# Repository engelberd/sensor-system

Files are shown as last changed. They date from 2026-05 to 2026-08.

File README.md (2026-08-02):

# sensor-system

This repository contains the full Sensor System project:

- `hardware/` for KiCad PCB projects, parts, footprints, and hardware notes
- `node/` for the Pico firmware and bootloader artifacts
- `host/` for recorder, configurator, supervisor, dashboards, and deployment files

Current product version: **0.4.1**.

For day-to-day use, see the Polish
[operator guide](docs/INSTRUKCJA-OPERATORA.md). For a new host computer, run:

```bash
./host/tools/setup_host.sh rpi-sanok
```

For a macOS KiCad, firmware and host-development workstation, follow
[the macOS setup guide](docs/SETUP-MACOS.md), install declared tools with
`brew bundle --file Brewfile`, and run `./tools/check_macos.sh`.

The generated, ignored `host/system_config.json` extends a tracked profile from
`host/configs/systems/`. Product-wide defaults live in
`host/configs/common.json`; stable channel and sensor facts live in the system
profile; device paths, storage overrides and temporary disabled channels remain
in the local overlay. See [the repository structure](docs/REPOSITORY-STRUCTURE.md)
and validate an installation with:

```bash
./hostctl doctor --config host/system_config.json
```

Release validation and publication are described in
[RELEASING.md](RELEASING.md), and notable changes are listed in
[CHANGELOG.md](CHANGELOG.md).

Local runtime output has one predictable layout:

- `var/recordings/` for new measurements
- `var/archive/` for compacted archives
- `var/log/` for host logs and events
- `var/tmp/` for temporary artifacts
- `/run/sensor-system/` for locks, commands and live status

These directories are not versioned. Use `./hostctl paths` to display the
effective paths for the active host configuration.

Every installed node has an immutable hardware revision. Revision `2` is the
currently installed wiring (SCK 14, MOSI 15, DRDY 11, INT1 10, no DE GPIO),
while revision `1` uses SCK 10, MOSI 11, DRDY 14, INT1 15 and DE on GPIO2.
Node IDs and sensor settings remain runtime configuration independent of that
revision.

## Repository Notes

In this Codex workspace the top-level `.git/` path is reserved by the
environment, so repository metadata lives in `.git-main/` and the local wrapper
`./sgit` should be used instead of plain `git`.

Suggested day-to-day workflow in this workspace:

1. Make changes locally in this repository.
2. Use `./sgit ...` for repository commands in this environment.
3. Commit before flashing or deploying to another device.
4. Push to your remote.
5. On the Raspberry Pi host, run `git pull`, build from `node/`, and flash the selected artifact.

## Local Bring-Up On A New Computer

If you are building and flashing from a local Linux or macOS machine instead of
the Raspberry Pi host:

1. Clone the repository and enter it.
2. Install the Pico SDK and toolchain.
3. Build `node/`.
4. Flash `node/build/sensor-system-node-factory.uf2` onto a brand-new Pico 2.
5. Create `host/.venv` and install host requirements.
6. Use `./hostctl config` to commission the node over RS485.

Example setup for a clean local checkout:

```bash
git clone git@github.com:engelberd/sensor-system.git
cd sensor-system
git clone https://github.com/raspberrypi/pico-sdk.git
export PICO_SDK_PATH=$PWD/pico-sdk
python3 -m venv host/.venv
host/.venv/bin/python -m pip install -r host/requirements-recorder.txt
```

The local `pico-sdk/` checkout is intentionally ignored and is not a submodule.
Each build host may keep the SDK elsewhere and point `PICO_SDK_PATH` to it.

On macOS with Homebrew, the typical firmware toolchain is:

```bash
brew install cmake picotool arm-none-eabi-gcc
```

Build the node firmware with explicit compiler paths when needed:

```bash
cmake -S node --preset board-v2 \
  -DCMAKE_C_COMPILER=/opt/homebrew/bin/arm-none-eabi-gcc \
  -DCMAKE_CXX_COMPILER=/opt/homebrew/bin/arm-none-eabi-g++ \
  -DCMAKE_ASM_COMPILER=/opt/homebrew/bin/arm-none-eabi-gcc
cmake --build node/build
```

For a V1 board use `cmake -S node --preset board-v1` followed by
`cmake --build node/build.v1`. Never reuse one build directory for both board
revisions.

The most important output files are:

- `node/build/sensor-system-node-factory.uf2` for first-time USB/BOOTSEL flashing
- `node/build/sensor-system-node.uf2` as the general full-image UF2
- `node/build/sensor-system-node-update-package.json` for later RS485 updates

Further details live in:

- [hardware/README.md](hardware/README.md)
- [node/README-bootloader.md](node/README-bootloader.md)
- [host/README-product.md](host/README-product.md)
- [host/README-deploy.md](host/README-deploy.md)

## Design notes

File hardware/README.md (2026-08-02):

# Hardware

Hardware design files for the Sensor System project.

Current KiCad project:

- `KiCad - node V2/RP2350.kicad_pro`

The directory name is historical. This is an unreleased custom-board design,
not the definition of the V2 boards installed in Sanok. Installed V2 wiring is
defined by `node/config/board_profile.h`: SCK 14, MOSI 15, MISO 12, CS 13,
DRDY 11, INT1 10 and no firmware-controlled DE pin. Do not change the firmware
revision map from the in-progress KiCad project without a physical bring-up and
an explicit new board revision.

## Repository layout

This project should stay as one GitHub repository for now:

- `hardware/` - KiCad projects, PCB notes, parts, footprints, manufacturing files
- `node/` - RP2350/Pico firmware
- `host/` - host tools, recorder, dashboards, deployment files

This is a monorepo layout. It is simpler than a nested Git repository and makes
hardware/software changes easy to review together. A separate hardware repository
or Git submodule only starts to pay off if the PCB must be shared with a different
team, licensed differently, or released on a different schedule.

## What is tracked

Track these files:

- `*.kicad_pro`
- `*.kicad_sch`
- `*.kicad_pcb`
- project-local `*.kicad_sym` files
- project-local `*.pretty/*.kicad_mod` footprint libraries
- selected 3D models used by footprints
- documentation in this directory
- released fabrication outputs in a named release folder, if needed

Do not track these files:

- `*.kicad_prl`
- `*-backups/`
- `fp-info-cache`
- local lock/temp files
- `.DS_Store`

## Collaboration rules

- Commit before making large schematic rewires or PCB placement changes.
- Pull before opening KiCad if someone else may have pushed hardware changes.
- Avoid editing the same schematic sheet or PCB placement in parallel.
- For footprint changes, edit project-local libraries first, then update the
  board from the library and commit both the library change and board change.
- Put part decisions in `parts.md` before layout, especially when package,
  stock, or footprint choice matters.
- Put JLCPCB/LCSC assembly candidates and stock checks in `jlcpcb-parts.md`.
- Put layout/manufacturing decisions in `design-notes.md`.
- Track current work, assumptions, tasks, and completed items in `progress.md`.

## Opening the project

Open this file in KiCad:

```text
hardware/KiCad - node V2/RP2350.kicad_pro
```

If a footprint is missing, first check the project-local library:

```text
hardware/KiCad - node V2/my_footprints.pretty
```

Vendor downloads and raw imported libraries can stay locally in
`footprints.extra/`, which is ignored by Git. After checking a vendor footprint,
copy the cleaned version into `my_footprints.pretty` so everyone gets the same
reviewed footprint.

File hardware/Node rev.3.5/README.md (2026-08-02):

# RP2350 ADXL355 node hardware notes

Working notes for the first custom RP2350A board with ADXL355, USB-C
development power/data, 12 V field input, RS485, and a power architecture
biased toward a clean accelerometer supply.

## Design goals

- Keep firmware changes small by staying close to Raspberry Pi Pico 2/RP2350A.
- Give ADXL355 the quietest practical supply and layout environment.
- Allow development from USB-C without a 12 V supply.
- Allow normal field operation from 12 V.
- Prevent backfeeding between USB VBUS and the 12 V/buck input.
- Keep the schematic easy to manufacture externally, even if components are small.

## Proposed power tree

```text
12V_IN
  -> input fuse/PTC
  -> TVS to GND
  -> reverse polarity protection
  -> TPS62175 buck, 12 V to 5V_BUCK

USB-C VBUS
  -> optional fuse/filter
  -> TPS2121 IN2

5V_BUCK
  -> TPS2121 IN1

TPS2121 OUT = 5V_SYS
  -> TLV75733 -> 3V3_DIG
  -> low-noise LDO -> 3V3_ADXL_PRE
      -> ferrite / 0R option -> 3V3_ADXL
```

Recommended source priority:

- `IN1`: `5V_BUCK` from 12 V, main/field source.
- `IN2`: `USB_5V`, fallback/development source.
- `OUT`: `5V_SYS`.

This means that when both 12 V and USB-C are connected, the board should run
from 12 V while USB is used for data/debug. Exact TPS2121 priority and threshold
resistors must be set from the datasheet during schematic entry.

## Candidate BOM and KiCad mapping

| Block | Candidate part | KiCad symbol | KiCad footprint |
|---|---|---|---|
| MCU | RP2350A | `MCU_RaspberryPi:RP2350A` | `Package_DFN_QFN:QFN-60-1EP_7x7mm_P0.4mm_EP3.4x3.4mm_ThermalVias` |
| QSPI flash | W25Q128JVS, 16 MiB, SOIC-8 | `Memory_Flash:W25Q128JVS` if available, otherwise import/vendor symbol | `Package_SO:SOIC-8_3.9x4.9mm_P1.27mm` |
| Accelerometer | ADXL355BEZ-RL7, LCSC C515892 | local `ADXL355BEZ` | local `E-14-1_ADI` |
| Input PTC | PTS181212V150 | `Device:Fuse` / `Device:Polyfuse` | likely `Fuse:Fuse_1812_4532Metric` or vendor footprint |
| Input TVS | SM6T12A | `Diode:TVS` | usually SMB/SMA package; verify exact package before layout |
| Reverse protection | SS14-E3/61T, LCSC C47460 | `Diode:Schottky` | usually `Diode_SMD:D_SMA` / verify exact package |
| Buck 12 V to 5 V | TPS62175DQCR, LCSC C32097 | `Regulator_Switching:TPS62175DQC` | use TI DQC/VSON-10 footprint; verify against datasheet |
| Power mux | TPS2121RUXR, LCSC C485916 | local `TPS2121RUXR` | local `RUX0012A` |
| 3V3_DIG LDO | TLV75733 | `Regulator_Linear:TLV75733PDBV` or package-specific variant | `Package_TO_SOT_SMD:SOT-23-5` for DBV variant |
| 3V3_DIG alternative | AP2112K-3.3 | `Regulator_Linear:AP2112K-3.3` | `Package_TO_SOT_SMD:SOT-23-5` |
| 3V3_ADXL LDO | TPS7A2033 or ADP150-3.3 | `Regulator_Linear:TPS7A20xxxDBV` or imported ADP150 | `Package_TO_SOT_SMD:SOT-23-5` or exact vendor package |
| ADXL supply filter | MPZ2012S601AT000, 600R @ 100 MHz, 0805 | `Device:Ferrite_Bead` | `Inductor_SMD:L_0805_2012Metric` |
| RS485 TVS | CDSOT23-SM712 | `Diode:SM712_SOT23` | `Package_TO_SOT_SMD:SOT-23` |
| RS485 transceiver | THVD1450DR | `Interface_UART:THVD1450DR` | `Package_SO:SOIC-8_3.9x4.9mm_P1.27mm` |
| USB ESD | USBLC6-2SC6 or TPD2EUSB30 | `Power_Protection:USBLC6-2SC6` / `Power_Protection:TPD2EUSB30` | package-specific SOT-23-6 / X2SON, verify selected part |
| USB-C connector | select exact vertical USB-C part | `Connector:USB_C_Receptacle_USB2.0_16P` | select exact manufacturer footprint |

Local downloaded libraries already found:

```text
ADXL355 symbol:
/Users/anone/Downloads/ul_ADXL355BEZ/KiCADv6/2026-05-26_12-26-55.kicad_sym

ADXL355 footprints:
/Users/anone/Downloads/ul_ADXL355BEZ/KiCADv6/footprints.pretty/E-14-1_ADI.kicad_mod
/Users/anone/Downloads/ul_ADXL355BEZ/KiCADv6/footprints.pretty/E-14-1_ADI-L.kicad_mod
/Users/anone/Downloads/ul_ADXL355BEZ/KiCADv6/footprints.pretty/E-14-1_ADI-M.kicad_mod

TPS2121 symbol:
/Users/anone/Downloads/ul_TPS2121RUXR/KiCADv6/2026-05-26_13-55-57.kicad_sym

TPS2121 footprint:
/Users/anone/Downloads/ul_TPS2121RUXR/KiCADv6/footprints.pretty/RUX0012A.kicad_mod
```

## Input power schematic notes

Initial 12 V input chain:

```text
J_PWR.1 = +12V_IN_RAW
J_PWR.2 = GND

+12V_IN_RAW -> F1 PTC -> +12V_PROT
+12V_PROT -> D_TVS -> GND
+12V_PROT -> D_REV Schottky series -> +12V_SAFE
+12V_SAFE -> TPS62175 VIN
```

Notes:

- `PTS181212V150` is acceptable for a controlled 12 V lab input, but consider a
  higher voltage-rated fuse/PTC for field or industrial-style inputs.
- `SM6T12A` is aggressive for nominal 12 V. It is fine for a well-controlled
  12 V adapter, but for systems that can sit above 12 V, consider a 15 V or
  18 V working-voltage TVS while keeping the TPS62175 28 V input limit safe.
- `SS14` as a series reverse-protection diode is simple and acceptable for V1.
  A P-MOS/ideal-diode style reverse protector would reduce voltage drop and heat.

## Buck notes: TPS62175DQCR

Target output: `5V_BUCK`.

Required schematic items:

- VIN input ceramic capacitor close to VIN/GND.
- Additional optional bulk capacitor footprint near the protected 12 V input.
- Inductor from SW to `5V_BUCK`, selected from TPS62175 datasheet guidance.
- Output capacitor close to inductor/output return.
- Feedback divider for 5 V output.
- EN tied to `+12V_SAFE` or configured with UVLO if desired.
- PG routed to a testpoint or left according to datasheet recommendation.
- Testpoint on `5V_BUCK`.

Layout priority:

- Keep the buck hot loop tiny.
- Keep SW copper small and away from ADXL355.
- Place buck, inductor, and high-current input/output caps away from the
  accelerometer side of the board.

## USB-C and power mux notes

USB-C development connector:

```text
VBUS -> USB_5V
GND  -> GND
CC1  -> 5.1k -> GND
CC2  -> 5.1k -> GND
D+   -> USB ESD -> RP2350 USB_DP
D-   -> USB ESD -> RP2350 USB_DM
```

Power mux:

```text
TPS2121 IN1 <- 5V_BUCK
TPS2121 IN2 <- USB_5V
TPS2121 OUT -> 5V_SYS
TPS2121 GND -> GND
```

Do not leave TPS2121 control pins floating. Configure:

- priority / mode selection,
- input overvoltage thresholds,
- current limit,
- status output if useful.

Exact resistor values should be calculated directly from the TPS2121 datasheet.

## 3.3 V rails

Digital rail:

```text
5V_SYS -> TLV75733 -> 3V3_DIG
```

`3V3_DIG` powers:

- RP2350A I/O and support circuitry,
- W25Q128JVS flash,
- RS485 transceiver logic supply,
- status LED,
- digital pull-ups and test circuitry.

Analog/accelerometer rail:

```text
5V_SYS -> low-noise LDO -> 3V3_ADXL_PRE
3V3_ADXL_PRE -> MPZ2012S601AT000 / 0R option -> 3V3_ADXL
3V3_ADXL -> ADXL355 VDD and VDDIO
```

Recommendation:

- Use TLV75733 for `3V3_DIG`.
- Use a low-noise LDO such as TPS7A2033 or ADP150-3.3 for `3V3_ADXL`.
- Keep the ferrite footprint, but make it replaceable by 0R in case the filter
  resonates with ceramic capacitors or is unnecessary.

## Unreleased custom-board pin plan

Despite the historical directory name, this in-progress schematic is not the
source of truth for the V2 boards installed in Sanok. The installed V2 pin map
is maintained in `node/config/board_profile.h`.

Keep the first custom board close to the current firmware pinout.

ADXL355 SPI:

```text
SCK  -> GPIO10
MOSI -> GPIO11
MISO -> GPIO12
CS   -> GPIO13
DRDY -> GPIO14
INT1 -> GPIO15
```

RS485:

```text
UART TX -> GPIO0
UART RX -> GPIO1
DE      -> GPIO2
```

This minimizes firmware changes during bring-up.

## ADXL355 layout notes

- Place ADXL355 away from the buck inductor, SW node, USB connector, and RS485
  cable connector.
- Do not route fast digital traces under the sensor.
- Keep SPI traces short and calm; avoid unnecessarily high drive strength.
- Put local decoupling very close to ADXL355 supply pins.
- Keep a continuous ground plane under and around the sensor area.
- Consider mechanical placement early: the accelerometer measures the board and
  mounting structure, not just the electrical design.

## RS485 notes

Basic RS485 block:

```text
3V3_DIG -> THVD1450DR VCC
RP2350 UART_TX -> D
RP2350 UART_RX <- R
RP2350 GPIO_DE -> DE and /RE control as desired
A/B -> connector
A/B -> CDSOT23-SM712 -> GND
Optional 120R termination across A/B via jumper or DNP resistor
Optional failsafe bias resistor footprints if needed
```

Use `3V3_DIG`, not `3V3_ADXL`, for RS485.

## Items to verify before PCB release

- RP2350A footprint and exposed pad dimensions against the current Raspberry Pi
  hardware design files.
- ADXL355 land pattern against Analog Devices package drawing.
- Exact USB-C vertical connector part and matching footprint.
- TPS62175 DQC footprint and feedback/inductor/capacitor values.
- TPS2121 resistor configuration for priority, input thresholds, and current limit.
- Flash footprint/package for the selected W25Q128JVS ordering suffix.
- TVS working voltage against real 12 V input tolerance.
- Whether the field input should tolerate 24 V mistakes or only regulated 12 V.

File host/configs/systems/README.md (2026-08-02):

# Shared system profiles

Each tracked file in this directory describes one physical installation and
extends `../common.json`. Keep stable, non-secret facts here: channel names,
sensor settings, board revisions and expected baud rates.

A profile may have a companion Markdown file for installation-specific context
such as required external drivers, converter hardware and maintenance notes.

Do not put device paths, usernames, absolute storage paths, credentials or
temporary enable/disable decisions here. Those belong in the ignored
`host/system_config.json` on each host.

When adding a system, copy `system.example.json`, choose a stable lowercase
name, and commit the new profile so all hosts and Codex sessions share the same
source of truth.

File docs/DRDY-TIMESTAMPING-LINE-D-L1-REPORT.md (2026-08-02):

# Raport L1 timestampingu — linia D, node 1

Data: 2026-07-27
System: testowy
Zakres: jeden ADXL355, `/dev/ttyCH9344USB3`, node `1`

## Konfiguracja i obraz

- profil sprzętowy: historycznie `legacy_eval`, obecnie `board_v2`;
- piny: DRDY GPIO11, INT1 GPIO10, SPI1 GPIO12–15;
- sensor ODR: 250 Hz;
- output ODR po FIR x2: 125 Hz;
- firmware przed testem: v0.3.9;
- firmware po teście: v0.3.10, timestamping v2 ON;
- capabilities: wersja 1, Burst max 2, flags `0x0F`, 32 próbki/pakiet;
- aktywny obraz końcowy: slot B.

SHA-256 końcowych artefaktów:

- slot A:
  `cd9e885325f10a1e88e76d6d93b79bb34e77ccb56b05869423ac9ca63a240b6d`;
- slot B:
  `cced6a11a145f7f4153a01b25d4e4a3917f2015f9a1f9cdafe6f37af1ccf5c43`;
- manifest:
  `cee951c47236d5f4a4565ff5ed7bc94ceb70f3fa900116d8d0dc7497aa8b6212`.

## TimeSync

Model uzyskał `LOCKED` po pięciu obserwacjach. W krótkiej próbie:

- slope device→host: 999,988 ns/µs;
- różnica względem ideału: około −12 ppm;
- RTT pojedynczego odpytywania: około 30–50 ms;
- maksymalna niepewność zapisana w kotwicach: 15,8 ms;
- jedna stabilna `boot_epoch` w każdym przebiegu.

## Test observe — 120 s

Artefakt:
`runs/manual-tests/line-d-timing-observe/2026-07-27/`

- 14 976 próbek;
- 468 kotwic;
- 8 obserwacji synchronizacji;
- sequence bez przerw;
- zero gapów, nowych strat, overflow ringa i recovery podczas sesji;
- jedna epoka i jeden stabilny segment (`3`);
- okres próbki: min 8000,065 µs, średnio 8000,581 µs,
  max 8001,097 µs;
- HDF5 schema 5, `complete=true`.

## Test required — 90 s

Artefakty:
`runs/manual-tests/line-d-timing-required/`

- 11 264 próbki łącznie, sequence bez przerw;
- 2 560 początkowych próbek bez locka w trwałej kwarantannie `unsynced`;
- 8 704 zsynchronizowane próbki w zwykłym oknie 22:50–23:00;
- 272/272 kotwice zwykłego okna mają UTC akwizycji;
- oba HDF5 mają schema 5 i `complete=true`;
- zero gapów i nowych strat podczas sesji.

Tryb `required` został rozszerzony o osobne pliki kwarantanny dla:

- `unsynced` — brak pewnego mapowania UTC;
- `ambiguous` — przedział niepewności przecina granicę okna;
- `late` — okno zostało już sfinalizowane.

Próbki z tych kategorii nie trafiają arbitralnie do zwykłych okien, ale po
trwałym zapisie mogą zostać bezpiecznie commitowane do noda.

## Obserwacja wymagająca dalszego testu

Po każdym restarcie noda bariera fail-closed odrzucała 10–15 próbek i
wykonywała 1–2 recovery, po czym utrzymywała stabilny segment bez dalszego
wzrostu liczników. Próba zmiany kolejności uzbrajania IRQ i jawnego czyszczenia
FIFO nie poprawiła wyniku, dlatego została cofnięta.

Nie znaleziono utraty danych po wejściu w stabilny segment, ale przed rolloutem
na kolejne nody należy zarejestrować DRDY, INT1 i transakcje FIFO analizatorem
logicznym podczas pierwszych sekund startu. Do tego czasu startowy warm-up jest
jawnie kwarantannowany przez firmware i host.

## Wynik

L1 dla pojedynczego noda: warunkowo pozytywny.

- Burst v2, TimeSync, modele zegara, `observe`, `required`, HDF5 v5,
  deduplikacja i kwarantanna działają na rzeczywistym czujniku.
- Nie rozszerzać rollout’u na kolejne nody przed analizą startowego recovery.

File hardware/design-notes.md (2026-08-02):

# Hardware design notes

## Current direction

Custom RP2350A node with:

- ADXL355 accelerometer over SPI
- RS485 field bus
- USB-C development power/data
- 12 V field input
- 12 V to 5 V buck, followed by 5 V source muxing and 3.3 V rails

## Power tree

```text
12V_IN
  -> fuse/PTC
  -> TVS
  -> reverse protection
  -> TPS62175 buck -> 5V_BUCK

USB_C_VBUS -> USB_5V

5V_BUCK -> TPS2121 IN1
USB_5V  -> TPS2121 IN2
TPS2121 OUT -> 5V_SYS

5V_SYS -> TLV75733 -> 3V3_DIG
5V_SYS -> low-noise LDO -> 3V3_ADXL_PRE -> ferrite/0R -> 3V3_ADXL
```

Preferred TPS2121 behavior: 12 V/buck source has priority when both field power
and USB are connected. USB remains useful for data/debug.

## Unreleased custom-board pin plan

This plan belongs to the in-progress custom KiCad design. It is not the pin map
of the installed V2 boards; see `node/config/board_profile.h` for released
firmware profiles.

ADXL355 SPI:

```text
SCK  -> GPIO10
MOSI -> GPIO11
MISO -> GPIO12
CS   -> GPIO13
DRDY -> GPIO14
INT1 -> GPIO15
```

RS485:

```text
UART TX -> GPIO0
UART RX -> GPIO1
DE      -> GPIO2
```

## Layout priorities

- Put ADXL355 away from the buck inductor, SW node, USB connector, and RS485
  connector.
- Do not route fast digital traces under the accelerometer.
- Keep a continuous ground plane around the sensor area.
- Keep buck hot loops very small.
- Keep SW copper small and away from the analog/sensor side.
- Put local decoupling close to every power pin, especially ADXL355 and RP2350.
- Put RS485 TVS near the cable connector.

## Release checks

- RP2350A footprint verified against current Raspberry Pi hardware files.
- ADXL355 footprint verified against Analog Devices package drawing.
- USB-C connector footprint verified against manufacturer drawing.
- TPS62175 feedback, inductor, input/output caps calculated from datasheet.
- TPS2121 priority, threshold, and current-limit resistors calculated.
- Flash ordering suffix, symbol, and footprint match.
- 12 V TVS working voltage matches real supply tolerance.
- PCB manufacturer stackup and minimum rules entered into KiCad.

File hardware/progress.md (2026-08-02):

# Hardware progress

This is the shared status page for the KiCad hardware work. Keep it short and
update it in the same commit as the schematic/layout change.

## Current goal

Bring up the first RP2350A + ADXL355 node PCB with USB-C development access,
12 V field power, RS485, and clean accelerometer supply.

## Board status

Status: `schematic/layout in progress`

The historical `KiCad - node V2` directory is an unreleased custom design and
must not be confused with the installed V2 board revision used by firmware.

| Area | Status | Notes |
|---|---:|---|
| Architecture | in progress | Power tree, sensor, RS485, USB-C direction documented. |
| Part selection | in progress | Main candidates listed in `parts.md`; several footprints still need verification. |
| Schematic | in progress | KiCad project exists in `KiCad - node V2/`. |
| PCB layout | in progress | Board file exists; release checks still open. |
| ERC/DRC | todo | Run before every PCB release candidate. |
| Manufacturing export | todo | Create only after ERC/DRC and footprint checks pass. |
| Bring-up plan | todo | Add test points, power-up order, and first-flash procedure before ordering. |

## Assumptions

- Repository stays as one monorepo with `hardware/`, `node/`, and `host/`.
- Project-local footprints in `my_footprints.pretty/` are the shared source for
  non-standard footprints.
- Raw vendor downloads in `footprints.extra/` are local scratch material and are
  ignored by Git.
- First board revision prioritizes bring-up and debug access over minimum size.
- Firmware pinout should stay close to the existing node firmware where possible.

## Decisions

| Date | Decision | Reason |
|---|---|---|
| 2026-05-30 | Use monorepo layout instead of nested hardware Git repo. | Easier combined hardware/software review and fewer submodule problems. |
| 2026-05-30 | Track KiCad source files and cleaned project-local footprints. | Everyone opens the same project with the same footprint library. |
| 2026-05-30 | Ignore KiCad backups, local project state, and raw vendor imports. | Keeps commits reviewable and avoids machine-local noise. |
| 2026-05-30 | Track concrete JLCPCB/LCSC sourcing in `jlcpcb-parts.md`. | Keeps stock-sensitive decisions separate from general design notes. |

## To do

| Priority | Task | Owner | Notes |
|---:|---|---|---|
| P0 | Verify RP2350A QFN footprint against Raspberry Pi hardware files. | TBD | Required before PCB release. |
| P0 | Verify ADXL355 footprint/package choice. | TBD | Pick `E-14-1_ADI`, `E-14-1_ADI-M`, or another verified footprint. |
| P0 | Calculate TPS62175 feedback, inductor, and capacitor values. | TBD | Use datasheet values; document result in `parts.md` or schematic notes. |
| P0 | Calculate TPS2121 priority, threshold, and current-limit resistors. | TBD | Do not leave control pins floating. |
| P0 | Verify USB-C connector footprint and exact MPN. | TBD | Mechanical fit and stock matter. |
| P0 | Finalize JLCPCB/LCSC part numbers for every assembled BOM row. | TBD | Start from `jlcpcb-parts.md`; stock must be re-checked before order. |
| P1 | Add/verify test points for `12V_IN`, `5V_BUCK`, `5V_SYS`, `3V3_DIG`, `3V3_ADXL`, SWD, UART/RS485. | TBD | Helps bring-up a lot. |
| P1 | Run KiCad ERC and fix release-blocking errors. | TBD | Record result below. |
| P1 | Run KiCad DRC and fix release-blocking errors. | TBD | Record result below. |
| P1 | Add bring-up checklist. | TBD | Include first power-up current limit and rail checks. |
| P2 | Prepare release export folder naming convention. | TBD | See `kicad-git-workflow.md`. |

## Done

| Date | Item |
|---|---|
| 2026-05-30 | Added hardware documentation structure. |
| 2026-05-30 | Added KiCad Git ignore rules. |
| 2026-05-30 | Added shared parts/footprint table. |
| 2026-05-30 | Added KiCad collaboration workflow. |
| 2026-05-30 | Added first JLCPCB critical-parts shortlist. |

## Open risks

| Risk | Impact | Mitigation |
|---|---|---|
| Wrong footprint for RP2350A, ADXL355, TPS2121, USB-C, or buck regulator. | Board may be unbuildable. | Verify against datasheets before release. |
| 12 V input protection too aggressive or too weak. | Nuisance clamping or damaged input stage. | Decide real input tolerance and choose TVS accordingly. |
| Buck noise coupling into ADXL355. | Poor accelerometer measurements. | Keep buck away from sensor, route carefully, preserve analog rail filtering option. |
| KiCad parallel edits conflict. | Lost time resolving schematic/PCB changes. | Pull before editing and keep commits small. |

## Verification log

| Date | Check | Result | Notes |
|---|---|---|---|
| TBD | ERC | todo | |
| TBD | DRC | todo | |
| TBD | Footprint review | todo | |
| TBD | Manufacturing export review | todo | |

## Next step

Verify critical footprints and power component resistor/value calculations before
spending more time on final PCB routing.

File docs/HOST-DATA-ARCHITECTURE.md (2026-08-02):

# Host data architecture

## Purpose

The host has two deliberately different persistence products:

- **Capture** is the crash-safe, diagnostic recording retained for 30 days.
- **Archive** is the compact, validated measurement record retained long-term.

Derived products such as resampled or cross-sensor synchronized data are not
source records and can always be rebuilt from Archive data.

## Identity

Until permanent hardware identifiers are commissioned, transport channels are
numbered `1` through `8` and their attached sensors are labelled `A` through
`H`. A transport `node_address` is not a sensor identity. The data model keeps
`channel_id`, `sensor_label`, future `sensor_id`, and `node_address` separate.

## Dependency rule

The capture code is split into the following layers:

1. `host.recorder.model` defines records and runtime state. It does not know a
   file format or windowing policy.
2. `host.recorder.decoder` translates the wire representation into domain
   records. It does not write files.
3. `host.recorder.ports` defines the output contract consumed by the recorder.
4. `host.recorder.capture_v1` serializes the canonical Capture v1 journal.
   Legacy v5 serialization remains isolated in `capture_writers` during the
   staged rollout.
5. `host.recorder.capture_windowing` owns exact-once UTC-window routing and
   atomic publication for Capture v1. Legacy routing remains isolated in
   `windowing` during the staged rollout.
6. `host.recorder.capture_reader` validates and reads sealed Capture files.
7. `host.recorder.archive_v1` performs offline, deterministic compaction and
   `host.recorder.archive_reader` validates the published Archive product.
8. `host.host_recorder` is the application composition root and owns the
   protocol loop and operational lifecycle.

Dependencies point toward the model and ports. Infrastructure modules must not
import the recorder application entrypoint.

## Capture invariants

- Samples are identified by `(boot_epoch, sample_seq)`.
- A committed sample is not duplicated within one Capture file.
- An ingest batch is published only after its samples and timing anchors are
  flushed.
- Active output uses `.partial`; publication sets `complete=true`, flushes,
  closes, and atomically renames the file.
- Timing uncertainty is data, not a hard-coded system-wide constant.
- Physical sensor loss, logical sequence gaps, transport diagnostics, and time
  uncertainty are separate concepts.

## Archive boundary

Archive conversion operates only on sealed Capture files. It must be
idempotent, preserve measurement values exactly, account for every input sample
exactly once, record gaps and quality intervals, and publish a checksum-backed
manifest. Capture deletion is a separate retention decision and is never part
of conversion.

The first Archive implementation will be a single daily local process. Storage
backends and automatic deletion remain outside the conversion domain so a local
disk, mounted SSD, or remote storage can be selected later.

The offline command is:

```text
./hostctl archive --day YYYY-MM-DD --output DAY.archive.h5 CAPTURE...
```

It refuses incomplete, invalid, unresolved, wrong-day, mixed-sensor, and
duplicate sample inputs. Publication produces both an atomically renamed HDF5
file and a SHA-256 sidecar. It never deletes Capture inputs.

## Rollout gate

`storage.capture_schema` remains explicitly set to `5` in the live system
configuration until firmware v0.4 reports the complete configuration contract
and a real Capture v1 trial passes. Switching it to `1` is a deliberate rollout
operation, not an automatic side effect of installing host code. A Capture v1
worker refuses firmware that reports an unknown filter profile or configuration
revision, so partial upgrades fail closed.

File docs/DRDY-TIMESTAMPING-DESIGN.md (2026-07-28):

# Projekt deterministycznego czasu próbek DRDY

Status: zaimplementowany i zweryfikowany offline; rollout sprzętowy oczekuje
Zakres: firmware noda, protokół RS485 i recorder HDF5
Poza zakresem: programowanie urządzenia, operacje na portach i usługach produkcyjnych

## 1. Decyzje i założenia

1. Źródłem czasu próbki surowej jest zbocze `DRDY` zarejestrowane przez
   `time_us_64()` na RP2350.
2. Czas próbki po symetrycznym filtrze FIR x2 jest czasem wejścia leżącego pod
   środkowym współczynnikiem filtra. Nie jest to czas odczytu FIFO ani czas
   ostatniego wejścia filtra.
3. Każdy zakolejkowany pakiet przechowuje niezmienny blok czasu. Retransmisja
   wysyła te same bajty, łącznie z identyfikatorem epoki i czasami.
4. Nie zakładamy, że nominalny ODR jest idealny. Z kolejnych par
   `(sample_seq, device_time_us)` estymujemy rzeczywisty okres próbkowania oraz
   jego dryft. Pakiet nie zawiera timestampu ani delty dla każdej próbki.
5. Host mapuje czas monotoniczny noda na UTC osobnym protokołem synchronizacji.
   `GetStats` pozostaje wyłącznie diagnostyką.
6. Okna HDF5 są półotwarte `[start, end)`, aktywne pliki mają rozszerzenie
   `.partial`, a kompletne pliki są publikowane atomowym `rename`.
7. Format czasowy jest nową, jawną wersją protokołu. Host produkcyjny nie może
   cicho zaakceptować pakietu bez czasu.

## 2. Weryfikacja sprzętu

Repozytorium zawiera spójne wskazanie dla projektowanej płytki custom V2:

- `hardware/design-notes.md`: `DRDY -> GPIO14`, `INT1 -> GPIO15`;
- `hardware/KiCad - node V2/README.md`: ta sama mapa;
- schemat i PCB zawierają sieci `ADXL_DRDY` oraz `ADXL_INT1`;
- `node/main.cpp` po commicie `686d770` używa `GPIO14` i `GPIO15`.

Nie jest to jednak dowód konfiguracji każdego istniejącego noda. Dokumentacja
starszej wiązki ewaluacyjnej (`node/README-bootloader.md` i generator pakietu
release) nadal podaje `DRDY -> GPIO11`, `INT1 -> GPIO10`. Implementacja musi
wydzielić mapę płytki do jawnego profilu build/config i nie może zostać
uruchomiona na urządzeniu przed potwierdzeniem wariantu sprzętowego operatora.

## 3. Przepływ czasu

```text
ADXL355 DRDY
  -> ISR GPIO: {event_seq, device_time_us}
  -> ograniczony SPSC ring timestampów
  -> binder FIFO: surowa próbka <-> kolejne zdarzenie DRDY
  -> FIR x2: wynik + czas środkowego wejścia filtra
  -> model sample clock: device_time_us = a * sample_seq + b
  -> staging DataPlane (32 próbki)
  -> wersjonowany pakiet: XYZ + epoka + dwie kotwice + jakość modelu
  -> kolejka pakietów (niezmienne bajty)
  -> RS485 grant/burst/retransmisja
  -> parser hosta
  -> model device monotonic -> host monotonic -> UTC
  -> podział pakietu po UTC na okna [start, end)
  -> /nodes/<id>/{samples,time_anchors,clock_sync,gaps}
  -> flush, finalizacja metadanych, rename .partial -> .h5
```

Transport ma własne czasy `t1..t4`, ale nie modyfikuje czasu próbki.

## 4. Przechwytywanie DRDY i wiązanie z FIFO

### 4.1 Ring timestampów

ISR wykonuje tylko:

1. `time_us_64()`;
2. inkrementację `event_seq`;
3. zapis `{event_seq, device_time_us}` do SPSC ringa;
4. ustawienie zatrzaskowej flagi overflow, jeżeli ring jest pełny.

ISR nie wykonuje SPI, alokacji, formatowania tekstu ani logowania. Producentem
ringa jest IRQ na core 0, konsumentem `AcquisitionEngine` na tym samym rdzeniu.
Indeksy są atomowe lub chronione minimalną sekcją IRQ; nie używamy blokującego
mutexa w ISR.

Zaimplementowana pojemność to 512 wpisów. Ring ma compile-time limit i testy
overflow/wrap; rzeczywisty margines czasowy zależy od ODR i pozostaje bramką
testu laboratoryjnego przed włączeniem funkcji na urządzeniu.

### 4.2 Stan bindera

Binder ma stany:

- `UNSYNCED` — brak bezpiecznego powiązania;
- `LOCKED` — liczba i kolejność zdarzeń odpowiadają odczytom FIFO;
- `DEGRADED` — czasy istnieją, ale wykryto zdarzenie obniżające jakość;
- `INVALID` — utracono jednoznaczność segmentu.

Przy wejściu w measurement mode ring jest zerowany, zwiększany jest
`timing_segment_id`, a binder czeka na pierwsze zweryfikowane zdarzenia.
Odczyt N kompletnych próbek XYZ z FIFO konsumuje N najstarszych oczekujących
zdarzeń DRDY. Kilka odczytów po jednym IRQ działa identycznie: INT1 tylko
uruchamia obsługę FIFO, a DRDY numeruje faktyczne próbki.

Warunki jakości:

| Zdarzenie | Zachowanie |
|---|---|
| Pełna partia, N zdarzeń dostępnych | przypisanie 1:1, `LOCKED` |
| Polling fallback, zdarzenia kompletne | przypisanie 1:1, `LOCKED` |
| Za mało zdarzeń DRDY | segment `INVALID`, brak ekstrapolacji |
| Nadmiar zdarzeń względem stanu FIFO | segment `INVALID`, reset bindera |
| Ring overflow | segment `INVALID`, licznik i gap jakości |
| FIFO overrun lub niepewna strata | segment `INVALID`, nowe wiązanie |
| Niepełne/odrzucone XYZ | odpowiadający czas jest odrzucany; segment kończy się |
| Soft recovery/reinit/zmiana ODR | nowy `timing_segment_id`, warm-up od zera |
| Reset noda | nowa `boot_epoch`; stary model hosta jest niedozwolony |

Po `INVALID` dane mogą być transportowane wyłącznie z jawną jakością
`INVALID`; domyślny recorder zapisuje je do `gaps`/kwarantanny, a nie do
kompletnego okna pomiarowego. Nowy segment nie musi przenosić każdego zdarzenia
DRDY dalej: zachowuje okresowe punkty kotwiczące potrzebne do dopasowania
lokalnego zegara próbek.

### 4.3 Włączenie DRDY

Obecne `configure_fifo()` jawnie wywołuje `set_drdy_enabled_internal(false)` i
uruchamia tylko IRQ INT1. Implementacja zmieni to dla profilu sprzętowego z
potwierdzonym DRDY:

- DRDY włączone w `POWER_CTL`;
- IRQ DRDY na właściwym GPIO;
- INT1 nadal sygnalizuje watermark/overrun i uruchamia odczyt FIFO;
- oba źródła mają oddzielne liczniki i semantykę.

## 5. Semantyka czasu po filtrze

Wszystkie trzy profile używają symetrycznych filtrów FIR o nieparzystej liczbie
tapów. Reprezentatywny czas wyjścia jest czasem wejścia:

```text
center = (tap_count - 1) / 2
output_time = timestamp wejścia pod współczynnikiem coefficients[center]
```

Opóźnienie względem najnowszego wejścia użytego do wyniku:

| Profil | Tapy | Opóźnienie grupowe w surowych próbkach | Przy 250 Hz |
|---|---:|---:|---:|
| Light | 15 | 7 | 28 ms |
| Balanced | 31 | 15 | 60 ms |
| Aggressive | 63 | 31 | 124 ms |

Faza decymatora pozostaje deterministyczna po `reset()`. Dla obecnej
implementacji pierwszy wynik powstaje po odpowiednio 16, 32 i 64 wejściach,
ale jego czas pochodzi ze środkowego wejścia aktywnego okna FIR, a nie z chwili
wywołania `process()`.

Filtr dostanie równoległy ring znaczników czasu albo generyczny rekord
`{AccelSample, SampleTimeTag}`. Testy obejmą impuls w każdym profilu, znane
nieregularne timestampy, reset oraz zgodność fazy x2.

Identyfikator metadanych: `fir_x2_symmetric_v1`; osobno zapisujemy profil,
liczbę tapów, decymację i opóźnienie grupowe.

## 6. Reprezentacja w pamięci noda

Nie rozszerzamy 8192-elementowego `AcquisitionBuffer<StoredSample>` o pełny
timestamp: dodałoby to co najmniej 64 KiB RAM i bufor ten nie jest źródłem
pakietów retransmisyjnych.

Zamiast tego:

- `StoredSample` pozostaje rekordem XYZ/sequence dla historycznego bufora;
- filtr zwraca czas reprezentatywnego wejścia razem z wynikiem;
- lekki model sample clock konsumuje pary `(sample_seq, device_time_us)`;
- DataPlane dołącza do pakietu endpointy i snapshot jakości bieżącego segmentu;
- po utworzeniu pakietu niezmienny blok czasu znajduje się w payloadzie kolejki
  i jest zachowany przy retransmisji.

Kotwica nie musi istnieć w każdej przechowywanej próbce. DataPlane otrzymuje ją
razem z batchami wyjściowymi albo przez oddzielny, wersjonowany snapshot modelu.
Unikamy w ten sposób dublowania pełnych timestampów w dużym buforze akwizycji.

## 7. Format pakietu danych v2

Wszystkie pola wielobajtowe są little-endian. Struktura jest pakowana i ma
`static_assert(sizeof(...))`.

```text
BurstDataPayloadPrefix:
  u8  command
  u8  status
  u32 packet_seq
  u64 first_sample_seq
  u16 sample_count
  u8  sample_encoding = RAW_XYZ24_TIME_V2

BurstTimingExtensionV2:
  u8  timing_format_version = 2
  u8  timestamp_source = DRDY_TIME_US_64
  u16 timestamp_quality
  u64 boot_epoch
  u32 timing_segment_id
  u64 first_device_time_us
  u64 last_device_time_us
  u32 sample_period_q16_us
  u32 max_fit_residual_us

payload:
  XYZ24[sample_count]
```

Pierwsza kotwica wskazuje `first_sample_seq`, druga
`first_sample_seq + sample_count - 1`. DataPlane wylicza także maksymalną resztę
czasów próbek pośrednich względem prostej endpointów. `sample_period_q16_us`
jest estymowany z DRDY, a nie kopiowany bezwarunkowo z nominalnego ODR; obsługuje
pakiet jednoelementowy i kontrolę spójności. Parser odrzuca zerowy okres,
niepasującą epokę, cofnięcie czasu oraz model o jakości `INVALID`.

Stary 17-bajtowy prefiks pozostaje bez zmian. Stary host rozpoznaje nieznane
`sample_encoding` i odrzuca v2 zamiast przesunąć offset XYZ. Rozszerzenie nie
ma narzutu zależnego od liczby próbek i pozostaje wyraźnie mniejsze od pełnego
timestampu przy każdym XYZ. Dokładny
wpływ na przepustowość RS485 należy zmierzyć w teście symulowanym i
laboratoryjnym przed wdrożeniem.

Stary host odrzuca nowe `sample_encoding`; nowy host:

- w trybie produkcyjnym wymaga v2;
- może przyjąć v1 wyłącznie z jawną opcją migracyjną i oznacza czas
  `UNSYNCED`, bez publikowania kompletnego pliku czasowego.

## 8. Epoka noda

`boot_epoch` jest 64-bitowym nonce generowanym raz przy starcie z generatora
sprzętowego RP2350/Pico SDK. Generator jest wstrzykiwalny w testach. Wartość
zero jest niedozwolona.

Host kluczuje wszystkie modele i deduplikację przez `(node_id, boot_epoch)`.
Zmiana epoki natychmiast:

- zamyka poprzedni model bez interpolacji;
- zeruje kandydatów synchronizacji;
- ustawia stan `UNSYNCED`;
- tworzy zdarzenie restartu/gap.

Rollback `device_time_us` w tej samej epoce jest błędem `INVALID`, nie wrapem.

## 9. Synchronizacja noda z hostem

Dodajemy osobną komendę `TimeSyncV1`.

```text
request:
  u8  command
  u8  version = 1
  u32 sync_id
  u64 t1_host_monotonic_ns

response:
  u8  command
  u8  status
  u8  version = 1
  u32 sync_id
  u64 boot_epoch
  u64 echoed_t1_host_monotonic_ns
  u64 t2_node_rx_us
  u64 t3_node_tx_us
```

`t2` jest chwytane przy odebraniu i zweryfikowaniu ramki, przed kolejką komend.
`t3` jest chwytane bezpośrednio przed przekazaniem odpowiedzi do UART. Host
chwyta `t4_host_monotonic_ns` natychmiast po odebraniu kompletnej poprawnej
ramki. Razem z `t1` zapisuje też parę korelacyjną
`(host_monotonic_ns, host_utc_ns)` pobraną możliwie blisko wysłania.

Dla obserwacji:

```text
node_mid_us = (t2 + t3) / 2
host_mid_ns = (t1 + t4) / 2
rtt_ns = (t4 - t1) - (t3 - t2) * 1000
```

Model ma postać:

```text
host_monotonic_ns = slope_ns_per_us * device_time_us + intercept_ns
utc_ns = host_monotonic_ns + wallclock_correlation_offset_ns
```

Host zachowuje surowe obserwacje. Z ruchomego zbioru wybiera dolny kwantyl RTT,
a następnie stosuje ważoną regresję liniową dla offsetu i dryftu. Odrzuca
ujemny RTT, cofnięcie zegara, zmianę epoki i obserwacje odstające. Niepewność
obejmuje co najmniej połowę RTT, resztę regresji, wiek modelu i niepewność
korelacji monotonic/UTC.

Stany:

- `UNSYNCED`: brak wystarczających obserwacji;
- `LOCKED`: co najmniej 5 dobrych obserwacji, ograniczony residual i wiek;
- `HOLDOVER`: brak świeżej obserwacji, ale model nie przekroczył limitu wieku;
- `INVALID`: reset, niespójność lub przekroczona niepewność.

Początkowo synchronizacja co 5 s do uzyskania `LOCKED`, następnie co 30 s.
`GetStats` domyślnie co 30–60 s i dodatkowo po anomalii.

## 10. Podział na okna

Parser odtwarza `device_time_us` każdej próbki z endpointów pakietu. Dla
`sample_count >= 2`:

```text
device_time_us =
    first_device_time_us
    + (sample_seq - first_sample_seq)
      * (last_device_time_us - first_device_time_us)
      / (sample_count - 1)
```

Niepewność rośnie z odległością od kotwicy i uwzględnia reszty dopasowania
DRDY. Pole `sample_period_q16_us` obsługuje pakiet jednoelementowy i waliduje
endpointy. Model zegara wylicza UTC i przed zapisem przypisuje:

```text
window_index = floor(utc_ns / window_ns)
window_start = window_index * window_ns
window_start <= utc_ns < window_start + window_ns
```

Jeden burst może więc zostać rozdzielony na kilka list, a każda próbka trafia
dokładnie do jednej listy. Lokalna strefa czasu wpływa tylko na etykietę ścieżki,
nie na arytmetykę przynależności.

Recorder utrzymuje ograniczony słownik otwartych okien (domyślnie bieżące plus
dwa poprzednie). Finalizacja następuje dopiero, gdy watermark czasu akwizycji
przekroczył koniec okna o skonfigurowany margines i wszystkie wcześniejsze
commity zostały potwierdzone. Dane starsze niż otwarty horyzont trafiają do
jawnej kwarantanny `late`, generują alarm i nie zmieniają ukończonego pliku.

Deduplikacja używa klucza `(node_id, boot_epoch, sample_seq)`. Aktywny `.partial`
jest wznawiany po restarcie hosta i jego high-water marks są odczytywane przed
dalszym zapisem. Commit do noda następuje dopiero po zapisie i `flush`; ponowny
pakiet po utraconej odpowiedzi commit nie dopisuje duplikatów.

## 11. Schemat HDF5 v5

Plik:

```text
attrs:
  schema_version = 5
  nominal_window_start_utc_ns
  nominal_window_end_utc_ns
  complete
  finalized_utc_ns

/nodes/<id>/samples
/nodes/<id>/time_anchors
/nodes/<id>/clock_sync
/nodes/<id>/gaps
/nodes/<id>/temperature
```

`samples` zachowuje `sample_seq`, XYZ i `packet_seq`. Nie materializujemy UTC
przy każdym XYZ.

`time_anchors` zawiera co najmniej:

```text
boot_epoch, timing_segment_id, packet_seq,
first_sample_seq, sample_count,
first_device_time_us, last_device_time_us,
sample_period_q16_us, sample_clock_residual_us,
timestamp_source, timestamp_quality,
model_id, max_uncertainty_ns
```

Jeżeli pakiet przecina granicę, każdy plik dostaje fragment kotwicy obejmujący
tylko zapisany zakres sequence i wystarczający do samodzielnego odtworzenia
czasów tego fragmentu.

`clock_sync` przechowuje surowe `t1..t4`, korelację UTC, RTT, decyzję
accept/reject oraz parametry wersjonowanego modelu. `gaps` rozszerzamy o
`boot_epoch`, zakres sequence/device time, powód i jakość.

Atrybuty noda zawierają pierwszy/ostatni sequence i czas faktyczny, liczbę
próbek, epokę/epoki, ODR, `fir_x2_symmetric_v1`, profil/tapy/opóźnienie,
najgorszą niepewność i stan synchronizacji. Przy finalizacji wartości są
przeliczane z datasetów, `complete=true`, plik jest flushowany/zamykany i
atomowo zmieniany z `.partial` na `.h5`.

## 12. Błędy i polityka zapisu

- `LOCKED`: normalny zapis do okna.
- `HOLDOVER`: zapis do okna, jeżeli niepewność nie przecina granicy; inaczej
  plik pozostaje otwarty lub rekord trafia do kwarantanny.
- `UNSYNCED`: buforowanie ograniczone; po przekroczeniu limitu jawna
  kwarantanna, bez zgadywania UTC.
- `INVALID`: brak publikacji jako kompletne dane czasowe.
- przedział niepewności obejmujący dwie granice: próbka nie jest arbitralnie
  przypisywana; czeka na lepszy model albo jest oznaczana jako boundary
  ambiguous.

## 13. Wpływ zasobów

Szacunek przed pomiarem:

- RAM: ring DRDY około 4 KiB; małe okno regresji i snapshot modelu poniżej
  1 KiB; kolejka pakietów około 5 KiB więcej przy 128 pakietach; brak +64 KiB
  w AcquisitionBuffer;
- flash: kod bindera, synchronizacji i parsera — oczekiwane kilkanaście KiB;
- RS485: +40 B na pakiet 32 próbek, do potwierdzenia testem przepustowości;
- CPU noda: jedno `time_us_64()` i zapis ringa na DRDY oraz proste deltowanie;
- CPU hosta/HDF5: regresja na małym oknie obserwacji i grupowanie maksymalnie
  kilkudziesięciu próbek na pakiet.

Build firmware musi raportować zużycie RAM/flash przed i po zmianie. Test
przepustowości obejmie 1–4 nody, 115200 baud, jitter komend diagnostycznych oraz
4 pakiety na grant.

## 14. Migracja i kolejność implementacji

1. Testy i typy czasu: ring DRDY, binder, semantyka filtra i sample clock.
2. Snapshot sample clock i pakiet v2 z testami bajtów, rozmiaru i retransmisji.
3. `TimeSyncV1`, epoka boota i testy `t1..t4`.
4. Host: parser v2, model zegara i testy jitter/dryft/reset.
5. HDF5 v5: wielooknowy writer, deduplikacja, `.partial`, atomowa finalizacja.
6. Test integracyjny: granica 600 s, opóźnienie, retransmisja, luka, reset.
7. Pełne testy host-side, firmware host tests i build bez flashowania.
8. Osobny, zatwierdzony plan testu laboratoryjnego.

Każdy etap ma być osobnym małym commitem. Do czasu potwierdzenia wariantu
sprzętowego wszystkie testy korzystają ze stubów/symulacji; nie wykonujemy
operacji na żywym sensorze.

## 15. Otwarte ryzyka

1. Trzeba potwierdzić, czy docelowy egzemplarz to custom V2 (`GPIO14/15`) czy
   starsza wiązka eval (`GPIO11/10`).
2. Należy potwierdzić dostępność i API sprzętowego generatora losowego w użytej
   wersji Pico SDK albo wybrać trwały licznik epoki.
3. Model afiniczny wygładza krótkookresowy jitter DRDY; niepewność musi być
   na tyle konserwatywna, by nie przypisać arbitralnie próbki przy granicy.
4. Wzrost payloadu może ograniczyć liczbę nodów przy 115200 baud.
5. Dokładność `t2/t3` zależy od miejsca ich przechwycenia w obecnym stosie
   transportowym; test musi zmierzyć asymetrię RX/TX.
6. Dokumentacja release starszej płytki jest obecnie niespójna z `main.cpp` i
   powinna zostać rozdzielona na profile przed jakimkolwiek wydaniem firmware.

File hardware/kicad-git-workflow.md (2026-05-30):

# KiCad Git workflow

## Recommended workflow

1. Pull the latest repository state.
2. Open `hardware/KiCad - node V2/RP2350.kicad_pro`.
3. Make one logical change at a time.
4. Save schematic and PCB.
5. Review `git diff` before committing.
6. Commit KiCad source files together with any footprint/library changes.

## Good commits

Good hardware commits are small enough to review:

- `hardware: add TPS2121 power mux`
- `hardware: route ADXL355 SPI`
- `hardware: update USB-C footprint`
- `hardware: document power input parts`

Avoid one giant commit that changes schematic, board placement, all footprints,
and unrelated notes at once.

## Files to expect in diffs

Schematic changes usually touch:

```text
*.kicad_sch
*.kicad_pro
```

PCB/layout changes usually touch:

```text
*.kicad_pcb
```

Footprint changes usually touch:

```text
*.pretty/*.kicad_mod
```

Local settings and backups are ignored by `.gitignore`.

## Conflict handling

KiCad files are text files, but schematic and PCB conflicts can still be painful.
When a conflict happens:

1. Save a copy of both branches if the change is important.
2. Resolve text conflicts carefully.
3. Open the project in KiCad.
4. Run Electrical Rules Check and Design Rules Check.
5. Save again and commit the resolved project.

## Release folders

When sending a board to manufacture, create a dated release folder only for the
exact exported files that were sent:

```text
hardware/releases/2026-05-30-node-v2/
```

Suggested contents:

- gerbers
- drill files
- BOM export
- position/CPL export
- PDF schematic
- short release note with Git commit hash

Keep ordinary KiCad automatic backups out of Git.

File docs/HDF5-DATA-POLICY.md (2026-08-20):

# HDF5 sample, file, validation and archive policy

## Product boundaries

The system uses three different products. They must not be silently converted
into one another:

1. **Capture HDF5 v1** is the live, crash-recoverable evidence journal.
2. **Archive HDF5 v1** is the immutable, validated long-term source record.
3. **Derived HDF5** is an analysis product. A uniform/resampled time grid belongs
   here and never replaces Capture or Archive samples.

Every Capture and Archive file contains exactly one physical sensor. Sample
identity is `(boot_epoch, sample_seq)`. A retransmission of that identity is not
a new sample.

## Sample policy

- Store every accepted firmware output sample once, losslessly, as signed 24-bit
  sensor values in an `int32` container. The current firmware output is already
  filtered and decimated; its nominal output ODR is sensor ODR divided by the
  recorded decimation factor.
- Never invent samples across sequence gaps, sensor loss, reboot, invalid timing,
  or an unresolved UTC assignment.
- Preserve raw values as the source of truth. Convert to `m/s^2` in readers using
  the configuration interval that covers each stream segment.
- Record configuration changes, gaps, timing uncertainty, and quality separately
  from sample values.
- Use measured timing to estimate effective ODR. Do not derive time from packet
  receive timestamps or from the filename.

## Capture file split and publication

- Default window: **600 seconds**, aligned to half-open UTC intervals
  `[start, end)`. This is the production default in `host/configs/common.json`.
- Route by acquisition UTC, not host receive time. A sample whose timing interval
  overlaps a boundary receives `BOUNDARY_UNCERTAIN` but is stored only once.
- Samples without a defensible UTC assignment go to `unresolved/`; they are not
  eligible for automatic daily archiving.
- Write only to `*.capture.h5.partial`. A completed window is flushed, fsynced,
  marked `complete=true`, closed, and atomically renamed to `*.capture.h5`.
- A graceful stop leaves the current UTC window partial so the next recorder can
  resume it. Startup truncates only an uncommitted raw tail and publishes stale,
  already-ended windows.

The 10-minute split limits the corruption/recovery blast radius and keeps
verification bounded without making daily archives depend on hundreds of tiny
files. Change it only as a product-wide setting after testing restart recovery,
dashboard discovery, and archive compaction.

## Locking and active-file rules

- Exactly one recorder may own a channel runtime namespace. The recorder holds
  `<runtime>/<channel>.recorder.lock` for its full lifetime and writes PID,
  channel, serial port, and destination into the lock file.
- An HDF5 library lock is not the ownership protocol. Disabling HDF5 locking does
  not make two writers safe.
- Normal readers, SFTP exports, validators, and the archive compactor consume only
  atomically published `*.capture.h5` or `*.archive.h5` files.
- Inspect a `.partial` file only after its recorder is stopped and only with the
  explicit `--allow-partial` verifier option.
- After a crash, do not delete a lock file to recover. Kernel advisory locks are
  released with the process; a retained text file is useful owner history.

At startup every partial is recovered independently:

- a valid incomplete file is resumed;
- a valid file already marked complete is atomically published;
- an unreadable, truncated, invalid, conflicting, or duplicate partial is moved
  to `quarantine/partial-recovery/YYYY-MM-DD/` with a `.recovery.json` sidecar;
- `partial_window_unrecoverable` is written to both runtime and durable channel
  diagnostics, and acquisition continues with a new window.

`unresolved/` is reserved for structurally valid samples without defensible UTC.
It is not a corruption quarantine.

The recorder checks free space before opening the serial port and every 30
seconds while running. The production reserve is 1 GiB (`min_free_bytes`). A
breach or HDF5/filesystem write failure stops the recorder with exit code 3. The
supervisor reports `failed-storage` and does not restart-loop; after repairing
storage, an operator explicitly starts or restarts the channel.

## Full-file validation gate

Run:

```bash
./hostctl verify --json path/to/file.capture.h5
./hostctl verify --json path/to/file.archive.h5
```

Validation reads every measurement chunk, which also exercises HDF5 Fletcher32
checksums, then verifies structural coverage, sample identity ordering, signed-24
range, configuration coverage, timing order, gaps, quality coverage, completion,
and (for Archive) the external SHA-256 manifest. The diagnostic report includes:

- sample, block/segment, gap, quality, and source counts;
- fraction with usable time or degraded quality;
- nominal output ODR, robust observed ODR, min/max interval ODR, and shift in ppm;
- whether a derived resampling layer is recommended.

An archive may be published only when all source Captures and the completed
Archive pass this gate. A warning about unavailable ODR is not permission to
resample; it means timing evidence is insufficient.

## Effective ODR and resampling

Estimate effective ODR only inside a continuous `(boot_epoch,
timing_segment_id, sample_seq)` run. Capture uses device-time block endpoints;
Archive uses its simplified UTC control points. Never fit across a gap or reboot.

For spectral analysis or cross-sensor alignment, create a separate Derived file:

1. reconstruct piecewise-affine sample time from Archive control points;
2. select an explicit target ODR (normally the recorded nominal output ODR);
3. apply an anti-alias filter when reducing rate;
4. resample each continuous, valid-quality run independently;
5. keep gaps as gaps and emit a validity/quality mask;
6. record source Archive `file_id`, SHA-256, algorithm/version, target ODR,
   filter, and parameters.

The verifier recommends this derived step when the absolute measured shift is
above 50 ppm. This threshold is an analysis default, not an acquisition alarm;
the default warning threshold is 1000 ppm and can be overridden at the CLI.

## Archive schedule and retention

- Build one Archive file per sensor and UTC day, no earlier than **00:40 UTC** on
  the following day. This leaves more than three 10-minute windows for late
  routing and finalization.
- Archive name: `sensor-<label>_YYYY-MM-DD.archive.h5`.
- Compact only complete UTC-assigned Capture files whose window starts on the
  requested UTC day. Reject duplicates and identity/configuration conflicts.
- Publish the HDF5 atomically, then publish `<file>.sha256` atomically.
- Keep Capture for at least 30 days. Deletion is a separate idempotent operation
  allowed only after Archive validation and confirmed replication. The current
  software intentionally performs no automatic measurement deletion.

## Archive HDF5 v1 contract

Root attributes identify schema, sensor, UTC day, completeness, compactor, and
summary counts. The datasets are:

| Path | Purpose |
| --- | --- |
| `/measurement/raw_xyz` | Bit-exact `(N,3)` signed raw samples |
| `/stream/segments` | Sample identity, timing run, and configuration coverage |
| `/stream/gaps` | Known/unknown loss boundaries without synthetic samples |
| `/timing/control_points` | Sparse device/UTC mapping and uncertainty |
| `/quality/intervals` | Run-length encoded per-sample quality flags |
| `/configuration/intervals` | ODR, range, offsets, decimation, and filter metadata |
| `/environment/temperature` | Sparse temperature observations with sample anchors |
| `/provenance/sources` | Capture file IDs, names, hashes, and contributed counts |

Archive v1 is source data, not a regular-grid matrix. Incompatible semantic or
layout changes require Archive schema v2.

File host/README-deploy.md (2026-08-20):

# Sensor System Deployment Checklist (Host + Node)

This is a practical pre-flight list for deploying a node where you will **not**
have physical USB access after installation (e.g. the node is mounted high up).

It assumes initial provisioning was already done locally with
`node/build/sensor-system-node-factory.uf2`, and that the deployed host machine
will own RS485 communication plus future remote updates.

## 1) Node (firmware) must-haves

- **Remote update over RS485 works end-to-end**:
  - Run `./hostctl update --port ... --node <id>` twice to prove A/B alternation.
  - Simulate an interrupted update (power loss mid-upload), then confirm the
    bootloader recovery window allows completing the update and otherwise rolls
    back to the last confirmed slot.
- **Watchdog enabled**: the application enables a 3 s watchdog and feeds it in
  the core0 acquisition loop (`node/main.cpp`).
- **Boot success confirmation**: the app calls `boot::app_confirm_boot_success()`
  after startup so the bootloader can mark the slot as confirmed (`node/main.cpp`).
- **Persistent config is correct**: verify `node_id`, ODR, range, watermark, and
  offsets via `./hostctl config ... get-config` and save what you need before
  installation.
- **Board identity is correct**: set `board_revision` in the host inventory and
  verify that `get-config` reports the same value. Updates reject V1/V2
  mismatches unless an operator explicitly forces the check after physically
  identifying the board.
- **Fresh nodes are commissioned before install**: factory images now start as
  unassigned (`node_id=0`). Use `./hostctl config --port ... commission-scan`
  and `commission-assign` to give each new node a unique runtime address.

## 2) Host (computer) must-haves

- **Layered configuration**: keep product defaults in tracked
  `host/configs/common.json`, installation facts in
  `host/configs/systems/<system>.json`, then run
  `./host/tools/setup_host.sh <system>`. It creates the ignored
  `host/system_config.json`; this local file should contain only host-specific
  ports, paths and enable/disable overrides. Run `./hostctl doctor` after every
  configuration or deployment change.
- **Stable serial device path**: install a udev rule so the RS485 adapter appears
  as a stable symlink (example in `host/udev/99-sensor-system-rs485.rules.example`).
- **Auto-start on boot**: run either the single-channel recorder or the
  multi-channel supervisor under `systemd` with restart-on-failure. The repo
  includes product-named example units:
  `host/systemd/sensor-system-recorder.service.example`,
  `host/systemd/sensor-system-supervisor.service.example`, and
  `host/systemd/sensor-system-dashboard.service.example`.
- **Operator page always available**: for supervisor-based deployments, also run
  `host/systemd/sensor-system-operator-panel.service.example` under `systemd`. The panel
  is safe to keep online continuously because it only reads runtime files until an
  operator explicitly opens device config, and those config actions are blocked
  while a channel is recording.
- **Disk/mount ready**:
  - Ensure the target directory exists and is writable (e.g. `/data/sensor-system`).
  - Ensure there is enough free space for continuous capture.
  - Keep runtime status under `/run/sensor-system` and bounded logs outside tmpfs.
  - Define a measurement-data retention/archive policy; the host warns below 15%
    free space, and the recorder stops safely below the configured 1 GiB reserve,
    but never deletes HDF5 measurements automatically.
- **Time sync**: enable NTP/chrony/systemd-timesyncd; host timestamps are written
  into the output files.

For a development laptop or bench machine that is temporarily acting as the
host, the minimum local setup is:

- `python3 -m venv host/.venv`
- `host/.venv/bin/python -m pip install -r host/requirements-recorder.txt`
- use `./hostctl ping`, `./hostctl config`, and `./hostctl update` from the repo root

## 3) One-time setup steps (typical Linux host)

1. Create Python venv and install dependencies:
   - `python3 -m venv host/.venv`
   - `host/.venv/bin/python -m pip install -r host/requirements-recorder.txt`
   - run `./hostctl paths --init` and verify the displayed recording location
2. Install udev rule (edit VID/PID/serial first on the target host):
   - copy `host/udev/99-sensor-system-rs485.rules.example` to `/etc/udev/rules.d/99-sensor-system-rs485.rules`
   - reload rules and replug the adapter (or `udevadm trigger`)
3. Create the canonical local directories:
   - run `./hostctl paths --init`
   - verify recordings under `var/recordings`, archives under `var/archive`,
     and logs under `var/log`
4. Install the recording service:
   - copy `host/systemd/sensor-system-recorder.service.example` to `/etc/systemd/system/sensor-system-recorder.service`
   - edit paths/args
   - `sudo systemctl daemon-reload`
   - `sudo systemctl enable --now sensor-system-recorder.service`
   - for multi-channel deployments, install both
     `host/systemd/sensor-system-supervisor.service.example` and
     `host/systemd/sensor-system-dashboard.service.example`
5. For multi-channel deployments, install the always-on operator panel too:
   - copy `host/systemd/sensor-system-operator-panel.service.example` to `/etc/systemd/system/sensor-system-operator-panel.service`
   - edit paths/args if needed
   - `sudo systemctl daemon-reload`
   - `sudo systemctl enable --now sensor-system-supervisor.service sensor-system-dashboard.service`
6. If read-only data export over SFTP is required, follow
   `host/ssh/README.md`; bind the complete product `var/` directory into the
   root-owned chroot and keep credentials outside Git.

## 4) Suggested pre-flight tests before final install

- 24–72 hour soak run on the same host hardware:
  - verify window rotation (`600` seconds by default, `86400` for daily if configured)
  - verify file boundaries match the configured local timezone if you pass `--window-timezone`
  - verify `host_console.py` stays responsive (status + events update)
- Reboot host during recording and confirm it restarts and continues with
  `--start-from newest`.
- Hard-cut host power during an active Capture window. After boot, confirm the
  channel resumes automatically, or that the unreadable partial appears under
  `quarantine/partial-recovery/` with a JSON sidecar while a new window records.
- Simulate the storage reserve threshold and confirm the supervisor exposes
  `failed-storage` without a restart loop. Repair storage, then explicitly start
  or restart the channel.
- Power-cycle the node and confirm it comes back and answers `./hostctl ping`.
- Confirm `./hostctl update --port ... --node ...` still works from the final host.

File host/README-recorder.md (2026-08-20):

# Sensor System RS485 Recorder

The production Capture/Archive lifecycle, locking rules, full-file validation,
effective-ODR diagnostics, and derived resampling policy are defined in
[`docs/HDF5-DATA-POLICY.md`](../docs/HDF5-DATA-POLICY.md).

`host_recorder.py` is the single-channel production-oriented host receiver. It
talks to nodes over one RS485 channel, drains burst packets, commits received
sample ranges, and writes decoded XYZ samples to disk.

For multi-channel deployments use `host_supervisor.py`, which runs one recorder
worker per RS485 channel from `host/system_config.json`.

Each channel can select its timestamp routing policy independently:

```json
{
  "name": "line-d",
  "port": "/dev/sensor-system-rs485-d",
  "timing_mode": "required",
  "nodes": [{"id": 1}]
}
```

Supported values are:

- `legacy`: route samples by host receive time;
- `observe`: compute acquisition time but retain receive-time routing;
- `required`: route HDF5 samples by acquisition time and quarantine samples
  whose time is unsynchronized or overlaps a window boundary.

The supervisor always passes the configured mode explicitly to the recorder.
The default remains `legacy` for channels that have not completed the
timestamping rollout. `required` is rejected at configuration load time unless
the storage format is HDF5.

## Install HDF5 Dependencies

```bash
python3 -m venv host/.venv
host/.venv/bin/python -m pip install -r host/requirements-recorder.txt
```

If you are using a fresh local machine, create the virtual environment first and
then use the `./hostctl` launcher from the repository root for day-to-day work.

## Record To HDF5

```bash
host/.venv/bin/python host/host_recorder.py \
  --port /dev/sensor-system-rs485 \
  --nodes 1 \
  --output runs/run_001.h5 \
  --format hdf5
```

Use `--duration 60` for a fixed-length one-minute capture. Without `--duration`,
recording runs until `Ctrl+C`.

## Record To Rotating HDF5 Files

```bash
host/.venv/bin/python host/host_recorder.py \
  --port /dev/sensor-system-rs485 \
  --nodes 1,2 \
  --output-dir runs/sensor-system \
  --format hdf5 \
  --window-seconds 600 \
  --window-timezone Europe/Warsaw
```

This creates one file per 10-minute local-time window. For example:

- `runs/sensor-system/2026-04-24/2026-04-24_14-20.h5`
- `runs/sensor-system/2026-04-24/2026-04-24_14-30.h5`

If the recorder is restarted inside the same window, it appends to the existing
file for that window.

Each new rotated file starts with one temperature sample per node. That sample
is anchored to the first expected `sample_seq` in the new window, which makes
later joins and summaries simpler.

`--temperature-interval 0` now disables only the extra periodic reads. The
window-start temperature sample is still kept for each rotated file.

`--output-dir` now defaults to `--window-seconds 600` even without an explicit
flag. Pass `--window-timezone` to align file boundaries to a named local zone.

## Record To Daily HDF5 Files

```bash
host/.venv/bin/python host/host_recorder.py \
  --port /dev/sensor-system-rs485 \
  --nodes 1,2 \
  --output-dir runs/archive \
  --format hdf5 \
  --window-seconds 86400 \
  --window-timezone Europe/Warsaw
```

This creates one file per local day, for example `2026-04-24.h5`.

## Operator Runtime Files

The recorder also writes:

- a JSON runtime status snapshot, default `/tmp/sensor-system_recorder_status.json`
- a JSONL event log, default `/tmp/sensor-system_recorder_events.jsonl`

`recorder_stopped` now includes `stop_reason` and signal fields when shutdown was
triggered by `SIGINT` or `SIGTERM`.

Those files are intended for `host_console.py` and other local supervisory tools.

## Live Web UI

For test/bring-up you can enable a minimal live web UI (time plot + PSD/FFT) that
streams the same sample fields as HDF5 over HTTP/SSE:

```bash
./hostctl recorder --port /dev/sensor-system-rs485 --nodes 1 --output-dir runs/sensor-system --format hdf5 --window-seconds 600 --live --live-port 8000
```

Open `http://<host-ip>:8000/`.

## Gaps And Resets

`sample_seq` is a firmware-side sequence. It can contain gaps after events such
as node resets, host restarts, power loss, or when starting from `--start-from newest`.

For HDF5 output the recorder writes gap markers to `/nodes/<node_id>/gaps`.
For CSV output it writes `<output>.gaps.csv`.

## HDF5 Layout

- `/nodes/<node_id>/samples`: append-only compound dataset.
- `/nodes/<node_id>/temperature`: sparse host-side temperature reads.
- `/nodes/<node_id>/gaps`: records detected discontinuities in `sample_seq`.
- `sample_seq`: output sample sequence after firmware-side filtering and x2 decimation.
- `x`, `y`, `z`: acceleration samples stored in `m/s^2`.
- `packet_seq`: firmware packet sequence.
- `sample_seq_anchor` in `temperature`: host-side anchor for the reading.
  Periodic reads use the newest committed/written sample sequence, while the
  first temperature sample in a rotated file uses the first expected sequence
  for that file window.

Node metadata such as `sensor_odr_hz`, `output_odr_hz`, `range_g`, and
`fifo_watermark` is stored as attributes on `/nodes/<node_id>`.

## CSV Fallback

```bash
host/.venv/bin/python host/host_recorder.py \
  --port /dev/sensor-system-rs485 \
  --nodes 1 \
  --output runs/run_001.csv \
  --format csv
```

CSV metadata is written to a sidecar file named `run_001.csv.meta.json`.

For day-to-day use from the repository root, the shorter launcher form is:

```bash
./hostctl recorder --port /dev/sensor-system-rs485 --nodes 1,2 --output-dir runs/sensor-system --format hdf5 --window-seconds 600
./hostctl console
```

Use the RS485 adapter path that exists on the host. In production prefer a
stable udev alias such as `/dev/sensor-system-rs485`.

For first-time node provisioning and later firmware updates, see:

- [node/README-bootloader.md](/home/anone/pico-projects/node/README-bootloader.md:1)
- [host/README-product.md](/home/anone/pico-projects/host/README-product.md:1)

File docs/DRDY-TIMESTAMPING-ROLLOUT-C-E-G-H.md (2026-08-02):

# Rollout timestampingu — linie C, E, G i H

Data: 2026-07-27
System: testowy, rejestracja bez określonego czasu zakończenia

## Zakres

- A i B pozostawiono bez zmian jako kanały referencyjne w trybie `legacy`.
- D pozostaje kanałem L1 w trybie `required`.
- C, E, G i H zaktualizowano z v0.3.9 do v0.3.10 z timestampingiem v2.
- F jest fizycznie odłączona i została wyłączona w lokalnej konfiguracji hosta.

Wszystkie aktualizowane nody używały historycznej nazwy `legacy_eval`, która
od wersji 0.4.1 jest aliasem profilu `board_v2`:

- DRDY: GPIO11;
- INT1: GPIO10;
- SPI1: GPIO12–15.

## Obraz

Konfiguracja kompilacji:

```text
CMAKE_BUILD_TYPE=Release
SENSOR_SYSTEM_BOARD_PROFILE=board_v2
SENSOR_SYSTEM_ENABLE_TIMESTAMPING_V2=ON
```

SHA-256:

- slot A:
  `cd9e885325f10a1e88e76d6d93b79bb34e77ccb56b05869423ac9ca63a240b6d`;
- slot B:
  `cced6a11a145f7f4153a01b25d4e4a3917f2015f9a1f9cdafe6f37af1ccf5c43`;
- pakiet aktualizacji:
  `cee951c47236d5f4a4565ff5ed7bc94ceb70f3fa900116d8d0dc7497aa8b6212`.

Są to te same artefakty, które przeszły L1 na linii D.

## Konfiguracja po aktualizacji

| Linia | Firmware | Sensor ODR | Output ODR | Routing |
|---|---:|---:|---:|---|
| A | v0.3.0 | 250 Hz | 125 Hz | `legacy` |
| B | v0.3.0 | 250 Hz | 125 Hz | `legacy` |
| C | v0.3.10 | 500 Hz | 250 Hz | `required` |
| D | v0.3.10 | 250 Hz | 125 Hz | `required` |
| E | v0.3.10 | 250 Hz | 125 Hz | `required` |
| F | odłączona | — | — | wyłączona |
| G | v0.3.10 | 250 Hz | 125 Hz | `required` |
| H | v0.3.10 | 250 Hz | 125 Hz | `required` |

Po zmianie slotu jawnie odtworzono i zapisano konfigurację każdego
aktualizowanego noda. C zachowała 500 Hz; E, G i H zachowały 250 Hz.
Po czystym restarcie wszystkie cztery nody raportowały:

- `fifo_overruns=0`;
- `drdy_ring_ovf=0`;
- `timing_mismatch=0`;
- `timing_invalid=0`;
- stabilny segment czasu.

## Host

Supervisor uruchamia:

- A i B z `--timing-mode legacy`;
- C, D, E, G i H z `--timing-mode required`;
- bez workera dla F.

Po świeżym restarcie supervisora i dashboardu:

- 7/7 aktywnych nodów było online;
- 7/7 dostarczało próbki;
- `gaps_detected=0`;
- nowe straty, overflow i packet overwrite w sesji wynosiły zero;
- dashboard raportował `system_healthy=true` i `attention_count=0`.

Początkowe próbki przed lockiem TimeSync oraz próbki niejednoznaczne na
granicy okna są trwale kierowane do kwarantanny. Zwykłe HDF5 v5 są kierowane
według czasu akwizycji.

## Znane ograniczenie

Na wszystkich badanych nodach pozostaje obserwowany wzorzec nadmiarowych
zboczy INT1: około połowa zdarzeń występuje poniżej watermarku FIFO.
Nie powoduje to obecnie przepełnień ani utraty danych, ponieważ firmware
weryfikuje stan FIFO i ma fallback pollingowy. Test długotrwały ma pozostać
uruchomiony bez określonego czasu zakończenia.

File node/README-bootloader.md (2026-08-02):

# Sensor System Node Bootloader And Remote Update

This firmware now builds as a real A/B update system intended for RS485-only maintenance.

## Flash Layout

The Pico 2 flash is split into:

- `0x00000000 .. 0x0001ffff` bootloader (`128 kB`)
- `0x00020000 .. 0x0003ffff` metadata/config (`128 kB`)
- `0x00040000 .. 0x0021ffff` application slot A (`1.875 MB`)
- `0x00220000 .. 0x003fffff` application slot B (`1.875 MB`)

The authoritative constants are in [boot/boot_config.h](/home/anone/pico-projects/node/boot/boot_config.h:1).

## Build Outputs

After:

```bash
cmake -S node --preset board-v2
cmake --build node/build
cmake --build node/build --target sensor_system_node_release
```

Use preset `board-v1` for the legacy evaluation wiring. It builds separately
under `node/build.v1`, so configuring one board can no longer silently reuse
the other board's cached pins.

the important artifacts are:

- `node/build/sensor-system-node-factory.uf2`
  Full factory image for initial provisioning over USB/BOOTSEL.
- `node/build/sensor-system-node.uf2`
  General full-image UF2. For a brand-new node, prefer the factory image above.
- `node/build/sensor-system-node-factory.bin`
  Raw flash image containing bootloader, initial metadata, and slot A app.
- `node/build/sensor-system-node.bin`
  General full-image raw binary variant.
- `node/build/sensor-system-node-bootloader.uf2`
  Bootloader-only image for development.
- `node/build/sensor-system-node-slot-a.bin`
- `node/build/sensor-system-node-slot-b.bin`
- `node/build/sensor-system-node-update-package.json`
  Manifest used by the host update tool. It points at the correct slot-specific image and carries version/CRC metadata.
- `node/build/sensor-system-node-direct.uf2`
  Diagnostic standalone application image without the A/B bootloader. Use it only
  to isolate bootloader issues during bench work.

The node-only release package is generated under:

- `node/build/releases/sensor-system-node-vX.Y.Z/`

The `vX.Y.Z` value comes from `common/protocol_ids.h`, which is also what the
node reports at runtime and what the update manifest carries as the packed
firmware version. Host tools and host configuration are intentionally not
included in this package; publish them as a separate host release.

The node release package contains:

- `sensor-system-node-vX.Y.Z-factory.uf2`
- `sensor-system-node-vX.Y.Z-factory.bin`
- `sensor-system-node-vX.Y.Z-update-package.json`
- `sensor-system-node-vX.Y.Z-slot-a.bin`
- `sensor-system-node-vX.Y.Z-slot-b.bin`
- `sensor-system-node-vX.Y.Z-direct.uf2`
- `README.md`
- `SHA256SUMS.txt`
- `release-manifest.json`

## Local Build On A New Computer

For a fresh local machine where the node firmware will be built outside the
Raspberry Pi host:

```bash
git clone https://github.com/raspberrypi/pico-sdk.git
export PICO_SDK_PATH=$PWD/pico-sdk
cmake -S node --preset board-v2
cmake --build node/build
```

On macOS, if CMake does not auto-detect the ARM toolchain correctly, configure
with explicit compiler paths:

```bash
cmake -S node -B node/build \
  -DCMAKE_C_COMPILER=/opt/homebrew/bin/arm-none-eabi-gcc \
  -DCMAKE_CXX_COMPILER=/opt/homebrew/bin/arm-none-eabi-g++ \
  -DCMAKE_ASM_COMPILER=/opt/homebrew/bin/arm-none-eabi-gcc
cmake --build node/build
```

If you see a TinyUSB submodule warning during configuration, it is acceptable
for current RS485-only builds and does not block the firmware artifacts above.

## Recommended Provisioning

For a brand-new node or a board recovered locally:

1. Put the Pico 2 into BOOTSEL mode.
2. Flash `node/build/releases/sensor-system-node-vX.Y.Z/sensor-system-node-vX.Y.Z-factory.uf2`.
3. Reboot normally.
4. Commission a runtime `node_id` over RS485:

```bash
./hostctl config --port /dev/sensor-system-rs485 commission-scan
./hostctl config --port /dev/sensor-system-rs485 commission-assign --hardware-id 0123456789ABCDEF --node-id 1
./hostctl config --port /dev/sensor-system-rs485 --node 1 get-config
```

Fresh factory images now start as unassigned (`node_id=0`), so they will not
answer normal `ping` or update commands until commissioning assigns a real
runtime address.

Use the actual RS485 adapter path on the host. USB numbering can change after
reflashing or reconnecting adapters, so production hosts should prefer a stable
udev alias such as `/dev/sensor-system-rs485`.

The expected post-provisioning check is:

```bash
./hostctl ping --port /dev/sensor-system-rs485 --node 1
./hostctl boot --port /dev/sensor-system-rs485 --node 1 --enter none hello
```

`ping` should answer. `boot ... --enter none hello` should time out because the
node should be running the application, not sitting in bootloader update mode.

## Hardware Pinout

The firmware uses `spi1`, with pins selected by the immutable board revision.
Do not infer the wiring from a host name or node ID.

| Power / ADXL355 signal | ADXL355 pin | Pico 2 pin | Wire color |
| --- | ---: | --- | --- |
| Pico 5V | - | 5V / VBUS | Red |
| VDDIO / ADXL 3V3 | 1 | 3V3 | Orange |
| VDD / ADXL 3V3 | 3 | 3V3 | Orange |
| GND | 5 | GND | Black |
| SCLK/Vssio | 10 | V1: GPIO10, V2: GPIO14 | Yellow |
| MOSI/SDA | 12 | V1: GPIO11, V2: GPIO15 | Green  |
| MISO/SDA | 11 | GPIO12 / SPI1 RX  | Blue |
| CS/SCL | 8 | GPIO13 | White |
| DRDY | 6 | V1: GPIO14, V2: GPIO11 | Purple |
| INT1 | 2 | V1: GPIO15, V2: GPIO10 | Gray |
| INT2 | 4 | Not connected | - |

Do not drive the ADXL355 `V1P8ANA`, `V1P8DIG`, or `Vddio` output pins from the
Pico.

RS485 connects through the HAT, so no separate Pico GPIO jumper wiring is
needed in the release harness. Keep the Pico, ADXL355 board, and RS485 HAT
grounds common. Connect the RS485 A/B pair according to the HAT markings and
keep polarity consistent across the bus.

Both revisions use GPIO0/GPIO1 for RS485 TX/RX. V1 additionally uses GPIO2 for
driver enable; the installed V2 interface has no firmware-controlled DE pin.

## Remote Update Over RS485

For field updates, use the packaged manifest instead of a raw `.bin`:

```bash
./hostctl update --port /dev/sensor-system-rs485 --node 1 \
  --image node/build/releases/sensor-system-node-vX.Y.Z/sensor-system-node-vX.Y.Z-update-package.json
```

The host uses a longer timeout for update operations because the bootloader
erases the inactive slot before acknowledging `Begin`. For slow flash or noisy
links, override it explicitly:

```bash
SENSOR_SYSTEM_UPDATE_TIMEOUT=30 ./hostctl update --port /dev/sensor-system-rs485 --node 1
```

This does:

- asks the running app to reboot into bootloader
- probes bootloader `HELLO`
- learns which inactive slot should receive the update
- selects the matching image from `sensor-system-node-update-package.json`
- uploads the image
- leaves metadata armed for a trial boot into the new slot

You can also use the low-level maintenance tool directly:

```bash
./hostctl boot --port /dev/sensor-system-rs485 --node 1 --enter app hello
./hostctl boot --port /dev/sensor-system-rs485 --node 1 --enter app \
  --image node/build/sensor-system-node-update-package.json upload
```

## Reliability Model

The update flow is A/B with rollback-oriented metadata:

- the currently known-good image remains in `active_slot`
- the new image is written to the other slot
- boot metadata arms a trial boot into the new slot
- if the new image confirms itself, it becomes the new `active_slot`
- if it fails to come up cleanly, bootloader rolls back to the previously active slot

The decision logic lives in:

- [boot/boot_decision.cpp](/home/anone/pico-projects/node/boot/boot_decision.cpp:1)
- [boot/boot_update_engine.cpp](/home/anone/pico-projects/node/boot/boot_update_engine.cpp:1)
- [boot/boot_update_server.cpp](/home/anone/pico-projects/node/boot/boot_update_server.cpp:1)

## Boot Handoff

On RP2350 the slot application is linked at its slot address, for example
`0x10040000` for slot A. The bootloader validates the vector table and then uses
a controlled vector-table chainload:

- deinitializes `uart0`, which bootloader maintenance/update mode used
- stops SysTick
- disables and clears pending NVIC IRQs
- restores a plain privileged MSP context
- sets `VTOR` and `MSP`
- branches to the slot reset handler

This path is deliberately kept in firmware instead of using `rom_chain_image()`,
because the current slot images boot reliably through the vector path and are
managed by our own A/B metadata.

## LED Status

The Pico LED is an operational readiness indicator:

- five short blinks after reset: application startup began
- LED off: initialization is still in progress or failed
- LED on: application, RS485 transport, core1 loop, and ADXL355 driver init all completed

The LED on state is therefore the local "app ready with sensor accepted" signal.

## Hardware Acceptance

Minimum acceptance after changing bootloader or application startup:

1. Flash `sensor-system-node-factory.uf2` for a fresh board, or `sensor-system-node.uf2` for bench reflashing.
2. Confirm LED turns on after startup.
3. Confirm `./hostctl ping --port ...` succeeds.
4. Confirm `./hostctl boot --port ... --node ... --enter none hello` times out.
5. Run `./hostctl update --port ... --node ...`.
6. Confirm the node reboots back into the application and still answers `ping`.
7. Repeat once more to prove A/B alternation.

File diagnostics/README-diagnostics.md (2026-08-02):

# Sensor System Diagnostics

Raw diagnostic captures are operational data and are intentionally ignored by
Git. Store a temporary investigation under `var/diagnostics/<date>-<incident>/`
or another external data volume. When an incident is closed, keep only the
reusable conclusion or procedure in documentation and remove the raw logs.

This project uses a layered diagnostics model for Pico nodes on RS485:

- cheap counters for steady-state health
- a small on-device black-box event buffer
- a sticky incident snapshot for the first meaningful fault after boot or clear
- one persistent incident record in flash for post-restart access
- host-side JSONL/runtime status files for long retention and operator visibility

## Goals

- distinguish symptom from cause, especially for `NoData`
- preserve the first useful signal before later noise overwrites it
- keep firmware diagnostics cheap enough for real-time acquisition
- make host-side collection structured and easy to correlate

## What To Check And When

### Every acquisition loop

These checks must stay cheap and deterministic:

- interrupt seen for FIFO watermark path
- ADXL355 `STATUS` read result
- FIFO entry count
- FIFO read result
- sample decode validity
- sample sequence progress

What to record:

- counters always
- event only on first occurrence, severity change, recovery, or power-of-two streak

### At boot and init

Check:

- reset cause
- sensor init
- device identity (`DEVID_AD`, `DEVID_MST`, `PARTID`)
- applied ODR/range/high-pass/watermark
- controller init
- RS485 init
- transport init

What to record:

- `Boot`
- init failures as `Error`/`Critical`
- config/application milestones as `Info`

### On config change

Check immediately after apply:

- device accepted new config
- acquisition recovered
- expected output ODR matches host assumptions

What to record:

- `RuntimeConfigApplied`
- `RuntimeConfigApplyFailed`

### On first anomaly

The first anomaly is where root cause usually appears. Capture:

- sticky fault snapshot
- current counters
- last `STATUS` register
- last FIFO entry count
- last FIFO read result
- FIFO decode flags
- whether the loop was triggered by IRQ

### On repeated anomaly

Do not log every repeat. Use counters plus power-of-two escalation:

- 1, 2, 4, 8, 16, 32...

This keeps signal while preventing the ring buffer from being flooded.

### On recovery

Always record recovery after a streak of `NoData` or sensor errors:

- how long the problem lasted
- what streak counts were cleared

Recovery events are often as useful as failure events because they show the boundary of the bad window.

## What To Store On Pico

Do not store full text logs or every successful operation.

Store locally:

- counters
- recent warning/error events
- selected `Info` milestones: boot, config applied, recovery, diagnostics cleared
- one sticky incident snapshot
- one persistent flash record saved on the first significant incident per boot

Do not store locally:

- every normal sample
- every repeated identical warning
- large text messages

The persistent flash record is intended for the case where RS485 is lost and the node later reboots.
It should contain the last important pre-restart context, not a full event history.

## `NoData` Decision Tree

`NoData` is only a symptom. To debug it, check these fields together:

- IRQ seen?
- `STATUS` register value
- FIFO entries before read
- FIFO read result (`Ok`, `NoData`, `CommError`, `InvalidSample`, ...)
- FIFO decode flags:
  - empty entry seen
  - axis mismatch seen
- time since last good sample
- sensor error streak

Interpretation:

- IRQ missing: likely interrupt/wiring/config path
- IRQ seen + FIFO entries low: sensor not producing data or watermark not reached
- IRQ seen + FIFO entries present + `NoData`: FIFO payload/driver interpretation problem
- `CommError`: SPI path
- `InvalidSample`: framing/decode/order issue

## Event Argument Conventions

Diagnostic `arg0`/`arg1` are event-specific and should be decoded, not treated as generic numbers.

Current firmware packs driver context for acquisition faults as:

- `arg0` byte 0: last ADXL355 `STATUS`
- `arg0` byte 1: last FIFO entry count
- `arg0` byte 2: last FIFO read status (`SensorStatus`)
- `arg0` byte 3:
  - bit 7: IRQ seen
  - bit 0: empty FIFO entry observed
  - bit 1: axis mismatch observed

Examples:

- `FifoRepeatedNoData`: `arg1` = current no-data streak
- `FifoOverrun`: `arg1` = dropped-sample counter at the time of the event
- `FifoStatusReadError`, `SensorReadError`, `InvalidSample`:
  - `arg1` byte 0 = `SensorStatus`
  - `arg1` bytes 1..3 = error streak

## Host Responsibilities

The host should keep doing the heavy lifting:

- persist runtime status snapshots
- persist JSONL event streams
- fetch node diagnostics over RS485 when an anomaly appears
- correlate node diagnostics with recorder/supervisor warnings

Recommended polling cadence:

- status/runtime metrics: every 1s
- extended stats: every 5s
- diagnostic dump: on node init, on warning/error transition, on exit/restart, and after manual repro

## Exceptions And `catch`

For firmware on Pico:

- do not rely on broad `try/catch`
- use explicit return-code checks around SPI, sensor config, RS485, transport, and storage boundaries
- convert failures immediately into structured diagnostic events

For host Python:

- narrow `except` blocks are appropriate at I/O boundaries
- convert exceptions into structured JSONL events
- keep one broad top-level `except` only for process-level reporting and exit code control

## Practical Workflow

For a suspect node:

1. Reproduce the issue while the recorder or supervisor is running.
2. Read node status and diagnostic info.
3. Read the sticky fault snapshot.
4. Drain diagnostic events.
5. Correlate with host `events.jsonl`, `status.json`, and `process.log`.

Useful commands:

```bash
host/.venv/bin/python host/host_configurator.py --port /dev/ttyCH9344USB2 --baud 115200 --node 1 get-status
host/.venv/bin/python host/host_configurator.py --port /dev/ttyCH9344USB2 --baud 115200 --node 1 get-diagnostic-info
host/.venv/bin/python host/host_configurator.py --port /dev/ttyCH9344USB2 --baud 115200 --node 1 get-fault-snapshot
host/.venv/bin/python host/host_configurator.py --port /dev/ttyCH9344USB2 --baud 115200 --node 1 get-persistent-diagnostic-record
host/.venv/bin/python host/host_configurator.py --port /dev/ttyCH9344USB2 --baud 115200 --node 1 dump-diagnostics
host/.venv/bin/python host/host_configurator.py --port /dev/ttyCH9344USB2 --baud 115200 --node 1 clear-persistent-diagnostic-record
```

If the first question is "SPI, memory, or something else?", the best first discriminator is:

- `FifoStatusReadError` or `SensorReadError` => likely SPI/driver path
- `FifoRepeatedNoData` with IRQ seen and low FIFO entries => likely sensor/config/timing path
- `InvalidSample` => likely FIFO decode/order/pathology in sample handling
- host-only failures with healthy node diagnostics => transport or host path

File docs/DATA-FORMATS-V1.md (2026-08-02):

# Sensor System data formats v1

This document is the implementation contract for the first clean Capture and
Archive formats. Dataset names, types, units, sentinels, and invariants are
normative. Examples are descriptive.

## 1. Common rules

### 1.1 Identity

Every file describes exactly one physical sensor.

| Field | Type | Meaning |
|---|---|---|
| `channel_id` | `uint8` | Transport channel `1..8` |
| `sensor_label` | fixed ASCII | Temporary label `A..H` |
| `sensor_id` | fixed ASCII | Future permanent identifier; empty until assigned |
| `node_address` | `uint8` | Address used on the channel |
| `hardware_id` | fixed ASCII | MCU hardware identifier when available |

Initial mapping is `1→A`, `2→B`, ..., `8→H`. Channel, sensor, and node address
are separate concepts. A future sensor move creates a new assignment interval;
it does not rewrite old files.

### 1.2 Numeric conventions

- Integers are explicitly little-endian.
- UTC is signed Unix nanoseconds in `int64`.
- Device time is microseconds in `uint64`.
- `utc_ns = -1` means unavailable. Zero is not used as a missing UTC value.
- `device_time_us = 0` is unavailable only when the accompanying validity flag
  is not set.
- Ranges are half-open: `[start, start + count)`.
- Dataset units are recorded in a `unit` attribute.
- Enumerations are stored as integers and defined in this specification and in
  one shared Python module.

### 1.3 File attributes

Both products contain:

```text
format_name
schema_major
schema_minor
file_id
channel_id
sensor_label
sensor_id
node_address
hardware_id
firmware_version
created_utc_ns
finalized_utc_ns
complete
```

Fixed text widths are `S36` for UUID, `S8` for sensor label, `S64` for permanent
sensor ID, `S32` for hardware ID and firmware version, and `S32` for calibration
revision. `file_id` and session identifiers use canonical lowercase UUID text.
Files are readable only when `complete=true`. Writers publish through
`.partial`, flush all datasets, close the file, atomically rename it, and fsync
the directory.

### 1.4 Source sample representation

The firmware sends the filtered and x2-decimated acceleration as signed 24-bit
integers. HDF5 stores them in an `int32` container without further scaling:

```text
/measurement/raw_xyz  dtype=<i4, shape=(N, 3)
```

Axes are ordered `X,Y,Z`. Attributes include:

```text
encoding = "signed_integer"
valid_bits = 24
unit = "sensor_lsb"
processing_stage = "firmware_filtered_decimated"
```

Readers expose SI values without modifying the source array:

```text
acceleration_m_s2 = raw_xyz * scale_g_per_lsb * 9.80665
```

The selected ADXL355 range, firmware filter profile, decimation factor, offsets,
and calibration revision are recorded in configuration intervals. Host-side
floating-point values are never considered the canonical source.

### 1.5 Calibration model v1

Product calibration is performed by writing `offset_x`, `offset_y`, and
`offset_z` to the ADXL355 offset registers. Archive v1 records those exact
register values and the sample-sequence boundary from which they apply, using
`calibration_method = "sensor_offset_registers"`. No host-side bias vector or
cross-axis matrix is required by v1. A future calibration method may extend the
configuration contract under a new method identifier without changing stored
raw samples.

## 2. Capture HDF5 v1

### 2.1 Purpose and partitioning

Capture is a short-retention, crash-recoverable acquisition journal. Normal
operation uses 10-minute UTC files per sensor. Filename boundaries organize
storage but do not define signal continuity.

Recommended name:

```text
capture/ch-01/sensor-A/2026-08-02/
  sensor-A_20260802T124000Z.capture.h5
```

### 2.2 Measurement blocks

`/capture/blocks` is the commit journal for `/measurement/raw_xyz`. One row
describes a contiguous block derived from one transport packet or packet
fragment.

| Field | Type | Meaning |
|---|---|---|
| `sample_offset` | `<u8` | First row in `raw_xyz` |
| `sample_count` | `<u4` | Number of rows |
| `boot_epoch` | `<u8` | Firmware boot epoch |
| `first_sample_seq` | `<u8` | Sequence of first row |
| `timing_segment_id` | `<u4` | Firmware timing segment |
| `source_packet_seq` | `<u4` | Transport diagnostic identity |
| `timing_format_version` | `u1` | Firmware timing payload version |
| `timestamp_source` | `u1` | Firmware timestamp source |
| `first_device_time_us` | `<u8` | First sample device time |
| `last_device_time_us` | `<u8` | Last sample device time |
| `sample_period_q16_us` | `<u4` | Firmware period estimate |
| `max_fit_residual_us` | `<u4` | Firmware fit residual bound |
| `first_utc_ns` | `<i8` | Estimated acquisition UTC or `-1` |
| `last_utc_ns` | `<i8` | Estimated acquisition UTC or `-1` |
| `uncertainty_ns` | `<u8` | Maximum half-width for the block |
| `timing_flags` | `<u2` | Firmware timing flags |
| `routing_flags` | `<u2` | Host timing/routing flags |

The write transaction is:

1. append raw XYZ;
2. flush;
3. append the block row;
4. flush.

On recovery, XYZ is truncated to the largest committed
`sample_offset + sample_count`. A block may not overlap another block in the
same file.

### 2.3 Sparse datasets

```text
/environment/temperature
/configuration/intervals
/quality/events
/diagnostics/clock_sync
```

`temperature` fields:

```text
boot_epoch:u8, sample_seq_anchor:u8, raw:u2, celsius:f4,
observed_utc_ns:i8
```

`configuration/intervals` starts a new row whenever measurement-affecting
configuration changes. It includes at minimum:

```text
start_boot_epoch, start_sample_seq, sensor_odr_hz, output_odr_hz,
range_g, high_pass_corner, offset_x, offset_y, offset_z,
decimation_factor, filter_profile, calibration_revision
```

`quality/events` stores measurement-relevant events using:

```text
event_id:u8, boot_epoch:u8, sample_seq_anchor:u8, observed_utc_ns:i8,
event_code:u2, severity:u1, flags:u4, count:u8, value_a:i8, value_b:i8
```

The event-code registry defines the meaning of `count`, `value_a`, and
`value_b`. Initial codes cover physical FIFO loss, recovery, timing
invalidation, configuration and calibration changes, host restart, and known
logical gaps. Operational messages and UI logs do not belong here.

`clock_sync` retains request/response observations and their accepted state for
the 30-day diagnostic period.

### 2.4 Capture routing flags

```text
0x0001 UTC_VALID
0x0002 BOUNDARY_UNCERTAIN
0x0004 INITIALLY_UNSYNCED
0x0008 LATE_ARRIVAL
0x0010 RECOVERED_AFTER_RESTART
```

Samples are stored exactly once. There are no separate `ambiguous`, `late`, or
`unsynced` copies. When the best UTC estimate falls inside a window, that window
owns the sample and the uncertainty is preserved as a flag and numeric bound.

Data without any usable UTC estimate remains in a session-scoped Capture file
until offline reconstruction can assign it. It is never silently discarded.

## 3. Archive HDF5 v1

### 3.1 Purpose and partitioning

Archive is the validated, minimal, long-term source record. The normal partition
is one sensor and one UTC day:

```text
archive/sensor-A/2026/08/
  sensor-A_2026-08-02.archive.h5
```

An exceptional session archive is allowed for data that cannot be assigned to
a UTC day. Such a file is explicitly marked `time_assignment=unresolved`.

### 3.2 Datasets

```text
/measurement/raw_xyz
/stream/segments
/stream/gaps
/timing/control_points
/quality/intervals
/environment/temperature
/configuration/intervals
/provenance/sources
```

`stream/segments` reconstructs sequence identity without repeating it per
sample:

| Field | Type |
|---|---|
| `sample_offset` | `<u8` |
| `sample_count` | `<u8` |
| `boot_epoch` | `<u8` |
| `first_sample_seq` | `<u8` |
| `timing_segment_id` | `<u4` |
| `configuration_index` | `<u4` |

Within a segment, `sample_seq = first_sample_seq + local_index`.

`stream/gaps` represents both sequence-visible and physical sensor loss:

```text
after_sample_offset:u8
boot_epoch:u8
expected_sample_seq:u8
received_sample_seq:u8
missing_sample_count:u8
missing_count_known:u1
gap_kind:u2
estimated_duration_ns:u8
```

A physical FIFO loss is recorded even when firmware output `sample_seq` remains
continuous.

`timing/control_points` contains only the points required to reconstruct time
within a declared error bound:

```text
sample_offset:u8
device_time_us:u8
utc_ns:i8
uncertainty_ns:u8
method:u2
flags:u2
```

Control points are selected adaptively. A fixed decimation such as “one point
per minute” is forbidden unless validation proves the configured maximum
reconstruction error for every interval.

`quality/intervals` is run-length encoded:

```text
sample_offset:u8, sample_count:u8, quality_flags:u4
```

Required Archive quality flags:

```text
0x00000001 TIME_UNCERTAIN
0x00000002 TIME_UNSYNCED
0x00000004 BOUNDARY_UNCERTAIN
0x00000008 SENSOR_LOSS_ADJACENT
0x00000010 SENSOR_RECOVERY
0x00000020 CONFIG_CHANGED
0x00000040 CALIBRATION_UNKNOWN
0x00000080 MEASUREMENT_INVALID
```

### 3.3 Provenance

`/provenance/sources` records every sealed Capture input using:

```text
capture_file_id
relative_name
sha256
sample_count_read
```

The Archive file also records compactor version, validation profile, conversion
time, and an Archive content summary. Packet sequence and raw clock exchanges
are not retained after successful compaction.

## 4. Validation contract

Archive publication requires all of the following:

1. Every committed Capture sample is classified exactly once.
2. Archived `raw_xyz` values are bit-identical and in the same stream order.
3. Segment ranges are ordered, non-overlapping, and cover every archived row.
4. Every discontinuity is either a new segment or an explicit gap.
5. Physical loss events are retained even without a sequence gap.
6. Every sample has a quality classification, including an explicit good
   interval where applicable.
7. Reconstructed control-point time stays within the declared error bound of
   retained Capture timing evidence.
8. Configuration and calibration are defined for every measurement row.
9. The completed file reopens and all HDF5 dataset checks pass.
10. A SHA-256 manifest is written after final publication.

Failure produces a rejected catalog record and preserves Capture inputs. It
never produces a nominally valid partial Archive.

## 5. Compression and checksums

Portable defaults are:

```text
compression = gzip
compression_level = 4
shuffle = true
fletcher32 = true
```

Initial chunk sizes are implementation defaults, not format requirements. They
must be selected by a benchmark covering 125 Hz and 250 Hz sensors, ten-minute
preview reads, full-day sequential reads, conversion time, and final size.

The external manifest uses SHA-256. HDF5 checksums detect chunk corruption;
SHA-256 identifies and verifies the published file as a whole.

### 5.1 Initial layout benchmark

A prototype using recent completed Capture files produced these results before
adding sparse blocks and quality metadata:

| Sensor | Samples | Existing v5 | Raw `int32` XYZ | `float32 m/s²` XYZ | Raw/float |
|---|---:|---:|---:|---:|---:|
| C | 150,031 | 1,623,138 B | 531,329 B | 1,119,250 B | 47.5% |
| D | 75,003 | 846,033 B | 264,060 B | 536,673 B | 49.2% |

Both datasets used identical gzip level 4, shuffle, Fletcher32, and chunking.
All tested legacy `float32` XYZ values round-tripped to integer sensor LSB and
back bit-identically. This is evidence for migration testing, not permission to
use floating point as the new source representation. The complete Archive size
must be benchmarked again after segments, timing, quality, and provenance are
implemented; the table must not be treated as a final storage promise.

## 6. Lifecycle and retention

The catalog state machine is:

```text
DISCOVERED → SEALED → CONVERTING → VALIDATED → REPLICATED
                                           ↘ REJECTED
REPLICATED → RETENTION_ELIGIBLE → CAPTURE_DELETED
```

Conversion is idempotent. Capture retention is 30 days, but deletion remains
manual until a storage backend and verified replication policy are deployed.
The converter never deletes inputs. A separate retention command may delete
only catalog entries explicitly marked `RETENTION_ELIGIBLE`.

## 7. Current timing accuracy

Timing uncertainty is stored per block/control point and is never embedded as a
schema constant. The approximately one-day test observed single-sensor UTC
uncertainty medians around `32.4–32.7 ms`, p95 around `114–117 ms`, and maxima
around `345–414 ms`. Hardware improvements reduce recorded values without a
format change.

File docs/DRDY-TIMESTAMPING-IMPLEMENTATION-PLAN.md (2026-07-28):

# Plan wdrożenia timestampingu DRDY i rotacji HDF5 v5

Status: implementacja offline ukończona; rollout L1–L4 oczekuje
Zasada nadrzędna: żadnych operacji na produkcyjnym czujniku bez osobnej zgody
Strategia migracji: `legacy -> observe -> required`, host przed firmware

## 0. Stan implementacji

Ukończone:

- profile `custom_v2` i `legacy_eval` oraz domyślnie wyłączony feature gate;
- timestamp DRDY, ring SPSC, binder FIFO, recovery barrier i diagnostyka v8;
- propagacja czasu przez środek FIR i niezmienny Burst v2;
- `boot_epoch`, `GetCapabilities` i czterostemplowy `TimeSync`;
- parser v1/v2, modele affine sample/device/host/UTC i holdover;
- tryby hosta `legacy`, `observe`, `required`;
- routing wymagany według UTC akwizycji do półotwartych okien;
- HDF5 v5 z `.partial`, `complete`, kotwicami per pakiet/segment,
  surowymi obserwacjami synchronizacji, journalem ingest i recovery ogona;
- trwała kwarantanna HDF5 dla próbek `unsynced`, `ambiguous` i `late`, dzięki
  której tryb `required` nie przypisuje niepewnych próbek do zwykłego okna i
  nie blokuje commitów noda;
- trwały zapis przed `CommitReadUpTo`, deduplikacja retransmisji oraz atomowa
  publikacja pliku;
- test symulujący 50 ppm dryfu, jitter RTT, retransmisję i zmianę epoki.

Zweryfikowane offline:

- pełny zestaw testów Pythona;
- testy host-side C++;
- build OFF i ON dla slot A/B, direct i bootloader;
- build timestampingu ON dla profilu `legacy_eval`;
- brak flashowania, dostępu do portów i zmian usług systemowych.

Pozostałe bramki wymagają osobnej zgody i sprzętu: L1–L4, pomiar ISR/ringa przy
maksymalnym ODR, fault injection z realnym zanikiem zasilania oraz canary.

## 1. Cel upgrade'u

System ma:

- przypisywać próbki do plików 10-minutowych według czasu akwizycji;
- być odporny na jitter, opóźnienie i retransmisję RS485;
- estymować rzeczywisty okres próbkowania zamiast ufać idealnemu ODR;
- nie interpolować przez restart noda, zmianę konfiguracji ani utratę
  jednoznacznego powiązania DRDY/FIFO;
- umożliwiać czasowe wyrównanie danych z wielu nodów wraz z niepewnością;
- zachować możliwość bezpiecznego działania mieszanej floty starego i nowego
  firmware;
- zapewnić idempotentny zapis i odtwarzalność aktywnego HDF5 po awarii hosta;
- nigdy nie publikować niezweryfikowanego pliku jako kompletnego.

Nie próbujemy programowo zapewnić wspólnej fazy konwersji kilku ADXL355.
Timestamping pozwoli wyrównywać dane po fakcie. Prawdziwa synchronizacja fazowa
wymagałaby wspólnego sygnału synchronizacji/triggera i jest osobnym projektem.

## 2. Niezmienniki bezpieczeństwa

Każdy etap i test musi zachować następujące reguły:

1. Czas odbioru pakietu nigdy nie zastępuje czasu próbki.
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

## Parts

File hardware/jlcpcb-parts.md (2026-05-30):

# JLCPCB parts shortlist

Checked on 2026-05-30. JLCPCB/LCSC stock changes often, so re-check every row
right before ordering or uploading the BOM/CPL.

Goal: every assembled part should have a concrete JLCPCB/LCSC part number and a
matching KiCad footprint before PCB release.

## Critical ICs and special parts

| Block | Candidate part | JLCPCB/LCSC code | JLCPCB status seen | KiCad footprint | Decision |
|---|---|---:|---|---|---|
| MCU | Raspberry Pi `RP2350A` | `C42411118` | In stock | `Package_DFN_QFN:QFN-60-1EP_7x7mm_P0.4mm_EP3.4x3.4mm` | Use this JLCPCB/LCSC part, not the unavailable `C9900206085` assembly placeholder; verify footprint against Raspberry Pi package drawing. |
| Accelerometer | Analog Devices `ADXL355BEZ-RL7` | `C515892` | In stock | `my_footprints:E-14-1_ADI-M` currently placed | Use only after package/land-pattern review; high-cost part. |
| QSPI flash | Winbond `W25Q128JVSIM` | `C97521` | In stock | `Package_SO:SOIC-8_5.3x5.3mm_P1.27mm` | Good match for current schematic value `W25Q128JVS`. |
| Power mux | TI `TPS2121RUXR` | `C485916` | In stock | `my_footprints:RUX0012A` | Good candidate; calculate resistor configuration before release. |
| Buck regulator | TI `TPS62175DQCR` | `C32097` | In stock | `Package_SON:WSON-10-1EP_2x3mm_P0.5mm_EP0.84x2.4mm_ThermalVias` | Good candidate; verify DQC/WSON footprint and datasheet values. |
| Digital LDO | TI `TLV75733PDBVR` | `C485517` | In stock | `Package_TO_SOT_SMD:SOT-23-5` | Good 3V3 digital rail candidate. |
| Analog LDO | TI `TPS7A2033PDBVR` | `C2862740` | In stock | `Package_TO_SOT_SMD:SOT-23-5` | Good low-noise ADXL rail candidate; verify pinout with symbol. |
| RS485 transceiver | TI `THVD1450DR` | `C2671361` | In stock | `Package_SO:SOIC-8_3.9x4.9mm_P1.27mm` | Good match for current footprint. |
| USB ESD | ST `USBLC6-2SC6` | `C7519` | In stock | `Package_TO_SOT_SMD:SOT-23-6` | Good match for current schematic. |
| RS485 TVS | Bourns `CDSOT23-SM712` | `C404012` | In stock | `Package_TO_SOT_SMD:SOT-23` | Preferred known-brand part; cheaper GOODWORK `C21713983` also exists in stock. |
| 12 V TVS | `SMBJ14A` | `C353392` | In stock | `Diode_SMD:D_SMB` | Good candidate if 14 V working standoff fits real input tolerance. |
| Reverse input diode | MDD `SS14` | `C2480` | In stock, Basic | Current schematic uses `Diode_SMD:D_SMA` | Package is SMA/DO-214AC, matching the current footprint family. |
| Input polyfuse | Eaton `PTS181212V150` | `C3760264` | In stock, low stock seen | `Fuse:Fuse_1812_4532Metric` | Current candidate matches the 1812 footprint; verify 12 V/1.5 A is enough. |
| USB-C connector | G-Switch `GT-USB-7051A` | `C2843970` | In stock | `my_footprints:USB_C_Receptacle_G-Switch_GT-USB-7051x` | KiCad library footprint explicitly references this LCSC/JLC part; assembly difficulty is high. |
| RP2350 core inductor | Abracon `AOTA-B201610S3R3-101-T` or equivalent 3.3 uH | TBD | TBD | Current schematic `L2` has no footprint | Needed for RP2350 1V1 supply; choose part from Raspberry Pi guidance or JLC equivalent. |
| Buck inductor | 10 uH shielded power inductor | TBD | TBD | Current schematic `L1` has no footprint | Pick from TPS62175 datasheet/current/ripple requirements. |
| ADXL ferrite | 600R @ 100 MHz 0805 bead | TBD | TBD | `Inductor_SMD:L_0805_2012Metric` | Pick exact bead or use 0R option after review. |

## Passives

Passives should be chosen after the core topology is fixed. Prefer JLCPCB basic
parts where electrical requirements allow it.

| Group | Values in schematic | Footprints | Status |
|---|---|---|---|
| Decoupling caps | `100nF`, `1uF`, `2.2uF`, `4.7uF`, `10uF`, `22uF`, `10nF`, `1nF/2kV` | mostly `C_0603`, `C_0805`, one `C_1206` | Need exact voltage ratings and JLC codes. |
| Resistors | `0`, `27ohm`, `33ohm`, `120ohm`, `1k`, `2.2k`, `5.1k`, `10k`, `47k`, `80k`, `100k`, `523k`, `1M` | `R_0201`, `R_0402`, `R_0603`, `R_0805` | Prefer 0603 unless layout/USB demands smaller; assign JLC codes in BOM pass. |
| LED | status LED | `LED_0603_1608Metric` | Pick color/current and matching resistor. |
| Test points | multiple rails | mixed/no footprint | Need assembly/no-assembly decision; usually not JLC-assembled. |

## Footprint work to do in KiCad

- Assign footprints for schematic parts still missing footprints:
  `J3`, `R2`, `R3`, `R13`, `R14`, `R18`, `R19`, `L1`, `L2`, `JP1`, test points.
- Decide whether to keep all small passives as placed or standardize most
  resistors/caps to 0603 for easier assembly and rework.
- Verify `ADXL355BEZ-RL7` footprint choice: current board places
  `my_footprints:E-14-1_ADI-M`.
- Verify `RP2350A`, `TPS2121RUXR`, `TPS62175DQCR`, USB-C, and connector
  footprints from manufacturer drawings before release.

## Sources to re-check

- JLCPCB parts search: `https://jlcpcb.com/parts`
- LCSC product pages for the `C` codes above
- Raspberry Pi RP2350/RP2350A hardware design files and datasheet
- Analog Devices ADXL355 package drawing
- TI TPS62175, TPS2121, TLV75733, TPS7A20 datasheets

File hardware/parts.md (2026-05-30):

# Parts and footprint decisions

Working list for the RP2350 + ADXL355 node. Use this file as the shared source
of truth before ordering parts or releasing gerbers.

Status values:

- `proposed` - likely choice, still needs verification
- `selected` - approved for schematic/layout
- `verify` - do not release PCB until this row is checked
- `dnp` - footprint kept but normally not populated

| Block | Part | Status | KiCad symbol | Footprint | Notes / links |
|---|---|---:|---|---|---|
| MCU | RP2350A | verify | `MCU_RaspberryPi:RP2350A` | `QFN-60-1EP_7x7mm_P0.4mm_EP3.4x3.4mm` | Verify exposed pad and land pattern against Raspberry Pi hardware files. |
| Accelerometer | ADXL355BEZ-RL7 | selected | local/imported `ADXL355BEZ` | `E-14-1_ADI` | Main vibration sensor. Local footprints also include `E-14-1_ADI-L` and `E-14-1_ADI-M`; release choice must match ADI package drawing. |
| QSPI flash | W25Q128JVS or equivalent 16 MiB flash | proposed | `Memory_Flash:W25Q128JVS` or imported symbol | `SOIC-8_3.9x4.9mm_P1.27mm` | Confirm exact ordering suffix and voltage range. |
| 12 V input connector | 2-pin terminal / connector TBD | proposed | `Connector_Generic:Conn_01x02` | `TerminalBlock_RND_205-00278_1x04_P5.00mm_Vertical` or TBD | Footprint currently looks 4-pin; verify mechanical choice. |
| Input PTC | PTS181212V150 | proposed | `Device:Polyfuse` | `Fuse_1812_4532Metric` | Verify voltage/current rating for field use. |
| Input TVS | SM6T12A or higher working-voltage TVS | verify | `Diode:TVS` | `D_SMB` / `D_SMA` | Check real 12 V tolerance; consider 15 V or 18 V working voltage. |
| Reverse protection | SS14-E3/61T or equivalent | proposed | `Diode:Schottky` | `D_SMA` | Simple V1 approach; MOS/ideal diode can be considered later. |
| Buck regulator | TPS62175DQCR | proposed | `Regulator_Switching:TPS62175DQC` or imported | vendor DQC/VSON-10 footprint | Calculate feedback, inductor, caps from datasheet before layout release. |
| Power mux | TPS2121RUXR | selected | local/imported `TPS2121RUXR` | `RUX0012A` | Configure priority, thresholds, current limit; do not leave control pins floating. |
| Digital 3.3 V LDO | TLV75733 | proposed | `Regulator_Linear:TLV75733PDBV` | `SOT-23-5` | Powers MCU I/O, flash, RS485, LEDs. |
| Analog 3.3 V LDO | TPS7A2033 or ADP150-3.3 | proposed | package-specific symbol | `SOT-23-5` or exact vendor footprint | Low-noise rail for ADXL355. |
| ADXL supply filter | MPZ2012S601AT000 or 0R option | proposed | `Device:Ferrite_Bead` | `L_0805_2012Metric` | Keep replacement option in case ferrite/caps resonate. |
| RS485 transceiver | THVD1450DR | proposed | `Interface_UART:THVD1450DR` | `SOIC-8_3.9x4.9mm_P1.27mm` | 3.3 V logic rail. |
| RS485 TVS | CDSOT23-SM712 | proposed | `Diode:SM712_SOT23` | `SOT-23` | Protect A/B lines near connector. |
| USB ESD | USBLC6-2SC6 or TPD2EUSB30 | proposed | package-specific symbol | `SOT-23-6` / exact package | Match selected part and connector routing. |
| USB-C connector | G-Switch GT-USB-7051x or TBD | verify | `Connector:USB_C_Receptacle_USB2.0_16P` | `USB_C_Receptacle_G-Switch_GT-USB-7051x` | Verify mechanical fit and availability. |
| Programming/debug header | SWD header TBD | proposed | `Connector_Generic` | `PinHeader_1x02_P2.54mm_Vertical` or TBD | Pick final pin count and orientation. |

## Links to fill in

Add order links here once the exact MPN is chosen:

| Part | Supplier | Link | Notes |
|---|---|---|---|
| RP2350A | TBD | TBD | |
| ADXL355BEZ-RL7 | LCSC / distributor | TBD | LCSC reference noted earlier: C515892. |
| TPS2121RUXR | LCSC / distributor | TBD | LCSC reference noted earlier: C485916. |
| TPS62175DQCR | LCSC / distributor | TBD | LCSC reference noted earlier: C32097. |
| SS14-E3/61T | LCSC / distributor | TBD | LCSC reference noted earlier: C47460. |

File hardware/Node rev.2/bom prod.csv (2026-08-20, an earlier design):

Id | Designator | Footprint | Quantity | Designation | Supplier and ref
1 | C2 | CP_Radial_D8.0mm_P3.50mm | 1 | 220uF
2 | C3, C6 | C_Disc_D5.0mm_W2.5mm_P5.00mm | 2 | 100nF
3 | C4 | CP_Radial_D5.0mm_P2.00mm | 1 | 10uF
4 | C5 | CP_Radial_D8.0mm_P3.50mm | 1 | 470uF
5 | D1 | D_DO-15_P10.16mm_Horizontal | 1 | P6KE15A-DIO
6 | F1 | Fuse_BelFuse_0ZRE0016FF_L9.9mm_W3.8mm | 1 | MF-R050
7 | J1, J2 | TerminalBlock_4Ucon_1x02_P3.50mm_Horizontal | 2 | Screw_Terminal_01x02
8 | L1 | L_Axial_L5.3mm_D2.2mm_P7.62mm_Horizontal_Vishay_IM-1 | 1 | FRH035080-A
9 | MOD1 | EVAL-ADXL355Z | 1 | ~
10 | PICO1 | RaspberryPi_Pico_Common_Unspecified | 1 | RaspberryPi_Pico
11 | U1 | Converter_DCDC_Murata_OKI-78SR_Vertical | 1 | OKI-78SR-5_1_5-W36-C
12 | U2 | TO-92_Inline_Wide | 1 | LP2950CZ-3.3/NOPB

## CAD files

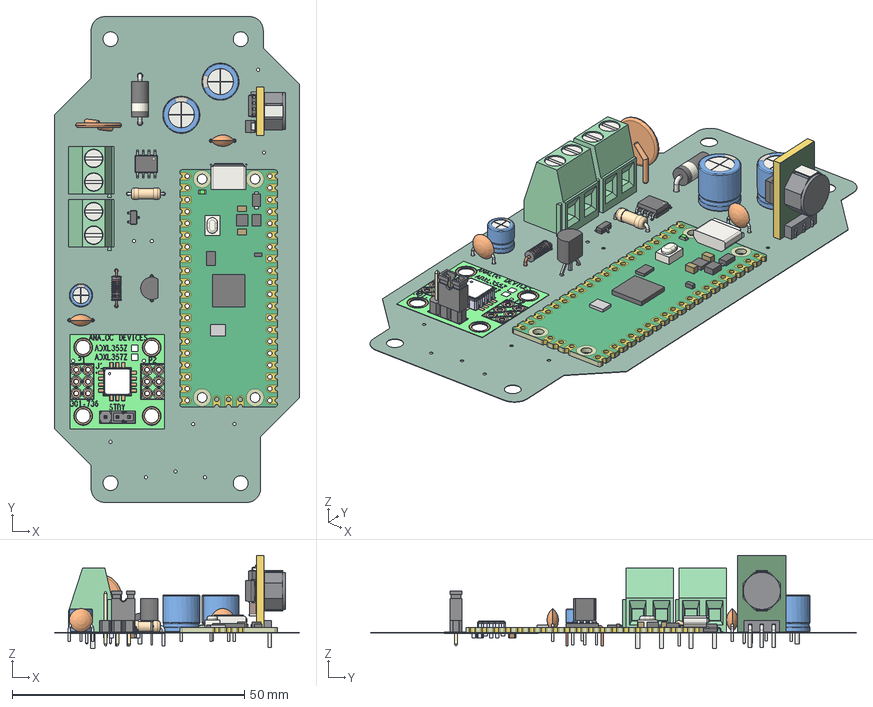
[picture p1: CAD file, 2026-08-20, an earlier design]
hardware/Node rev.2/3d_model.step
52.7 x 104.5 x 20.0 mm
TerminalBlock_Phoenix_MKDS-1,5-2-5.08_1x02_P5.08mm_Horizontal x 2
SOIC-8_3.9x4.9mm_P1.27mm
A_0ZRE0016FF
R_Axial_DIN0207_L63mm_D25mm_P762mm_Horizontal
D_DO-15_P10.16mm_Horizontal
CP_Radial_D80mm_P350mm x 2
C_Disc_D50mm_W25mm_P500mm x 2
C¯SCL
DRDY
INT1
INT2
MISO/ASEL
MOSI/SDA
RESERVED
SCLK/VSSIO
V1P8ANA
V1P8DIG
VDDIO
VSS
VSSIO
VSUPPLY
SILKSCREEN_TOP
PASTEMASK_TOP
SOLDERMASK_TOP
Dielectric
SOLDERMASK_BOTTOM
PASTEMASK_BOTTOM
SILKSCREEN_BOTTOM
2556P03UA00
CAPC1608X95 x 8
LCC127P600X600X240-14
RESC1608X50 x 2
L_Axial_L5.3mm_D2.2mm_P7.62mm_Horizontal_Vishay_IM-1
SOT-23-3
Converter_DCDC_muRata_OKI-78SR_vertical
CP_Radial_D50mm_P200mm
TO-92_Inline_Wide
RaspberryPi_Pico_Module_KiCad
Untitled_PCB

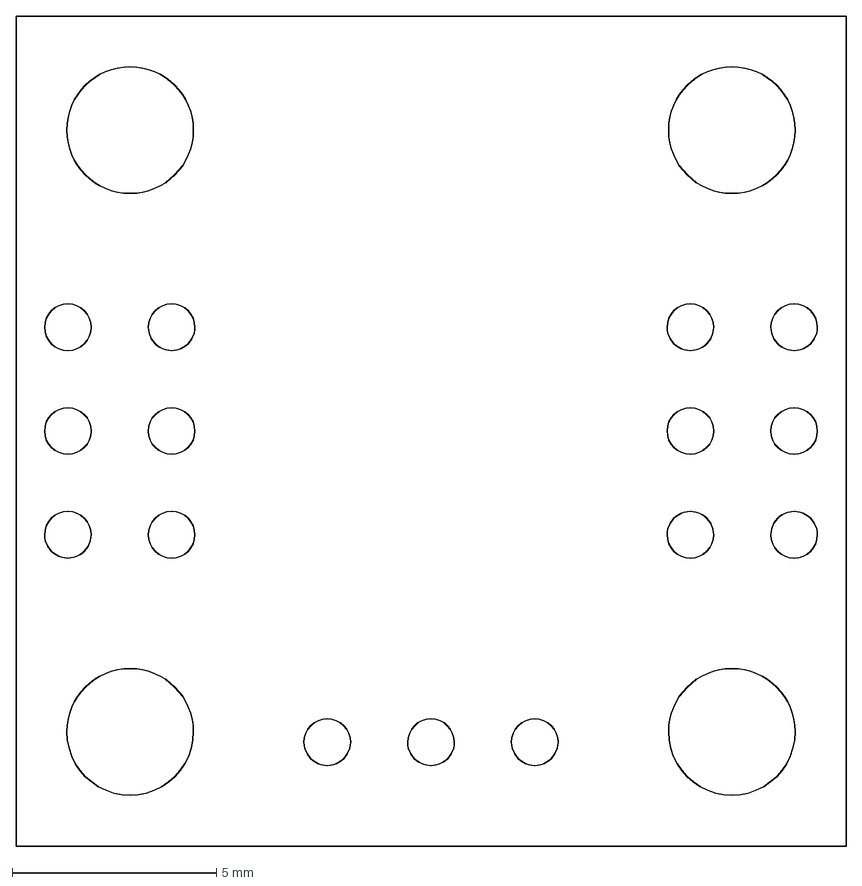
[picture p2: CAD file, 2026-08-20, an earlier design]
hardware/Node rev.2/Unnamed-EVAL-ADXL355Z.brdDielectric.dxf
20.3 x 20.3 mm

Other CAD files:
hardware/Node rev.2/EVAL-ADXL355Z.dxf
hardware/Node rev.2/.step

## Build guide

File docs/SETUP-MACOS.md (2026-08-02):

# Stanowisko macOS: KiCad, firmware i host

Mac może być pełnym stanowiskiem developerskim dla KiCad, firmware'u i
narzędzi hosta uruchamianych w terminalu. Produkcyjne usługi `systemd`, reguły
`udev` i sterowniki kernela Linux pozostają na komputerach Linux.

## 1. Zależności systemowe

Repo deklaruje narzędzia, ale ich nie vendoryzuje. Po zainstalowaniu Homebrew:

```bash
brew bundle --file Brewfile
```

Instalowane są KiCad, Git, CMake, Ninja, Python, `arm-none-eabi-gcc` i
`picotool`. KiCad jest oficjalnie dostępny dla macOS, a Homebrew dostarcza
gotowe pakiety narzędzi ARM i picotool:

- https://www.kicad.org/download/macos/
- https://formulae.brew.sh/cask/kicad
- https://formulae.brew.sh/formula/arm-none-eabi-gcc
- https://formulae.brew.sh/formula/picotool

Sprawdzenie stanowiska jest odczytowe:

```bash
./tools/check_macos.sh
```

Biblioteki hosta mają zgodne zakresy wersji w
`host/requirements-recorder.txt`; nie instalujemy ich globalnie, tylko w
ignorowanym `host/.venv`.

## 2. Pico SDK poza repozytorium

Projekt jest zweryfikowany z wersją zapisaną w `node/PICO_SDK_VERSION`. SDK
trzymamy poza repo, przykładowo:

```bash
mkdir -p "$HOME/Developer"
git clone --branch 2.2.0 --depth 1 \
  https://github.com/raspberrypi/pico-sdk.git \
  "$HOME/Developer/pico-sdk"
export PICO_SDK_PATH="$HOME/Developer/pico-sdk"
```

Eksport można dodać do `~/.zprofile`. Oficjalny Pico SDK obsługuje wskazanie
zewnętrznej lokalizacji przez `PICO_SDK_PATH`:
https://github.com/raspberrypi/pico-sdk

Budowanie pozostaje takie samo na Intel i Apple Silicon:

```bash
cmake -S node --preset board-v2
cmake --build --preset board-v2
```

Artefakty powstają w ignorowanym `node/build/`. Dla V1 używamy osobnego presetu
`board-v1` i katalogu `node/build.v1`.

## 3. Python i lokalna konfiguracja hosta

```bash
./host/tools/setup_host.sh rpi-sanok
cp host/configs/host_system.macos.example.json host/system_config.json
./hostctl paths --init
```

Przed uruchomieniem zmień `extends`, jeśli pracujesz z innym systemem, wpisz
rzeczywiste porty `/dev/cu.*` i włącz tylko fizycznie podłączone kanały.
Szablon używa `var/run` zamiast linuksowego `/run/sensor-system`.

Lista portów z identyfikatorami USB:

```bash
host/.venv/bin/python -m serial.tools.list_ports -v
```

Narzędzia `ping`, `config`, `recorder`, `supervisor`, `dashboard` i `operator`
mogą działać lokalnie. Supervisor i panele uruchamiamy na Macu w terminalu;
sterowanie usługami `systemd` jest funkcją produkcyjnego hosta Linux.

## 4. USB-RS485 i CH9344

Nazwa handlowa „USB-RS485” nie określa sterownika — decyduje chipset. Po
podłączeniu konwertera sprawdź:

```bash
system_profiler SPUSBDataType
host/.venv/bin/python -m serial.tools.list_ports -v
```

Obecny ośmiokanałowy konwerter Sanoka używa CH9344. Oficjalny katalog WCH nie
udostępnia sterownika macOS dla CH9344, a pakiet CH341SER_MAC nie wymienia tego
układu. Nie instalujemy przypadkowych, niepodpisanych sterowników z kopii w
Internecie:

- https://www.wch-ic.com/downloads/category/67.html
- https://www.wch-ic.com/downloads/CH341SER_MAC_ZIP.html

Mamy dwa obsługiwane warianty:

1. Do lokalnych testów użyć konwertera tworzącego port `/dev/cu.*` na macOS
   (najlepiej standard USB CDC albo chipset z oficjalnym sterownikiem dla
   używanej wersji macOS).
2. Zostawić CH9344 podłączony do Raspberry Pi/Linux i pracować z Maca przez Git,
   SSH oraz panel WWW hosta. To jest bezpieczniejszy wariant dla pełnych ośmiu
   kanałów.

Jeśli po podłączeniu CH9344 nie powstaną wszystkie porty `/dev/cu.*`, problemu
nie rozwiązuje zmiana konfiguracji repo — potrzebny jest kompatybilny sterownik
lub inny konwerter.

## 5. KiCad

Otwieraj projekt `hardware/KiCad - node V2/RP2350.kicad_pro`. Źródła projektu i
lokalne biblioteki są wersjonowane; cache, backupy i wygenerowane pliki
produkcyjne są ignorowane. Na macOS `kicad-cli` znajduje się wewnątrz pakietu
aplikacji pod `/Applications/KiCad/KiCad.app/Contents/MacOS/kicad-cli`.

Przed rozpoczęciem pracy wykonaj `git pull`, a przed commitem sprawdź, czy nie
dodajesz backupów, Gerberów ani lokalnych tabel bibliotek.

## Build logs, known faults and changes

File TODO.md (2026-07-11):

# TODO

Last updated: 2026-07-11

## Priority Now

- Investigate the electrical/SPI cause of the 21 confirmed lost samples on `line-g`.
- Add a multi-record flash diagnostic journal that survives power loss, has wear limits,
  and can be acknowledged record-by-record only after durable host archival.
- Surface durable diagnostic events and plain-language loss alarms in the dashboard.
- Investigate `INT1` behavior on `line-e`.
- Confirm whether `INT1` carries valid FIFO watermark interrupts or false edges.
- Validate firmware `0.3.8` rejection of false `INT1` edges on line E.
- Confirm that fallback counters increase without FIFO overrun when INT1 is disconnected.

## Sensor / Firmware

- Run a short dedicated `INT1` debug test without normal FIFO servicing.
- Verify if `INT1` still fires while:
  - `STATUS_FIFO_FULL=0`
  - `FIFO_ENTRIES=0`
- Compare `line-e` against a known-good line on the same firmware version.
- Re-check `INT_MAP`, `FIFO_SAMPLES`, `STATUS`, and `FIFO_ENTRIES` behavior after longer runtime.
- Decide whether `INT1` should remain production-critical after the protected fallback test.
- Review long-term counter design for 24/7 operation:
  - `uptime_ms` wraps after about 49.7 days
  - several diagnostic counters are still `uint32_t`
- Identify which counters should be upgraded to `uint64_t`.
- Consider adding explicit wrap-safe reporting for long-lived systems.
- Add a hardware-in-the-loop test for partial SPI transfer and FIFO axis mismatch.

## Hardware / Electrical

- Verify physical mapping again:
  - `INT1 -> GP10`
  - `DRDY -> GP11`
- Check if `INT1` line has ringing, floating behavior, or injected noise.
- Check whether the extra edge appears immediately after FIFO service and INT1 deassertion.
- Confirm resistor / pull configuration on the PCB and sensor side.
- Compare behavior on alternate lines/boards with the same firmware.
- If possible, inspect `INT1` waveform with external measurement equipment.

## Host / Diagnostics

- Keep `dump-diagnostics` and recorder logs aligned with newest firmware payloads.
- Preserve the recorder's durable `diagnostics/<channel>.events.jsonl` files during data retention and export.
- Add `boot_id` to diagnostic event identity so host restarts can deduplicate archived node events safely.
- Surface `spurious_int1`, `fifo_overruns`, `fifo_discarded`, and `fifo_loss_unknown` in the dashboard.
- Continue validating persistent diagnostic record parsing after format extensions.
- Decide whether some debug fields should be shown in dashboard / operator panel.
- Add a compact diagnostic summary command for quick field debugging.

## Reliability / Operations

- Define the final 24/7 recovery strategy:
  - when to soft-recover
  - when to restart node only
  - when to restart a whole acquisition pipeline
- Add policy for repeated `NoData` that preserves logs before recovery.
- Review safe update behavior while recorder/supervisor is active.
- Confirm the update guard covers all real production conflict cases.

## Documentation

- Write down the current interrupt model:
  - what uses `INT1`
  - what uses `DRDY`
  - when fallback is allowed
- Document sample sequence behavior and long-term limits.
- Document known limitations for long-running uptime and counters.
- Link detailed line-E investigation notes from project docs.

## Useful References

- Detailed line-E notes:
  - [diagnostics/2026-07-09_line-e_int1_fifo_debug.md](/home/anone/pico-projects/diagnostics/2026-07-09_line-e_int1_fifo_debug.md)

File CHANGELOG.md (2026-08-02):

# Changelog

## Unreleased

- Split host configuration into product-wide `common.json`, tracked physical
  system profiles and ignored per-host overlays.
- Added a versioned `var/` directory skeleton and documented the canonical
  monorepo layout for consistent clones and Codex sessions.
- Removed the locally required CH9344 vendor driver sources from the product
  repository; the Sanok profile now records the driver as an external host
  dependency.
- Removed the broken `pico-sdk` gitlink; the SDK remains an ignored external
  dependency selected through `PICO_SDK_PATH`.
- Added a Homebrew dependency manifest, macOS environment checker, portable
  runtime overlay and setup guide for KiCad, Pico SDK and USB-RS485 workflows.
- Replaced historical `adxl355-*` systemd unit names with product-wide
  `sensor-system-*` services and standardized production storage under `var/`.
- Added a reproducible read-only SFTP layout exposing the canonical `var/`
  tree instead of the retired top-level `data/` directory.

Wersjonowanie projektu stosuje format `MAJOR.MINOR.PATCH`. Numer wydania jest
wspólny dla narzędzi hosta i firmware'u.

## [0.4.1] - 2026-08-02

### Dodano

- Niezmienna `board_revision` raportowana przez konfigurację, status i
  commissioning noda oraz zapisywana w Capture/Archive.
- Oddzielne presety buildów V1 i V2 oraz kontrola zgodności rewizji przed
  aktualizacją RS485.
- Wspólny lokalny układ `var/recordings`, `var/archive`, `var/diagnostics` i
  `var/log`, wraz z komendą `hostctl paths`.

### Poprawiono

- Build bieżącej instalacji używa profilu `board_v2`; V1 jest budowany w
  osobnym katalogu presetem `board-v1`. Pakiety zapisują profil i liczbową
  rewizję sprzętu.
- Kanoniczne profile `board_v2` i `board_v1` zastępują mylące nazwy historyczne;
  stare nazwy pozostają aliasami zachowującymi swoje dotychczasowe zestawy pinów.
- Skorygowano odwrócone przypisanie zestawów pinów: działające okablowanie
  SCK 14 / MOSI 15 / DRDY 11 / INT1 10 jest teraz jednoznacznie `board_v2`.
- Zamknięte snapshoty i surowe logi diagnostyczne usunięto z drzewa produktu;
  kolejne zrzuty są ignorowane przez Git.
- Usunięto podwójny multicore lockout wokół `flash_safe_execute()`, który mógł
  zatrzymać trial boot na zapisie metadanych i wywołać rollback watchdogiem.
- Sterowanie pojedynczym workerem jest dostępne przez `hostctl channel
  stop/start`, a bootloader respektuje potwierdzony stan zatrzymania supervisora.
- Konfiguracja hosta obsługuje śledzony base i ignorowany lokalny overlay,
  scalając kanały po nazwie i nody po adresie.
- Dodano odczytową komendę `hostctl doctor` sprawdzającą konfigurację, porty,
  sterownik, storage, supervisor, firmware, rewizję płytki i przepływ danych.

## [0.4.0] - 2026-08-02

### Dodano

- Kanoniczny Capture HDF5 v1 z surowym signed-24 w kontenerze `int32`,
  dziennikiem commitów, czasem próbek, niepewnością, konfiguracją i jakością.
- Minimalny Archive HDF5 v1, deterministyczny kompaktor, walidatory oraz
  manifest SHA-256.
- Jawne tożsamości kanałów 1–8 i tymczasowe etykiety sensorów A–H.
- Raportowanie profilu filtra, decymacji, rewizji konfiguracji oraz licznika
  nasyceń kodowania signed-24.

### Poprawiono

- Deduplikacja obejmuje całą sesję Capture i zamknięte okna, dzięki czemu
  retransmisja nie tworzy kopii `late`/`unresolved`.
- Kontrolowane zatrzymanie pozostawia trwające okno UTC jako odzyskiwalny
  `.partial`; restart kontynuuje ten sam plik, a zaległe okna uszczelnia
  atomowo po upływie ich czasu.
- Trwała konfiguracja v3 jest migrowana do v4 bez utraty adresu i ustawień.
- Aktualizacja A/B pozostaje odzyskiwalna, gdy adres serwisowy ma wartość 0.

### Wdrożenie

- Capture v1 działa w trybie fail-closed i pozostaje za przełącznikiem
  `storage.capture_schema`; aktywacja następuje po aktualizacji firmware'u.
- Próba end-to-end na linii D objęła firmware v0.4.0, Capture v1, Archive v1 i
  walidację SHA-256.

## [0.3.10] - 2026-07-15

### Dodano

- Alarm dla czujnika, który odpowiada, ale przestał dostarczać próbki, wraz z
  komunikatem o odzyskaniu przepływu.
- Liczniki węzłów odbierających próbki w dashboardzie i rozszerzony endpoint
  health.
- Kontrolowany restart firmware'u pojedynczego czujnika z dashboardu.
- Skrypt przygotowujący środowisko hosta oraz pełną kontrolę release'u.

### Poprawiono

- Recorder jest ponownie uruchamiany także wtedy, gdy restart węzła się nie uda.
- Testy C++ firmware'u można uruchamiać niezależnie od bieżącego katalogu.
- Ujednolicono numery wersji firmware'u, recordera, supervisora, dashboardu i
  panelu operatora.
- Konfiguracja konkretnej instalacji i lokalne unity systemd nie są częścią
  dystrybucji produktu.

### Znane ograniczenia

- Dashboard i panel operatora nie mają wbudowanego uwierzytelniania; powinny być
  dostępne wyłącznie w zaufanej, chronionej sieci.
- Długotrwała praca nadal wymaga decyzji dotyczącej liczników 32-bitowych i
  jawnej obsługi zawinięcia `uptime_ms` po około 49,7 dnia.
- Diagnostyka elektryczna linii E i przyczyna potwierdzonych utraconych próbek na
  linii G pozostają zadaniami sprzętowymi przed ostatecznym odbiorem instalacji.

## [0.3.9] - 2026-07-11

- Trwała diagnostyka utraty próbek i alarmy po stronie hosta.

## [0.3.8] - 2026-07-10

- Wzmocniona obsługa FIFO i rozszerzona telemetria firmware'u.

## [0.3.0] - 2026-05-24

- Pierwszy pakowany release firmware'u z obrazem fabrycznym i aktualizacją A/B.

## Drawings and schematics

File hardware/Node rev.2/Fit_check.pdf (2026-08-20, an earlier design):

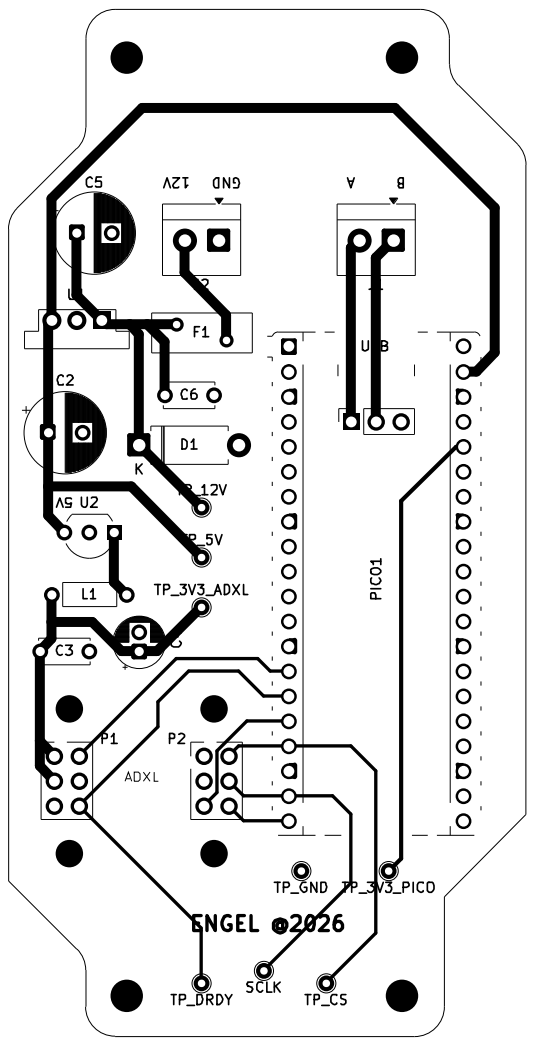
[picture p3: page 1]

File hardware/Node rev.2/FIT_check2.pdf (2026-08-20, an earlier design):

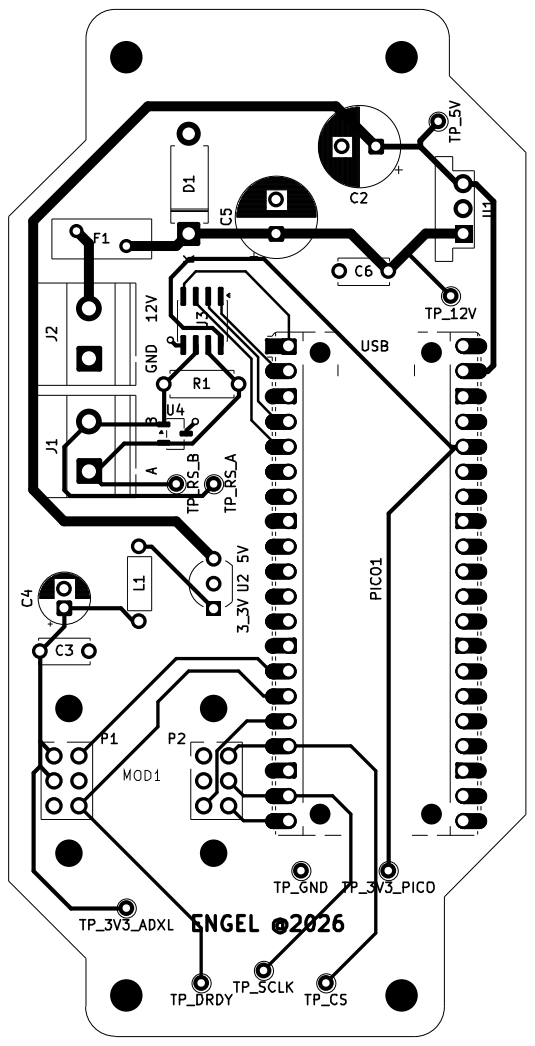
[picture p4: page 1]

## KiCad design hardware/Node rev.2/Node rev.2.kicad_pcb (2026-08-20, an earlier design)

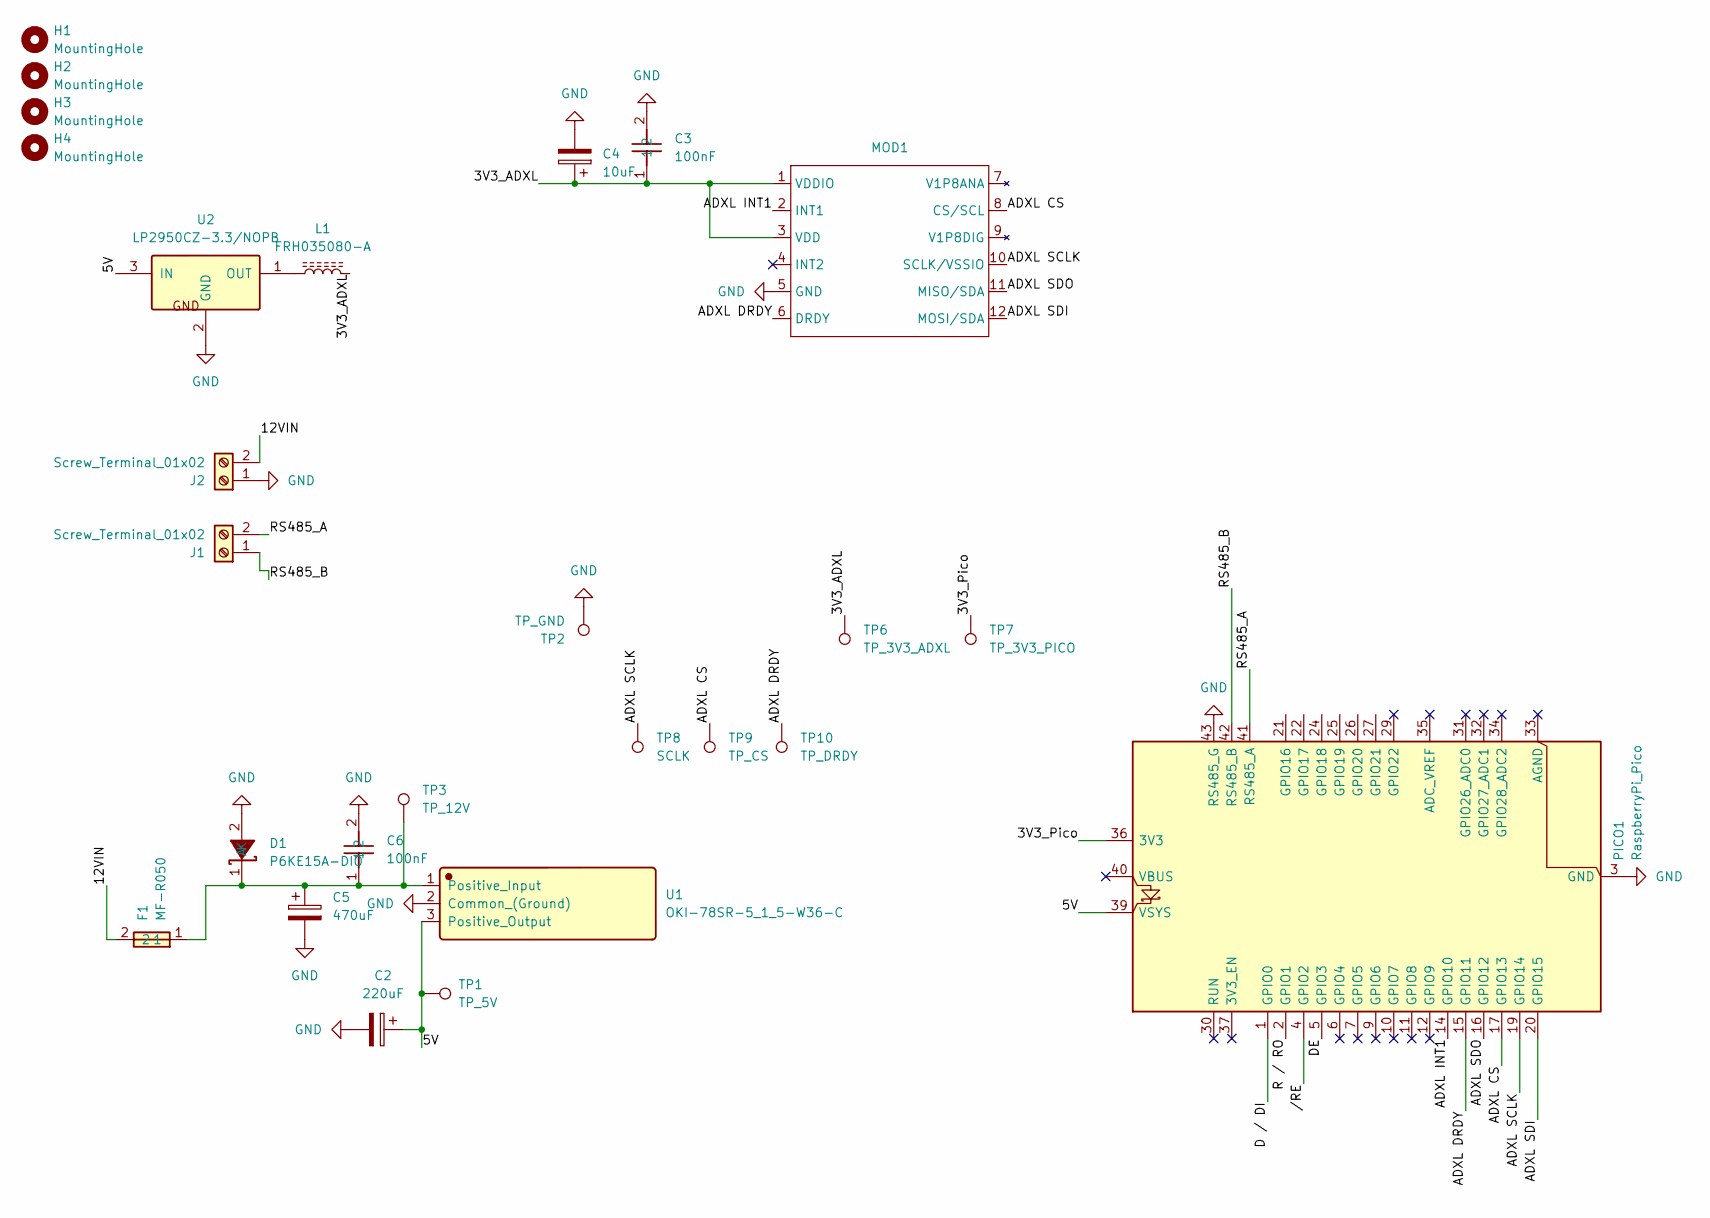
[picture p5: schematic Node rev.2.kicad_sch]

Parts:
C2: 220uF; CP_Radial_D8.0mm_P3.50mm
C3, C6: 100nF; C_Disc_D5.0mm_W2.5mm_P5.00mm; Manufacturer Part K104K10X7RF5UH5; LCSC C2979769
C4: 10uF; CP_Radial_D5.0mm_P2.00mm; MFR# KM 10U/50V
C5: 470uF; CP_Radial_D8.0mm_P3.50mm
D1: P6KE15A-DIO; D_DO-15_P10.16mm_Horizontal; Manufacturer Part P6KE15A-DIO
F1: MF-R050; Fuse_BelFuse_0ZRE0016FF_L9.9mm_W3.8mm; Manufacturer Part MF-R050; LCSC C208476
H1, H2, H3, H4: MountingHole
J1, J2: Screw_Terminal_01x02; TerminalBlock_4Ucon_1x02_P3.50mm_Horizontal
L1: FRH035080-A; L_Axial_L5.3mm_D2.2mm_P7.62mm_Horizontal_Vishay_IM-1
MOD1: EVAL-ADXL355Z
PICO1: RaspberryPi_Pico; RaspberryPi_Pico_Common_Unspecified
TP1: TP_5V; TestPoint_THTPad_D1.5mm_Drill0.7mm
TP2: TP_GND; TestPoint_THTPad_D1.5mm_Drill0.7mm
TP3: TP_12V; TestPoint_THTPad_D1.5mm_Drill0.7mm
TP6: TP_3V3_ADXL; TestPoint_THTPad_D1.5mm_Drill0.7mm
TP7: TP_3V3_PICO; TestPoint_THTPad_D1.5mm_Drill0.7mm
TP8: SCLK; TestPoint_THTPad_D1.5mm_Drill0.7mm
TP9: TP_CS; TestPoint_THTPad_D1.5mm_Drill0.7mm
TP10: TP_DRDY; TestPoint_THTPad_D1.5mm_Drill0.7mm
U1: OKI-78SR-5_1_5-W36-C; Converter_DCDC_Murata_OKI-78SR_Vertical; Manufacturer Part OKI-78SR-5/1.5-W36-C; LCSC C6134431
U2: LP2950CZ-3.3/NOPB; TO-92_Inline_Wide; Manufacturer Part LP2950CZ-3.3/LFT3

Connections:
/3V3_ADXL: C3.1, C4.1, L1.2, MOD1.1 (VDDIO), MOD1.3 (VDD), TP6.1 (1_1)
/3V3_Pico: PICO1.36 (3V3), TP7.1 (1_1)
/5V: C2.1, PICO1.39 (VSYS), TP1.1 (1_1), U1.3 (Positive_Output), U2.3 (IN)
/12VIN: F1.2, J2.2
/ADXL CS: MOD1.8 (CS/SCL), PICO1.17 (GPIO13), TP9.1 (1_1)
/ADXL DRDY: MOD1.6 (DRDY), PICO1.15 (GPIO11), TP10.1 (1_1)
/ADXL INT1: MOD1.2 (INT1), PICO1.14 (GPIO10)
/ADXL SCLK: MOD1.10 (SCLK/VSSIO), PICO1.19 (GPIO14), TP8.1 (1_1)
/ADXL SDI: MOD1.12 (MOSI/SDA), PICO1.20 (GPIO15)
/ADXL SDO: MOD1.11 (MISO/SDA), PICO1.16 (GPIO12)
/D / DI: PICO1.1 (GPIO0)
/DE: PICO1.5 (GPIO3)
/R / RO: PICO1.2 (GPIO1)
/RS485_A: J1.2, PICO1.41 (RS485_A)
/RS485_B: J1.1, PICO1.42 (RS485_B)
//RE: PICO1.4 (GPIO2)
GND: C2.2, C3.2, C4.2, C5.2, C6.2, D1.2 (A), J2.1, MOD1.5 (GND), PICO1.3 (GND), PICO1.8 (GND), PICO1.13 (GND), PICO1.18 (GND), PICO1.23 (GND), PICO1.28 (GND), PICO1.38 (GND), PICO1.43 (RS485_G), TP2.1 (1_1), U1.2 (Common_(Ground)), U2.2 (GND)
unnamed: C5.1, C6.1, D1.1 (K), F1.1, TP3.1 (1_1), U1.1 (Positive_Input)
unnamed: L1.1, U2.1 (OUT)

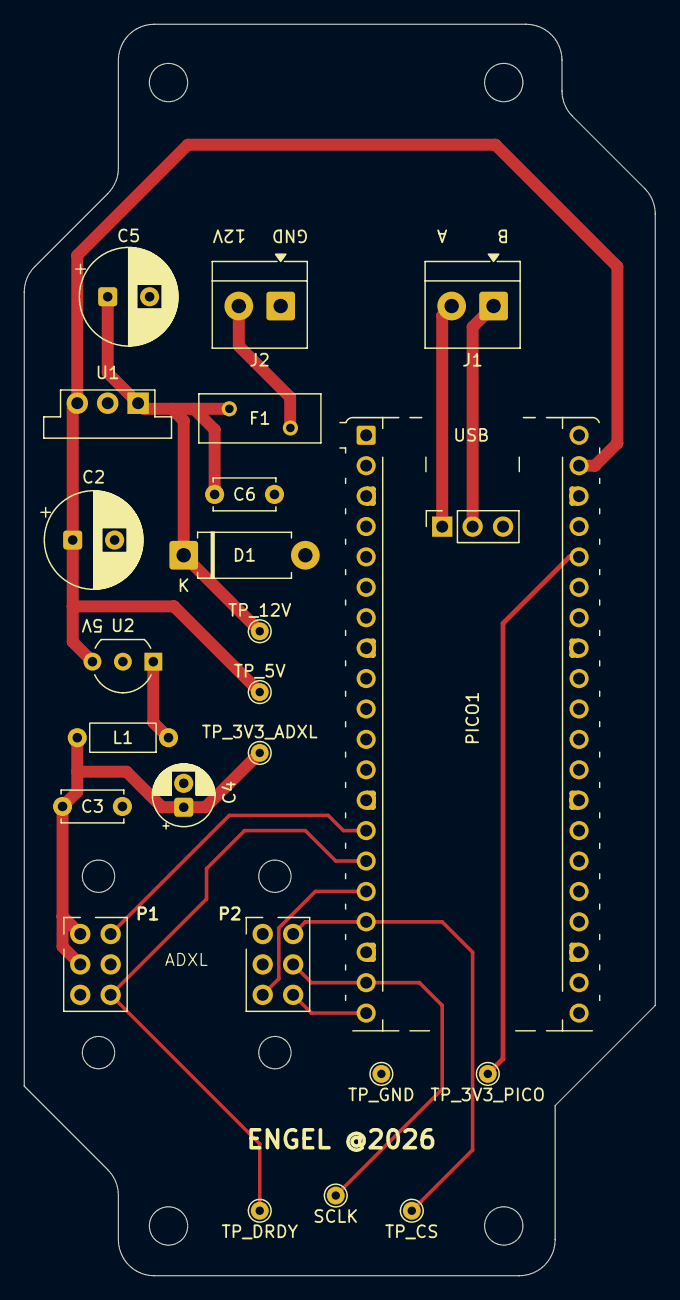
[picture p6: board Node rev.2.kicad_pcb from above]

Board: 2 copper layers, 52.7 x 104.5 mm, 26 parts (0 on the bottom side), 15 nets.

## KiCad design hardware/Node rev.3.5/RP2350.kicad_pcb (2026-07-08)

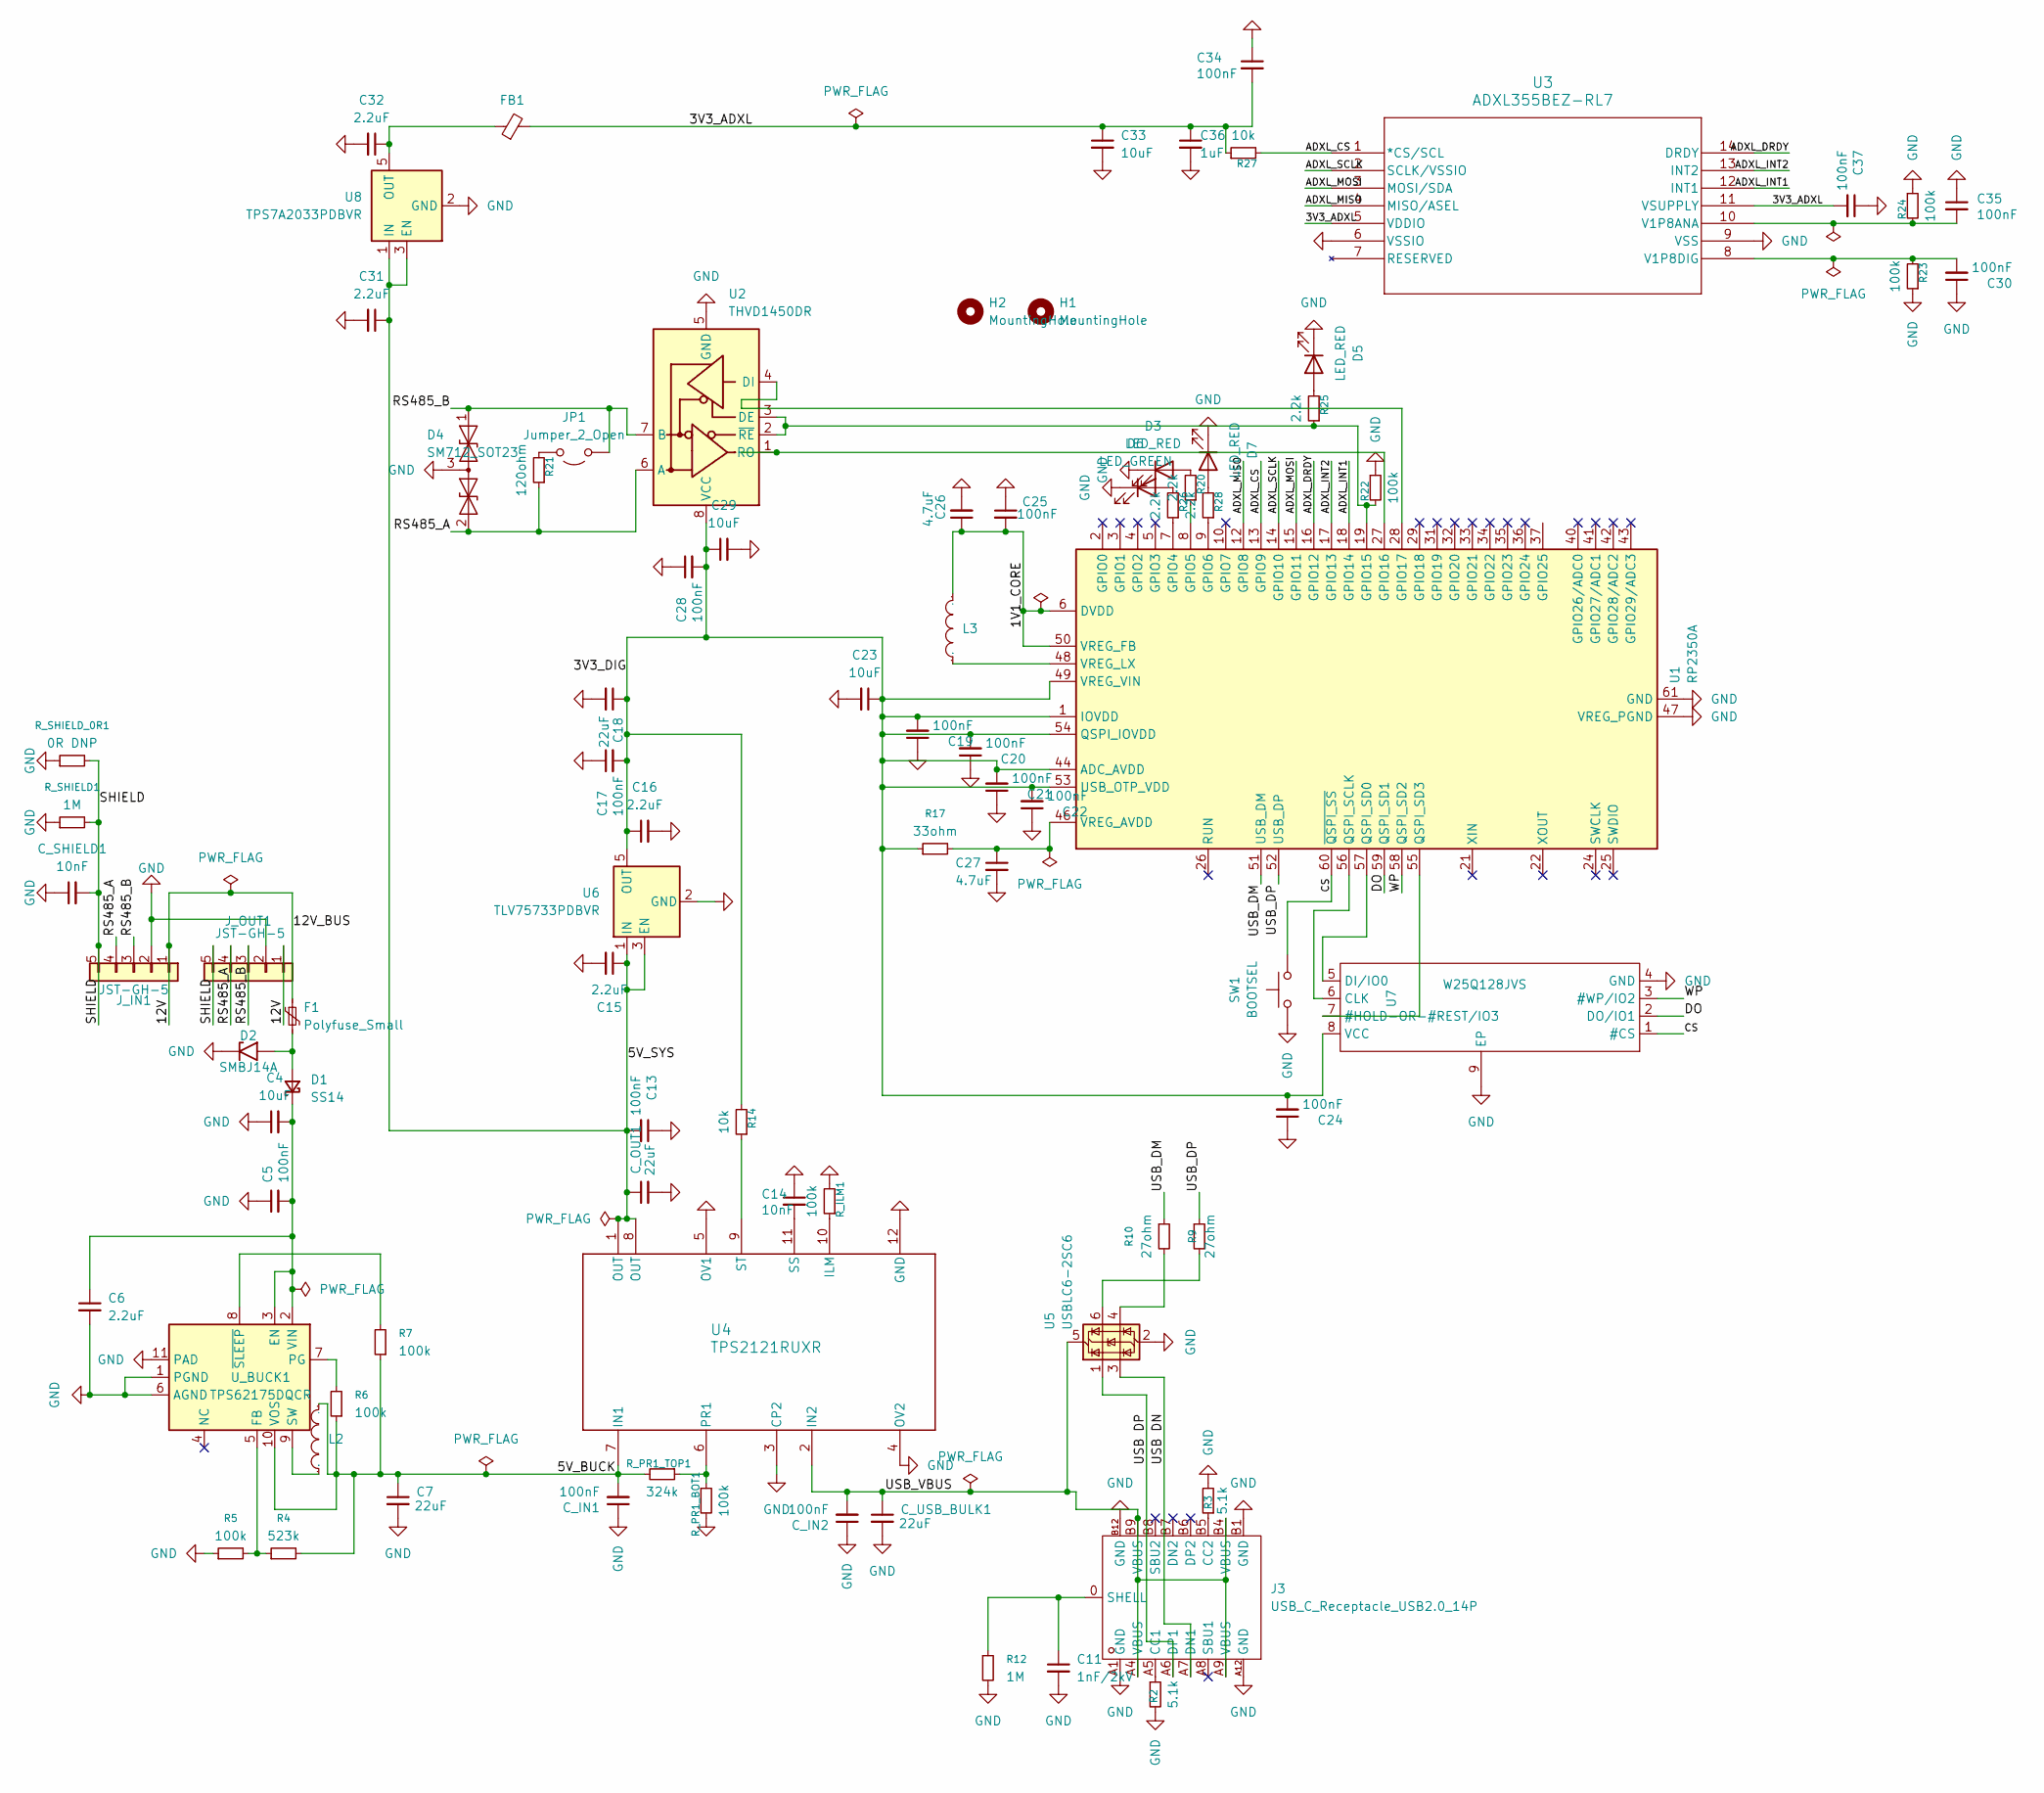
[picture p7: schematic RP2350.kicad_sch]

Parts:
C4, C29, C33: 10uF; C_0805_2012Metric
C5, C17, C28: 100nF; C_0603_1608Metric
C6, C15, C16, C31, C32: 2.2uF; C_0805_2012Metric
C7, C18: 22uF; C_0805_2012Metric
C11: 1nF/2kV; C_1206_3216Metric
C13, C19, C20, C21, C22, C24, C25, C30, C34, C35, C37: 100nF; C_0402_1005Metric
C14: 10nF; C_0603_1608Metric
C23: 10uF; C_0603_1608Metric
C26: 4.7uF; C_0603_1608Metric
C27: 4.7uF; C_0805_2012Metric
C36: 1uF; C_0603_1608Metric
C_IN1, C_IN2: 100nF; C_0402_1005Metric
C_OUT1: 22uF; C_0805_2012Metric
C_SHIELD1: 10nF; C_0805_2012Metric
C_USB_BULK1: 22uF; C_0805_2012Metric
D1: SS14; D_SMA; Manufacturer Part SS14; JLCPC# SS14
D2: SMBJ14A; D_SMB; Manufacturer Part SMBJ14A; JLCPC# C29937
D3, D5, D7: LED_RED; LED_0603_1608Metric; Manufacturer Part KT-0603R; JLCPC# 0603
D4: SM712_SOT23; SOT-23; Manufacturer Part SM712.TCT; JLCPC# C12067
D6: LED_GREEN; LED_0805_2012Metric; Manufacturer Part KT-0805G; JLCPC# C2297
F1: Polyfuse_Small; Fuse_1812_4532Metric; Manufacturer Part 1812L150/24MR; JLCPC# C142805
FB1: FerriteBead_S; L_0805_2012Metric; Manufacturer Part MPZ2012S601AT000; JLCPC# C21519
H1, H2: MountingHole; MountingHole_2.5mm
J3: USB_C_Receptacle_USB2.0_14P; USB-C-SMD_GT-USB-7051A; Manufacturer Part GT-USB-7051A; LCSC Part Name Type-C 母 立贴
JP1: Jumper_2_Open; SolderJumper-2_P1.3mm_Open_Pad1.0x1.5mm
J_IN1: JST-GH-5; CONN-SMD_BM05B-GHS-TBT; Manufacturer Part BM05B-GHS-TBT(LF)(SN)(N); JLCPC# C189891
J_OUT1: JST-GH-5; CONN-SMD_BM05B-GHS-TBT; Manufacturer Part BM05B-GHS-TBT(LF)(SN)(N); JLCPC# C189891
L2: 10uH; FXL0420-100-MIND-SMD_L4.4-W4.2; Manufacturer Part FXL0420-100-M; LCSC Part Name 10uH ±20% 2.2A
L3: 3.3uH; IND-SMD_L2.0-W1.6_AOTA-B201610S3R3-101-T; Manufacturer Part AOTA-B201610S3R3-101-T; LCSC Part Name 3.3uH 2.4A
R2, R3: 5.1k; R_0402_1005Metric
R4: 523k; R_0402_1005Metric
R5, R6, R7, R23, R24: 100k; R_0402_1005Metric
R9, R10: 27ohm; R_0402_1005Metric
R12: 1M; R_0603_1608Metric
R14, R27: 10k; R_0402_1005Metric
R17: 33ohm; R_0402_1005Metric
R20, R25, R26, R28: 2.2k; R_0402_1005Metric
R21: 120ohm; R_0805_2012Metric
R22: 100k; R_0603_1608Metric
R_ILM1: 100k; R_0402_1005Metric
R_PR1_BOT1: 100k; R_0402_1005Metric
R_PR1_TOP1: 324k; R_0402_1005Metric
R_SHIELD1: 1M; R_0603_1608Metric
R_SHIELD_0R1: 0R DNP; R_0805_2012Metric
SW1: BOOTSEL; KEY-SMD_4P-L4.2-W3.2-P2.20-LS4.6; Manufacturer Part SKRPACE010; JLCPC# C139797
U1: RP2350A; QFN-60-1EP_7x7mm_P0.4mm_EP3.4x3.4mm; JLCPC# C42411118
U2: THVD1450DR; THVD1450DR-SOIC-8_L4.9-W3.9-P1.27-LS6.0-BL; JLCPC# C2671361
U3: ADXL355BEZ-RL7; JLCPC# C515892
U4: TPS2121RUXR; TPS2121RUXR-VQFN-HR-12_L2.5-W2.0-P0.50-BL; JLCPC# C485916
U5: USBLC6-2SC6; JLCPC# C7519
U6: TLV75733PDBVR; TLV75733PDBVR-SOT-23-5_L2.9-W1.6-P0.95-LS2.8-BL; Manufacturer Part TLV75733PDBVR; JLCPC# C485517
U7: W25Q128JVS; WSON-8_L6.0-W5.0-P1.27-BL-EP; Manufacturer Part W25Q128JVPIQ; LCSC Part Name 支持双路/四路SPI接口的3V、128Mbit 串行闪存
U8: TPS7A2033PDBVR; Manufacturer Part TPS7A2033PDBVR; JLCPC# C2862740
U_BUCK1: TPS62175DQCR; TPS62175DQCR_WSON-10_L3.0-W2.0-P0.50-BL-EP; Manufacturer Part TPS62175DQCR; LCSC C32097

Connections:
/1V1_CORE: C25.2, C26.1, L3.2, U1.6 (DVDD), U1.23 (DVDD), U1.39 (DVDD), U1.50 (VREG_FB)
/3V3_ADXL: C33.1, C34.2, C36.1, C37.2, FB1.2, R27.1, U3.5 (VDDIO), U3.11 (VSUPPLY)
/3V3_DIG: C16.1, C17.2, C18.1, C19.2, C20.2, C21.2, C22.2, C23.1, C24.2, C28.2, C29.1, R14.2, R17.1, U1.1 (IOVDD), U1.11 (IOVDD), U1.20 (IOVDD), U1.30 (IOVDD), U1.38 (IOVDD), U1.44 (ADC_AVDD), U1.45 (IOVDD), U1.49 (VREG_VIN), U1.53 (USB_OTP_VDD), U1.54 (QSPI_IOVDD), U2.8 (VCC), U6.5 (OUT), U7.8 (VCC)
/5V_BUCK: C7.1, C_IN1.2, L2.2, R4.2, R6.1, R7.1, R_PR1_TOP1.2, U4.7 (IN1), U_BUCK1.10 (VOS)
/5V_SYS: C13.2, C15.1, C31.1, C_OUT1.1, U4.1 (OUT), U4.8 (OUT), U6.1 (IN), U6.3 (EN), U8.1 (IN), U8.3 (EN)
/12V: F1.1, J_IN1.1 (12V), J_OUT1.1 (12V)
/ADXL_CS: R27.2, U1.13 (GPIO9), U3.1 (*CS/SCL)
/ADXL_DRDY: U1.16 (GPIO12), U3.14 (DRDY)
/ADXL_INT1: U1.18 (GPIO14), U3.12 (INT1)
/ADXL_INT2: U1.17 (GPIO13), U3.13 (INT2)
/ADXL_MISO: U1.12 (GPIO8), U3.4 (MISO/ASEL)
/ADXL_MOSI: U1.15 (GPIO11), U3.3 (MOSI/SDA)
/ADXL_SCLK: U1.14 (GPIO10), U3.2 (SCLK/VSSIO)
/CS: SW1.2, U1.60 (~QSPI_SS), U7.1 (#CS)
/DO: U1.59 (QSPI_SD1), U7.2 (DO/IO1)
/RS485_A: D4.2 (A2), J_IN1.4 (A), J_OUT1.4 (A), R21.1, U2.6 (A)
/RS485_B: D4.1 (A1), JP1.1 (A), J_IN1.3 (B), J_OUT1.3 (B), U2.7 (B)
/SHIELD: C_SHIELD1.2, J_IN1.5 (SHIELD), J_OUT1.5 (SHIELD), R_SHIELD1.2, R_SHIELD_0R1.2
/USB DN: J3.A7 (DN1), U5.3 (I/O2)
/USB DP: J3.A6 (DP1), U5.1 (I/O1)
/USB_DM: R10.1, U1.51 (USB_DM)
/USB_DP: R9.1, U1.52 (USB_DP)
/USB_VBUS: C_IN2.2, C_USB_BULK1.1, J3.A4 (VBUS), J3.A9 (VBUS), J3.B4 (VBUS), J3.B9 (VBUS), U4.2 (IN2), U5.5 (VBUS)
/WP: U1.58 (QSPI_SD2), U7.3 (#WP/IO2)
GND: C4.1, C5.1, C6.2, C7.2, C11.2, C13.1, C14.1, C15.2, C16.2, C17.1, C18.2, C19.1, C20.1, C21.1, C22.1, C23.2, C24.1, C25.1, C26.2, C27.2, C28.1, C29.2, C30.1, C31.2, C32.2, C33.2, C34.1, C35.1, C36.2, C37.1, C_IN1.1, C_IN2.1, C_OUT1.2, C_SHIELD1.1, C_USB_BULK1.2, D2.1 (A1), D3.1 (K), D4.3 (common), D5.1 (K), D6.1 (K), D7.1 (K), J3.A1 (GND), J3.A12 (GND), J3.B1 (GND), J3.B12 (GND), J_IN1.2 (GND), J_OUT1.2 (GND), R2.2, R3.2, R5.1, R12.2, R22.1, R23.1, R24.1, R_ILM1.2, R_PR1_BOT1.2, R_SHIELD1.1, R_SHIELD_0R1.1, SW1.1, U1.47 (VREG_PGND), U1.61 (GND), U2.5 (GND), U3.6 (VSSIO), U3.9 (VSS), U4.3 (CP2), U4.4 (OV2), U4.5 (OV1), U4.12 (GND), U5.2 (GND), U6.2 (GND), U7.4 (GND), U7.9 (EP), U8.2 (GND), U_BUCK1.1 (PGND), U_BUCK1.6 (AGND), U_BUCK1.11 (PAD)
unnamed: D1.2 (A), D2.2 (A2), F1.2
unnamed: C4.2, C5.2, C6.1, D1.1 (K), U_BUCK1.2 (VIN), U_BUCK1.3 (EN)
unnamed: D3.2 (A), R20.2
unnamed: D5.2 (A), R25.2
unnamed: D6.2 (A), R26.2
unnamed: D7.2 (A), R28.2
unnamed: J3.A5 (CC1), R2.1
unnamed: J3.B5 (CC2), R3.1
unnamed: C11.1, J3.0 (SHELL), R12.1
unnamed: JP1.2 (B), R21.2
unnamed: R9.2, U5.6 (I/O1)
unnamed: R10.2, U5.4 (I/O2)
unnamed: R26.1, U1.7 (GPIO4)
unnamed: R20.1, U1.8 (GPIO5)
unnamed: R28.1, U1.9 (GPIO6)
unnamed: R22.2, R25.1, U1.19 (GPIO15), U2.2 (~RE), U2.3 (DE)
unnamed: U1.27 (GPIO16), U2.1 (RO)
unnamed: U1.28 (GPIO17), U2.4 (DI)
unnamed: U1.56 (QSPI_SCLK), U7.6 (CLK)
unnamed: U1.57 (QSPI_SD0), U7.5 (DI/IO0)
unnamed: U1.55 (QSPI_SD3), U7.7 (#HOLD-OR-#REST/IO3)
unnamed: C27.1, R17.2, U1.46 (VREG_AVDD)
unnamed: L3.1, U1.48 (VREG_LX)
unnamed: C35.2, R24.2, U3.10 (V1P8ANA)
unnamed: C30.2, R23.2, U3.8 (V1P8DIG)
unnamed: R_ILM1.1, U4.10 (ILM)
unnamed: R_PR1_BOT1.1, R_PR1_TOP1.1, U4.6 (PR1)
unnamed: C14.2, U4.11 (SS)
unnamed: R14.1, U4.9 (ST)
unnamed: C32.1, FB1.1, U8.5 (OUT)
unnamed: R4.1, R5.2, U_BUCK1.5 (FB)
unnamed: R6.2, U_BUCK1.7 (PG)
unnamed: L2.1, U_BUCK1.9 (SW)
unnamed: R7.2, U_BUCK1.8 (~SLEEP)

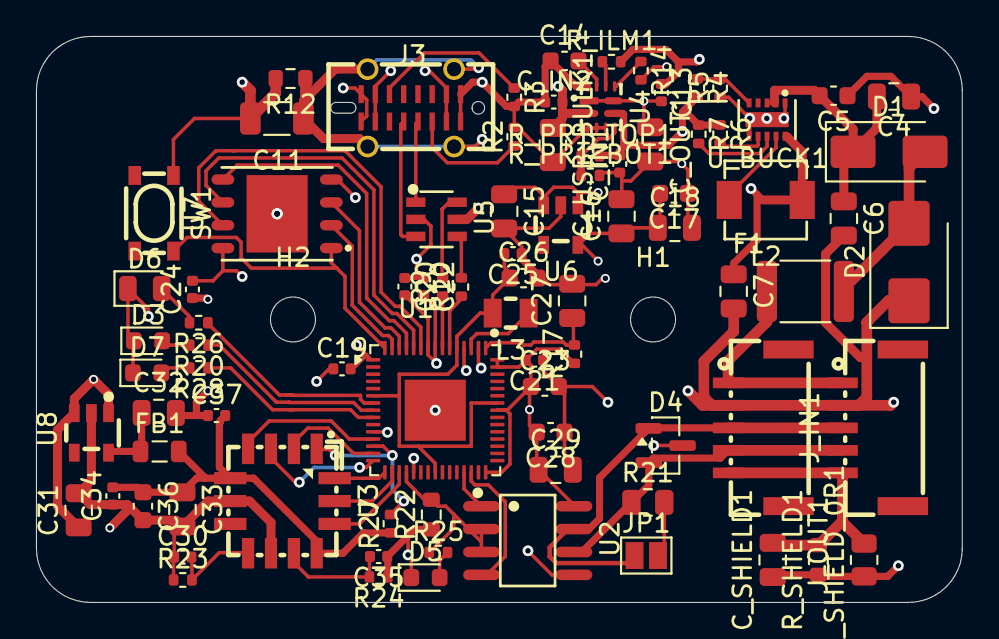
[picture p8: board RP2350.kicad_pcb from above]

Board: 4 copper layers, 51.4 x 31.4 mm, 87 parts (0 on the bottom side), 59 nets.

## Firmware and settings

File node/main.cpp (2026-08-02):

#include <stdio.h>

#include "pico/stdlib.h"
#include "pico/multicore.h"
#include "pico/rand.h"
#include "hardware/spi.h"
#include "hardware/watchdog.h"
#include "boards/pico.h"

#include "acquisition/acquisition_engine.h"
#include "adxl355/adxl355_driver.h"
#include "boot_shared/boot_shared_metadata_io.h"
#include "boot_shared/boot_runtime_api.h"
#include "config/config_manager.h"
#include "config/config_store_flash.h"
#include "config/board_profile.h"
#include "controller/node_controller.h"
#include "diagnostics/diagnostic_store.h"
#include "diagnostics/persistent_diagnostic_store.h"
#include "runtime/core0_acquisition_loop.h"
#include "runtime/core1_transport_loop.h"
#include "storage/acquisition_buffer.h"
#include "system/runtime_context.h"
#include "transport/data_plane.h"
#include "transport/rs485_port.h"
#include "transport/transport.h"

#define SPI_PORT   spi1
#define RS485_UART uart0

static constexpr uint32_t SAFE_BOOT_DELAY_MS = 5000;
static constexpr uint32_t WATCHDOG_TIMEOUT_MS = 3000;
static constexpr uint32_t SENSOR_SPI_BAUD = 5 * 1000 * 1000;
static constexpr uint32_t RS485_BAUD = 115200;
static constexpr size_t ACQ_BUFFER_CAPACITY = 8192;
static constexpr size_t PACKET_QUEUE_CAPACITY = 128;

using DataPlaneT = DataPlane<PACKET_QUEUE_CAPACITY, 32>;
using AcquisitionT = AcquisitionEngine<ACQ_BUFFER_CAPACITY>;
using ControllerT = NodeController<ACQ_BUFFER_CAPACITY>;
using TransportT = Transport<ACQ_BUFFER_CAPACITY, ControllerT>;
using RuntimeT = RuntimeContext<AcquisitionT, TransportT>;

static RuntimeT* g_runtime = nullptr;

static void init_status_led() {
    gpio_init(PICO_DEFAULT_LED_PIN);
    gpio_set_dir(PICO_DEFAULT_LED_PIN, GPIO_OUT);
    gpio_put(PICO_DEFAULT_LED_PIN, 0);
}

static void set_status_led(bool on) {
    gpio_put(PICO_DEFAULT_LED_PIN, on ? 1 : 0);
}

static void signal_starting() {
    for (uint32_t i = 0; i < 5; ++i) {
        set_status_led(true);
        sleep_ms(60);
        set_status_led(false);
        sleep_ms(60);
    }
}

static void setup_spi() {
    spi_init(SPI_PORT, SENSOR_SPI_BAUD);

    gpio_set_function(BoardProfile::kSpiMiso, GPIO_FUNC_SPI);
    gpio_set_function(BoardProfile::kSpiSck,  GPIO_FUNC_SPI);
    gpio_set_function(BoardProfile::kSpiMosi, GPIO_FUNC_SPI);

    spi_set_format(
        SPI_PORT,
        8,
        SPI_CPOL_0,
        SPI_CPHA_0,
        SPI_MSB_FIRST
    );
}

static void core1_entry() {
    multicore_lockout_victim_init();

    if (g_runtime != nullptr) {
        run_core1_transport_loop(*g_runtime);
    }

    while (true) {
        tight_loop_contents();
    }
}

static uint32_t packed_firmware_version() {
    return (static_cast<uint32_t>(FW_VERSION_MAJOR) << 16) |
           (static_cast<uint32_t>(FW_VERSION_MINOR) << 8) |
           static_cast<uint32_t>(FW_VERSION_PATCH);
}

int main() {
    stdio_init_all();
    multicore_lockout_victim_init();
    init_status_led();
    signal_starting();
    sleep_ms(SAFE_BOOT_DELAY_MS);

    printf("\n=== ADXL355 NODE START ===\n");
    printf(
        "board_profile=%s timestamping_v2=%s\n",
        BoardProfile::kName,
        BoardProfile::kTimestampingV2Enabled ? "enabled" : "disabled"
    );

    DiagnosticResetCause reset_cause = DiagnosticResetCause::PowerOn;
    if (watchdog_enable_caused_reboot()) {
        reset_cause = DiagnosticResetCause::WatchdogTimeout;
    } else if (watchdog_caused_reboot()) {
        reset_cause = DiagnosticResetCause::Watchdog;
    }

    watchdog_enable(WATCHDOG_TIMEOUT_MS, 1);

    setup_spi();

    static FlashConfigStore config_store;
    static ConfigManager config_manager(config_store);

    const bool loaded = config_manager.init();
    printf("config.init() -> %s\n", loaded ? "loaded" : "defaults");

    boot::BootMetadata boot_metadata{};
    const bool boot_metadata_loaded = boot::app_boot_metadata_load(boot_metadata);

    static PersistentDiagnosticStore persistent_diagnostics;
    static DiagnosticStore diagnostics;
    diagnostics.set_reset_cause(reset_cause);
    diagnostics.set_persistent_store(&persistent_diagnostics);
    diagnostics.set_boot_counter(boot_metadata_loaded ? boot_metadata.boot_counter : 0u);
    diagnostics.set_firmware_version(packed_firmware_version());
    diagnostics.record(
        DiagnosticSeverity::Info,
        DiagnosticEventCode::Boot,
        0,
        static_cast<int32_t>(reset_cause),
        static_cast<int32_t>(WATCHDOG_TIMEOUT_MS)
    );

    static AcquisitionBuffer<ACQ_BUFFER_CAPACITY> acq_buffer;
    static Adxl355Driver driver(
        SPI_PORT,
        BoardProfile::kSpiCs,
        BoardProfile::kDrdy,
        BoardProfile::kInt1,
        BoardProfile::kTimestampingV2Enabled
    );
    static DataPlaneT data_plane;
    uint64_t boot_epoch = get_rand_64();
    if (boot_epoch == 0) {
        boot_epoch = 1;
    }
    data_plane.configure_timing(
        boot_epoch,
        BoardProfile::kTimestampingV2Enabled
    );
    static AcquisitionT acquisition(driver, acq_buffer, &data_plane, &diagnostics);

    static Rs485Port rs485_port(
        RS485_UART,
        BoardProfile::kRs485Tx,
        BoardProfile::kRs485Rx,
        RS485_BAUD,
        BoardProfile::kRs485De
    );

    if (!rs485_port.init()) {
        printf("rs485_port.init() failed\n");
        diagnostics.record_fault(
            DiagnosticSeverity::Critical,
            DiagnosticEventCode::Rs485InitFailed,
            DiagnosticFaultContext{}
        );
        set_status_led(false);
        while (true) {
            sleep_ms(100);
        }
    }

    static ControllerT controller(
        config_manager,
        acquisition,
        driver,
        data_plane,
        &rs485_port,
        &diagnostics
    );

    const bool controller_ready = controller.init();
    if (!controller_ready) {
        printf("controller.init() failed, status=%d\n",
               static_cast<int>(controller.init_status()));
    }

    const auto cfg = config_manager.current();
    const uint32_t output_odr_millihz =
        (static_cast<uint32_t>(cfg.odr_hz) * 1000u) /
        DecimatingFilterX2::kDecimationFactor;

    printf(
        "CONFIG: node_id=%u baud=%lu sensor_odr=%u output_odr=%lu.%03lu range=%u high_pass_corner=%u offsets=(%ld,%ld,%ld) fifo_watermark_entries=%u fifo_watermark_xyz=%u\n",
        static_cast<unsigned>(cfg.node_id),
        static_cast<unsigned long>(cfg.baudrate),
        static_cast<unsigned>(cfg.odr_hz),
        static_cast<unsigned long>(output_odr_millihz / 1000u),
        static_cast<unsigned long>(output_odr_millihz % 1000u),
        static_cast<unsigned>(cfg.range_g),
        static_cast<unsigned>(cfg.high_pass_corner),
        static_cast<long>(cfg.offset_x),
        static_cast<long>(cfg.offset_y),
        static_cast<long>(cfg.offset_z),
        static_cast<unsigned>(cfg.fifo_watermark),
        static_cast<unsigned>(cfg.fifo_watermark / 3u)
    );

    static RuntimeT runtime{};
    runtime.acquisition = controller_ready ? &acquisition : nullptr;
    runtime.core1_ready = false;
    runtime.stop_requested = false;
    runtime.requested_action = RuntimeSystemActionNone;

    static TransportT transport(
        rs485_port,
        controller,
        data_plane,
        &runtime.requested_action,
        boot_epoch,
        BoardProfile::kTimestampingV2Enabled
    );

    if (!transport.init()) {
        printf("transport.init() failed\n");
        diagnostics.record_fault(
            DiagnosticSeverity::Critical,
            DiagnosticEventCode::TransportInitFailed,
            DiagnosticFaultContext{}
        );
        set_status_led(false);
        while (true) {
            sleep_ms(100);
        }
    }

    g_runtime = &runtime;
    runtime.transport = &transport;
    multicore_launch_core1(core1_entry);

    while (!runtime.core1_ready) {
        sleep_ms(1);
    }

    const bool boot_confirmed = controller_ready
        ? boot::app_confirm_boot_success()
        : false;
    // Never copy defaults from a failed configuration load into boot
    // metadata.  In particular, a failed trial must not change the
    // bootloader maintenance address to UNASSIGNED_NODE_ID.
    const bool boot_settings_synced = controller_ready && loaded
        ? boot::app_sync_boot_settings(config_manager.current().node_id)
        : false;

    printf("boot.sync() -> %s, boot.confirm() -> %s\n",
           boot_settings_synced ? "ok" : "skip/fail",
           boot_confirmed ? "confirmed" :
               (controller_ready ? "not_pending" : "blocked_not_ready"));

    printf("core0=acquisition, core1=transport\n");
    set_status_led(controller_ready);

    run_core0_acquisition_loop(runtime);

    return 0;
}

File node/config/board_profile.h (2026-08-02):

#pragma once

#include <cstdint>

#define SENSOR_BOARD_REVISION_V2 1
#define SENSOR_BOARD_REVISION_V1 2

#ifndef SENSOR_SYSTEM_BOARD_PROFILE
#define SENSOR_SYSTEM_BOARD_PROFILE SENSOR_BOARD_REVISION_V2
#endif

#ifndef SENSOR_TIMESTAMPING_V2_ENABLED
#define SENSOR_TIMESTAMPING_V2_ENABLED 0
#endif

namespace BoardProfile {

#if SENSOR_SYSTEM_BOARD_PROFILE == SENSOR_BOARD_REVISION_V2
static constexpr const char* kName = "board_v2";
static constexpr uint8_t kRevision = 2;
static constexpr uint8_t kSpiMiso = 12;
static constexpr uint8_t kSpiCs = 13;
static constexpr uint8_t kSpiSck = 14;
static constexpr uint8_t kSpiMosi = 15;
static constexpr int8_t kDrdy = 11;
static constexpr int8_t kInt1 = 10;
static constexpr int8_t kRs485De = -1;
#elif SENSOR_SYSTEM_BOARD_PROFILE == SENSOR_BOARD_REVISION_V1
static constexpr const char* kName = "board_v1";
static constexpr uint8_t kRevision = 1;
static constexpr uint8_t kSpiMiso = 12;
static constexpr uint8_t kSpiCs = 13;
static constexpr uint8_t kSpiSck = 10;
static constexpr uint8_t kSpiMosi = 11;
static constexpr int8_t kDrdy = 14;
static constexpr int8_t kInt1 = 15;
static constexpr int8_t kRs485De = 2;
#else
#error "Unknown SENSOR_SYSTEM_BOARD_PROFILE"
#endif

static constexpr uint8_t kRs485Tx = 0;
static constexpr uint8_t kRs485Rx = 1;
static constexpr bool kTimestampingV2Enabled =
    SENSOR_TIMESTAMPING_V2_ENABLED != 0;

static_assert(kSpiMiso != kSpiCs, "SPI MISO and CS pins conflict");
static_assert(kSpiMiso != kSpiSck, "SPI MISO and SCK pins conflict");
static_assert(kSpiMiso != kSpiMosi, "SPI MISO and MOSI pins conflict");
static_assert(kSpiCs != kSpiSck, "SPI CS and SCK pins conflict");
static_assert(kSpiCs != kSpiMosi, "SPI CS and MOSI pins conflict");
static_assert(kSpiSck != kSpiMosi, "SPI SCK and MOSI pins conflict");
static_assert(kDrdy < 0 || (
    kDrdy != static_cast<int8_t>(kSpiMiso) &&
    kDrdy != static_cast<int8_t>(kSpiCs) &&
    kDrdy != static_cast<int8_t>(kSpiSck) &&
    kDrdy != static_cast<int8_t>(kSpiMosi)
), "DRDY pin conflicts with SPI");
static_assert(kInt1 < 0 || (
    kInt1 != static_cast<int8_t>(kSpiMiso) &&
    kInt1 != static_cast<int8_t>(kSpiCs) &&
    kInt1 != static_cast<int8_t>(kSpiSck) &&
    kInt1 != static_cast<int8_t>(kSpiMosi)
), "INT1 pin conflicts with SPI");
static_assert(kDrdy < 0 || kInt1 < 0 || kDrdy != kInt1,
              "DRDY and INT1 pins conflict");

}  // namespace BoardProfile

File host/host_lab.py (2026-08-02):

#!/usr/bin/env python3
from __future__ import annotations

import argparse
import json
import math
import os
import struct
import sys
import time
from dataclasses import dataclass, replace
from pathlib import Path
from typing import Optional

import serial


FRAME_MAGIC = 0xAA55
FRAME_PROTOCOL_VERSION = 2
FRAME_HEADER_FORMAT = "<HBBBBBHI"
FRAME_HEADER_SIZE = struct.calcsize(FRAME_HEADER_FORMAT)
FRAME_CRC_SIZE = 2
FRAME_MAX_PAYLOAD_SIZE = 1024

FRAME_TYPE_DATA = 0x01
FRAME_TYPE_COMMAND = 0x02
FRAME_TYPE_RESPONSE = 0x03

HOST_NODE_ID = 0xFE

CMD_PING = 0x01
CMD_GET_CONFIG = 0x20
CMD_SET_ODR = 0x22
CMD_SET_HIGH_PASS = 0x2C
CMD_SET_FIFO_WATERMARK = 0x25
CMD_SAVE_CONFIG = 0x26
CMD_SET_BAUD_RATE = 0x29
CMD_GET_TEMPERATURE = 0x41
CMD_GET_BUFFER_STATE = 0x42
CMD_GET_STATS = 0x43
CMD_GET_CAPABILITIES = 0x4A
CMD_TIME_SYNC = 0x4B
CMD_GRANT_BURST_READ = 0x52
CMD_COMMIT_READ_UP_TO = 0x53

STATUS_OK = 0x00
STATUS_NO_DATA = 0x06

SAMPLE_ENCODING_RAW_XYZ24 = 0x01
SAMPLE_ENCODING_RAW_XYZ24_TIME_V2 = 0x02
TIMING_FORMAT_VERSION_V2 = 0x02
TIMING_QUALITY_INVALID = 1 << 2
CAPABILITY_BURST_TIME_V2 = 1 << 0
CAPABILITY_TIME_SYNC_V1 = 1 << 1
SAMPLES_PER_PACKET = 32

BUFFER_STATE_FORMAT_V1 = "<BBQQIIIQQQIII"
BUFFER_STATE_FORMAT = BUFFER_STATE_FORMAT_V1 + "I"
STATS_FORMAT_V1 = "<BBQ" + ("I" * 12)
STATS_FORMAT_V2 = "<BBQ" + ("I" * 12) + "Q" + ("I" * 3)
STATS_FORMAT_V3 = "<BBQ" + ("I" * 12) + "Q" + ("I" * 9)
STATS_FORMAT_V4 = "<BBQ" + ("I" * 14) + "Q" + ("I" * 9)
STATS_FORMAT_V5 = STATS_FORMAT_V4 + ("I" * 3)
STATS_FORMAT_V6 = STATS_FORMAT_V5 + ("I" * 4)
STATS_FORMAT_V7 = STATS_FORMAT_V6 + ("I" * 4)
STATS_FORMAT_V8 = STATS_FORMAT_V7 + ("I" * 4)
GRANT_BURST_RESPONSE_FORMAT = "<BBQH"
COMMIT_READ_RESPONSE_FORMAT = "<BBQ"
BURST_HEADER_FORMAT = "<BBIQHB"
BURST_TIMING_V2_FORMAT = "<BBHQIQQII"
GET_CAPABILITIES_FORMAT = "<BBBBIH"
TIME_SYNC_COMMAND_FORMAT = "<BBIQ"
TIME_SYNC_RESPONSE_FORMAT = "<BBBIQQQQ"
PACKET_FRAME_BYTES = FRAME_HEADER_SIZE + struct.calcsize(BURST_HEADER_FORMAT) + (SAMPLES_PER_PACKET * 9) + FRAME_CRC_SIZE
CONTROL_RESPONSE_BYTES = FRAME_HEADER_SIZE + 16 + FRAME_CRC_SIZE
GET_CONFIG_FORMAT_V1 = "<BBBIHBiiiBHBB"
GET_CONFIG_FORMAT_V2 = "<BBBIHBiiiBHBBBBIQ"
GET_CONFIG_FORMAT = GET_CONFIG_FORMAT_V2 + "B"
GET_TEMPERATURE_FORMAT = "<BBHf"

SUPPORTED_ODR_HZ = (
    4000,
    2000,
    1000,
    500,
    250,
    125,
    # Lower ADXL355 ODR values are intentionally disabled in host commands
    # until firmware support is wired end-to-end and verified on hardware.
    # 62.5,
    # 31.25,
    # 15.625,
    # 7.813,
    # 3.906,
    # 1.953,
    # 0.977,
)
SUPPORTED_HIGH_PASS_CORNERS = tuple(range(0, 8))
SUPPORTED_FIFO_WATERMARKS = tuple(range(3, 97, 3))
SUPPORTED_BAUD_RATES = (
    9600,
    19200,
    38400,
    57600,
    115200,
    # Higher baudrates are intentionally disabled in host commands until
    # firmware support is wired end-to-end and verified on hardware.
    # 230400,
    # 460800,
    # 921600,
    # 1000000,
    # 1500000,
    # 2000000,
)
OUTPUT_DECIMATION_FACTOR = 2
SUPPORTED_OUTPUT_ODR_HZ = tuple(
    value / float(OUTPUT_DECIMATION_FACTOR) for value in SUPPORTED_ODR_HZ
)


def crc16_ccitt(data: bytes) -> int:
    crc = 0xFFFF
    for byte in data:
        crc ^= (byte << 8) & 0xFFFF
        for _ in range(8):
            if crc & 0x8000:
                crc = ((crc << 1) ^ 0x1021) & 0xFFFF
            else:
                crc = (crc << 1) & 0xFFFF
    return crc


def load_json_config(path: Path) -> dict:
    if not path.exists():
        return {}

    with path.open("r", encoding="utf-8") as handle:
        return json.load(handle)


@dataclass
class Frame:
    frame_type: int
    flags: int
    destination: int
    source: int
    sequence: int
    payload: bytes


@dataclass
class BufferState:
    command: int
    status: int
    oldest_seq: int
    newest_seq: int
    stored_samples: int
    capacity_samples: int
    overwrite_count: int
    oldest_packet_first_seq: int
    newest_packet_last_seq: int
    committed_sample_seq: int
    queued_packets: int
    packet_capacity: int
    packet_overwrite_count: int
    encoding_saturation_count: int = 0


@dataclass
class NodeStats:
    command: int
    status: int
    next_sample_seq: int
    pushed_samples: int
    dropped_samples: int
    sample_buffer_overwrite_count: int
    update_calls: int
    fifo_reads: int
    fifo_no_data: int
    sensor_errors: int
    fifo_irq_events: int
    fifo_batches: int
    fifo_samples_read: int
    fifo_int1_events: int = 0
    fifo_drdy_events: int = 0
    rx_overflow_count: int = 0
    packet_overwrite_count: int = 0
    last_sample_seq: int = 0
    last_progress_ms: int = 0
    consecutive_no_data_reads: int = 0
    consecutive_sensor_errors: int = 0
    fifo_poll_fallback_reads: int = 0
    no_data_with_irq: int = 0
    no_data_without_irq: int = 0
    soft_recover_count: int = 0
    last_irq_event_ms: int = 0
    last_soft_recover_ms: int = 0
    gpio_int1_edges: int = 0
    gpio_drdy_edges: int = 0
    debug_config_snapshot: int = 0
    irq_status_not_full: int = 0
    irq_fifo_entries_lt_3: int = 0
    irq_fifo_entries_lt_watermark: int = 0
    debug_irq_snapshot: int = 0
    spurious_int1_events: int = 0
    fifo_overrun_events: int = 0
    fifo_discarded_samples: int = 0
    fifo_uncertain_loss_events: int = 0
    drdy_timestamp_ring_overflow: int = 0
    timing_binding_mismatch: int = 0
    timing_binding_invalidations: int = 0
    timing_segment_id: int = 0


@dataclass
class BurstPacket:
    packet_seq: int
    first_sample_seq: int
    sample_count: int
    payload: bytes
    sample_encoding: int = SAMPLE_ENCODING_RAW_XYZ24
    sample_payload_offset: int = struct.calcsize(BURST_HEADER_FORMAT)
    timing_format_version: int = 0
    timestamp_source: int = 0
    timestamp_quality_flags: int = TIMING_QUALITY_INVALID
    boot_epoch: int = 0
    timing_segment_id: int = 0
    first_device_time_us: int = 0
    last_device_time_us: int = 0
    sample_period_q16_us: int = 0
    max_fit_residual_us: int = 0

    def device_time_us_for_index(self, index: int) -> int | None:
        if index < 0 or index >= self.sample_count:
            raise IndexError(index)
        if self.sample_encoding != SAMPLE_ENCODING_RAW_XYZ24_TIME_V2:
            return None
        if self.timestamp_quality_flags & TIMING_QUALITY_INVALID:
            return None
        if self.sample_count == 1:
            return self.first_device_time_us
        interval = self.last_device_time_us - self.first_device_time_us
        return self.first_device_time_us + (interval * index) // (self.sample_count - 1)


@dataclass
class NodeCapabilities:
    command: int
    status: int
    capabilities_version: int
    burst_format_max: int
    feature_flags: int
    max_samples_per_packet: int


@dataclass
class TimeSyncResponse:
    command: int
    status: int
    version: int
    sync_id: int
    boot_epoch: int
    echoed_t1_host_monotonic_ns: int
    t2_node_rx_us: int
    t3_node_tx_us: int
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

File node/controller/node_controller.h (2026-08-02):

#pragma once

#include <cstddef>
#include <cstdint>
#include <cstring>

#include "acquisition/acquisition_engine.h"
#include "boot_shared/boot_runtime_api.h"
#include "common/device_identity.h"
#include "config/board_profile.h"
#include "common/node_types.h"
#include "common/protocol_ids.h"
#include "common/sensor_types.h"
#include "config/config_manager.h"
#include "diagnostics/diagnostic_store.h"
#include "interfaces/i_data_plane.h"
#include "interfaces/i_temperature_sensor.h"
#include "pico/time.h"
#include "storage/stored_sample.h"
#include "transport/command_payloads.h"
#include "transport/command_types.h"
#include "transport/frame_types.h"
#include "transport/rs485_port.h"
#include "transport/status_codes.h"

template <size_t BufferCapacity>
class NodeController {
public:
    enum class DeferredAction : uint8_t {
        None = 0,
        Restart,
        EnterBootloader,
        ApplyBaudRate
    };

    NodeController(ConfigManager& config,
                   AcquisitionEngine<BufferCapacity>& acquisition,
                   ITemperatureSensor& temperature_sensor,
                   IDataPlane& data_plane,
                   Rs485Port* rs485_port = nullptr,
                   DiagnosticStore* diagnostics = nullptr)
        : config_(config),
          acquisition_(acquisition),
          temperature_sensor_(temperature_sensor),
          data_plane_(data_plane),
          rs485_port_(rs485_port),
          diagnostics_(diagnostics) {
    }

    bool init() {
        const auto st = acquisition_.init(config_.current());
        init_status_ = st;
        config_revision_ = config_.generation();
        config_effective_sample_seq_ = acquisition_.stats().next_sample_seq;
        if (diagnostics_ != nullptr) {
            if (st == SensorStatus::Ok) {
                diagnostics_->record(
                    DiagnosticSeverity::Info,
                    DiagnosticEventCode::ControllerInitOk,
                    0,
                    static_cast<int32_t>(config_.current().node_id),
                    0
                );
            } else {
                diagnostics_->record_fault(
                    DiagnosticSeverity::Error,
                    DiagnosticEventCode::ControllerInitFailed,
                    current_fault_context(static_cast<int32_t>(st), 0)
                );
            }
        }
        return st == SensorStatus::Ok;
    }

    SensorStatus init_status() const {
        return init_status_;
    }

    uint8_t node_id() const {
        return config_.current().node_id;
    }

    bool is_unassigned() const {
        return config_.current().node_id == UNASSIGNED_NODE_ID;
    }

    bool accepts_broadcast_command(const uint8_t* payload, size_t payload_len) const {
        if (payload == nullptr || payload_len < 1) {
            return false;
        }

        switch (static_cast<CommandType>(payload[0])) {
            case CommandType::CommissionDiscover:
            case CommandType::CommissionAssignNodeId:
                return is_unassigned();
            default:
                return false;
        }
    }

    DeferredAction take_deferred_action() {
        const DeferredAction action = deferred_action_;
        deferred_action_ = DeferredAction::None;
        return action;
    }

    uint32_t take_deferred_baudrate() {
        const uint32_t baudrate = deferred_baudrate_;
        deferred_baudrate_ = 0;
        return baudrate;
    }

    StatusCode handle_command(uint8_t command,
                              uint8_t source,
                              const uint8_t* payload,
                              size_t payload_len,
                              uint8_t* response,
                              size_t& response_len) {
        response_len = 0;

        switch (static_cast<CommandType>(command)) {
            case CommandType::Ping:
                return build_simple_ok(command, response, response_len);

            case CommandType::Restart:
                return handle_restart(response, response_len);

            case CommandType::EnterBootloader:
                return handle_enter_bootloader(response, response_len);

            case CommandType::GetVersion:
                return handle_get_version(response, response_len);

            case CommandType::RunSelfTest:
                return handle_run_self_test(response, response_len);

            case CommandType::GetConfig:
                return handle_get_config(response, response_len);

            case CommandType::SetNodeId:
                return handle_set_node_id(payload, payload_len, response, response_len);

            case CommandType::SetOdr:
                return handle_set_odr(payload, payload_len, response, response_len);

            case CommandType::SetRange:
                return handle_set_range(payload, payload_len, response, response_len);

            case CommandType::SetHighPass:
                return handle_set_high_pass(payload, payload_len, response, response_len);

            case CommandType::SetOffsets:
                return handle_set_offsets(payload, payload_len, response, response_len);

            case CommandType::SetFifoWatermark:
                return handle_set_fifo_watermark(payload, payload_len, response, response_len);

            case CommandType::SetBaudRate:
                return handle_set_baudrate(payload, payload_len, response, response_len);

            case CommandType::CommissionDiscover:
                return handle_commission_discover(payload, payload_len, response, response_len);

            case CommandType::CommissionAssignNodeId:
                return handle_commission_assign(payload, payload_len, response, response_len);

            case CommandType::SaveConfig:
                return handle_save_config(response, response_len);

            case CommandType::LoadConfig:
                return handle_load_config(response, response_len);

            case CommandType::ResetConfigToDefaults:
                return handle_reset_config_to_defaults(response, response_len);

            case CommandType::GetStatus:
                return handle_get_status(response, response_len);

            case CommandType::GetBufferState:
                return handle_get_buffer_state(response, response_len);

            case CommandType::GetStats:
                return handle_get_stats(response, response_len);

            case CommandType::GetTemperature:
                return handle_get_temperature(response, response_len);

            case CommandType::GetDiagnosticInfo:
                return handle_get_diagnostic_info(response, response_len);

            case CommandType::GetFaultSnapshot:
                return handle_get_fault_snapshot(response, response_len);

            case CommandType::ReadDiagnosticEvents:
                return handle_read_diagnostic_events(payload, payload_len, response, response_len);
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

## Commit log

2026-05-22 Update ADXL355 pin mapping
2026-05-22 Update host config for current hardware
2026-05-30 hardware: add KiCad project and collaboration notes
    [RP2350.kicad_pcb, RP2350.kicad_sch]
2026-05-30 KiCad: J1 terminal update
    [RP2350.kicad_pcb, RP2350.kicad_sch]
2026-05-30 hardware: added net classes
    [RP2350.kicad_pcb, RP2350.kicad_sch]
2026-05-30 hardware: 2 terminals fix
    [RP2350.kicad_pcb, RP2350.kicad_sch]
2026-05-30 hardware: layout progress + many footprints
    [RP2350.kicad_pcb]
2026-05-30 hardware: holly f
    [RP2350.kicad_pcb, RP2350.kicad_sch]
2026-05-31 hardware: train update
    [RP2350.kicad_pcb]
2026-05-31 hardware: 3v3_dig, 1vcore
    [RP2350.kicad_pcb, RP2350.kicad_sch]
2026-05-31 hardware: new layout
    [RP2350.kicad_pcb, RP2350.kicad_sch]
2026-06-01 hardware: ERC fixes, PWR_FLAG, and net labels
    [RP2350.kicad_sch]
2026-06-01 hardware: layout updates
    [RP2350.kicad_pcb, RP2350.kicad_sch]
2026-06-01 hardware: ERC fixes, PWR_FLAG, and net labels pt.2
    [RP2350.kicad_sch]
2026-06-01 hardware: restored good schema with labels and pwr_flags
    [RP2350.kicad_sch]
2026-06-01 work in progress
    [RP2350.kicad_pcb]
2026-06-01 hardware: pico pin change, moved mounting holes
    [RP2350.kicad_pcb, RP2350.kicad_sch]
2026-06-01 hardware: added footprints, part numbers, layout update
    [RP2350-B_Mask.gbr, RP2350-B_Paste.gbr, RP2350-B_Silkscreen.gbr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]
2026-07-06 Snapshot current host diagnostics state before node diag work
2026-07-06 Integrate node hardware and host tooling updates
    [RP2350.kicad_pcb, RP2350.kicad_sch]
2026-07-08 Add sensor diagnostics and IRQ recovery telemetry
2026-07-09 Harden ADXL355 FIFO diagnostics and safe release flow
2026-07-26 Harden sensor supervisor runtime logging
2026-07-27 Document DRDY timing and update board pin map
2026-07-27 Add DRDY sample timestamping protocol v2
2026-07-27 Quarantine uncertain acquisition-time samples
2026-08-02 Unify board revisions, runtime paths, and diagnostics
2026-08-02 Correct V2 pin profile and validate field update
    [board_profile.h, host_bootloader.py, host_channel_control.py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]
2026-08-20 Harden recorder storage and update hardware projects
    [.step, 3d_model.step, BOM.csv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]
2026-10-11 docs(v2): record Raspberry Pi multi-channel baseline
2026-10-11 fix(host-v2): support Linux filesystem probe
2026-10-12 docs(v2): add Raspberry Pi session handoff
2026-10-13 feat(v2): bound safe-state wire recovery
2026-10-13 docs(v2): define service interruption policy
2026-10-19 fix(host-v2): isolate channels and expose sample loss
2026-10-19 fix(node): reconcile interrupted commissioning
2026-10-20 feat(v2): expose node temperature in dashboard
2026-10-28 fix(host-v2): publish current node boot epoch
